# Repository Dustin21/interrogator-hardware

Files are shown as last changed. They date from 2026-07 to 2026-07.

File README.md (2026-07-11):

# interrogator-hardware

**Proprietary & Confidential — © 2026 Dustin. All Rights Reserved.**

Hardware design repo for the [Reality Interrogator](https://github.com/Dustin21/interrogator): the custom PCB(s), enclosure/chassis, footprint & 3D asset library, fabrication packages, and the contract-driven design pipeline that regenerates them when the sensor set changes.

> Status: **planning — v0.1 plan under owner review.** See [`PLAN.md`](PLAN.md) (the build plan) and [`docs/draft-review.md`](docs/draft-review.md) (audit of the original brief vs the interrogator repo + 2026 tooling research).

## Relationship to `interrogator` (the contract)

- The **Unified Sensor Registry** (`interrogator: shared/schemas/sensors/*.yaml`, ADR-0013) is the single source of truth for per-sensor identity/electrical/mechanical facts and versioned asset pins. This repo **consumes it at a pinned SHA — never forks or edits it**.
- This repo binds read-only to the `electrical` + `mechanical` facets and `assets` pins; per-instance placement binds to the device profile view.
- Findings that should change upstream facts are delivered as **resolution packets** (PR-ready proposals); the owner applies them upstream. Single-writer discipline is preserved.
- Heavy binaries (footprints, 3D models, gerbers, renders) live **locally in-tree for now, migrating to AWS S3** (versioned bucket, S3-generic access layer), referenced by `{asset_id, version, sha256}` in a checked-in manifest — the same AssetPin discipline as datasheets. No Git LFS.
- This repo's CI = ERC/DRC (`kicad-cli`), asset-checksum, and contract-pin drift checks. Upstream CI (pytest/contract) is untouched.

## Design stance

**Commercial hardware, clean sheet, chip-down** ([`PLAN.md`](PLAN.md) §0.1): raw sensor silicon on our own board — no breakouts, no dev modules; pre-certified modules only where commercially correct (radio, GNSS). The upstream *contract* binds (registry facets, wire/command semantics); the breadboard *prototype* does not — **interrogator adapts its firmware to this design** against the interface-requirements doc published at H1, and the backend stacks on top. Reference architecture: two-domain compute (NPU-class application MCU + always-on pre-certified BLE/sentinel module), PLAN §5.1.

## Definition of done for the v1 board

(a) The owner's spec scorecard (PLAN §1, R1–R12) against the built device; then (b) the joint integration milestone — the upstream **PCB Gate, [interrogator#7](https://github.com/Dustin21/interrogator/issues/7)**: e2e re-validated on PCB · binary IDL live with text debug mode · diagnostics no-regression vs the breadboard golden baseline · latency budget met.

## Layout (will grow per PLAN.md §7 phases)

| Path | Contents |
|---|---|
| `PLAN.md` | The hardware build plan (source of truth for this repo). |
| `docs/draft-review.md` | Audit: original brief vs interrogator repo + July-2026 EDA tooling research. |
| `docs/MISSING_VENDOR_ASSETS.md` | Proxy-blocked vendor files with exact URLs for manual retrieval. |
| `docs/decisions/` | Lightweight ADRs — the design rationale + invention-capture log. |
| `contract/upstream/` | Pinned, read-only USR snapshot (`PIN.json` records the interrogator commit). |
| `contract/scripts/` | Stage-1 pipeline: `ingest.py` (→ `io_map.{json,md}`), `gen_usr3_packets.py`. |
| `contract/usr3_packets/` | Per-sensor electrical resolution packet drafts (the ingest-package input). |
| `contract/tests/` | Pytest suite — the CI gate. |
| `assets/` | AssetPin manifest + tool (sha256 ledger; local/device now → AWS S3, D10). |
| `library/` | Verified symbols/footprints/3D with AssetPins. *(H2)* |
| `boards/v1/` | KiCad project, fab packages, bring-up docs. *(H2+; CI ERC/DRC auto-activates)* |
| `enclosure/` | FreeCAD/STEP chassis, aperture plate. *(H5)* |

## Toolchain (pinned at H0)

KiCad 10.0.x (`kicad-cli` for ERC/DRC/exports + jobsets) · easyeda2kicad / SnapMagic / Ultra Librarian for verified footprints · Freerouting 2.2.x (grunt nets only, `-inc`-protected) · kicad-jlcpcb-tools for fab packages · FreeCAD + StepUp for MCAD co-design. Trust boundaries in [`PLAN.md`](PLAN.md) §6.2.

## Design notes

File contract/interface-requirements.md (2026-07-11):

# Interface requirements -> interrogator firmware project (v1 hardware)

The board this repo is building; firmware adapts to this (owner-ratified flow).

1. **Compute**: STM32N657 (app, ESP-class port replaced by STM32 port; Neural-ART available) + nRF54L15 module (sentinel, Zephyr/nRF Connect). Inter-MCU: UART (CRC8 framing may carry over) + shared GPIO wake lines.
2. **Buses**: VL53L8CH + BNO086 on SPI+DMA w/ INT; I2C-A (MLX90642, MAX30102, AS7058, ADS131M04-SPI actually -> ADS on SPI2); I2C-B (BME688, SGP41, BMV080, TCS3448, AS7331, MMC5983MA, TMAG5273, IQS7222A); I3C capable pins reserved. GNSS on UART+PPS to input-capture. Wi-Fi via SDIO (ESP-Hosted-MCU).
3. **INT/data-ready wired for every sensor that has one**; FIFO watermark reads; GPS-PPS disciplined timestamps (utc = monotonic + gps_offset contract preserved).
4. **Power domains** (firmware-controlled load switches): OPTICAL, AIR(+fan), CONTACT, RF-WIFI, GNSS, RADAR. Ambient = sentinel + duty-cycled N657. Command surface should map SET_*_RATE + domain on/off.
5. **Wire contract**: binary IDL (ADR-0004) target; text debug mode; ~25-100 KB/s budget unchanged; BLE control plane + Wi-Fi bulk (WebRTC-class transport terminated app-side).
6. **Sensor set deltas** (ingest package to registry): MLX90642, VL53L8CH, TCS3448, BNO086, MMC5983MA, MIA_M10Q, IQS7222A, ADS131M04, AS7058 new records; AMG8833/AS7263/MPR121/NEO_M9N/ADS1115/VL53L8CX/AS7343/BNO085 deprecated-by-successor.
7. **OTA**: A/B slots, signed images, sentinel-rooted identity; feature-gate hooks.

## 8. Interference matrix handoff (owner Q 2026-07-11)
The interference matrix (docs/interference-matrix.yaml) is a physical property of THIS board —
authored here, ENFORCED in interrogator. Ships downstream via the ingest package, referenced by
the device profile (single-sourced; firmware/edge LOAD it, never hardcode) so it can't drift.

Two consumers, routed by each rule's enforcement_tier:
- **firmware_reflex** (sub-100ms, deterministic): tdm / mutex / stagger / gate — emitter↔receiver
  TDM, haptic↔precision mutex, MMC↔TMAG stagger, WiFi-gate during GNSS RAWX. Firmware must load
  these + emit state flags per record.
- **edge_policy** (active-sensing agent): scheduling that avoids masking interactions + confidence
  weighting from flags; may also deliberately exploit couplings (active illumination).
- **design_time** (not runtime): material_exclusion, light_tight_cavity, dedicated_aperture,
  spread_spectrum, shield, keepout, zoning, cal — owned by HW/materials/factory, listed for traceability.

### Record-schema delta interrogator must add (ADR-0001)
State flags ride every record for downstream confidence weighting. Existing prototype flags:
motors_active, wifi_active, leds_active, valve_active. **New for v1: `charging`, `docked`,
`haptic_active`, `uv_active`.** These are the ingest-package's schema asks; we specify, upstream lands.

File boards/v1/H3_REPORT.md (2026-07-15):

# H3 report — rail ECOs, floorplan repack, board rebuild, routing

**Date started:** 2026-07-12 · Grows stage by stage (H3.0 rail ECOs →
H3.1 repack → H3.2 board rebuild → H3.3 routing).

## H3.0 — rail ECOs (1.8V IO architecture + flagged ECO-H3 items)

### H3.0-1 · 1.8V IO architecture decision

**Question:** can the shared sensor SPI bus (SPI1: VL53L8CH, A121, BNO086,
ADS131M04) run entirely at 1.8V from a 1.8V N657 VDDIO domain, eliminating
SPI level shifters?

**Answer: no — and the minimum-shifter architecture needs exactly one 4-bit
shifter.** The device-side voltages would allow an all-1.8V bus (VL53L8CH
IOVDD 1.2/1.8V-only; A121 VIO 1.8-or-3.3V; BNO086 VDDIO 1.7-3.6V; ADS131M04
DVDD accepts 1.8V), but the host side does not: on the VFBGA142 the SPI1
balls (PA5/PB4/PB5) and all four CS GPIOs live in the **VDD general-GPIO
supply domain** (DS14791 Table 18 fn1 — one OPT124 bit 17 / VDDIOVRSEL
setting for the whole domain). VDD could legally run at 1.8V (DS: 1.71-3.6V),
but it also supplies the BL54L15 UART/wake pins (sentinel is hard-wired to
the 3.3V AON rail — nRF54 VIH 0.7·VDD = 2.31V), both I2C buses (BME688 etc.
VIH 0.7·3.3V), SWD, and the EN/interlock fabric. Dragging all of that to
1.8V costs far more translators than it saves. The VFBGA142 bonds only two
other IO domains: VDDIO3 (1.8V, the XSPI PN port — no SPI/I2C AFs) and
VDDIO4 (3.3V, the SDMMC group consumed by the ESP32-C6, whose module IO is
3.3V). There is no relocation target for SPI1.

**Chosen architecture** (fewest translators, gating story intact):

| Item | Decision |
|---|---|
| SPI1 bus | stays 3.3V (BNO086, ADS131M04, A121-VIO side unchanged) |
| VL53L8CH SPI branch | **1× TXU0304** fixed-direction shifter (SCLK/MOSI/NCS ↓, MISO ↑); VCCB = gated 1V8_OPTICAL → B-port Hi-Z when the domain is off (doubles as bus isolation) |
| VL53L8CH INT/LPn | **no shifter** — moved to the N657's two spare **VDDIO3 (1.8V) PN-port balls**: INT_VL53 → PN7 (F14, ex XSPIM_P2_NCLK, unused with a single-ended NOR), LPN_VL53 → PN12 (K14, ex XSPIM_P2_NCS2). PE8/PG10 returned to the spare pool. PN7 is boot-ROM-touched (Table 18 fn7) but only as an XSPI clock output against our open-drain INT + 47k pullup while OPTICAL is off at boot — benign. INT pullup → 1V8_OPTICAL; LPn gets a 100k pulldown (defined-low until PN12 is configured). |
| TCS3448 I2C (1.8V-only SCL/SDA) | **1× PCA9306** segment of I2C-A (see H3.0-3) |
| A121 | VIO stays 3.3V (3V3_RADAR) → SPI/INT/ENABLE stay direct; only VDIG/VRX/VTX move to 1V8_RADAR |
| N657 OPT124/VRSEL fw config | VDD=3.3V (bit 17), VDDIO3=1.8V (bit 15), VDDIO4=3.3V (bit 14) — recorded in lib_parts.py |

Total translator count: **2 small ICs** (TXU0304 TSSOP-14, PCA9306 VSSOP-8)
versus ≥4 for an all-1.8V SPI1 (UART + I2C-A + I2C-B + EN fabric shifting).

**Real bug found while executing:** the VL53L8CH model had **no CORE_1V8
pin** — DS14310 §3.3 p11 requires all THREE supplies (AVDD 3.3V, CORE_1V8
1.8V, IOVDD 1.2/1.8V) or the device stays in reset; and the old wiring fed
IOVDD from 3.3V, over its 1.2/1.8V-only rating. Fixed: CORE_1V8 pin added,
IOVDD+CORE_1V8 → 1V8_OPTICAL (DS explicitly allows sharing when IOVDD=1.8V;
supplies may come up in any order, so the 3.3/1.8 gated pair needs no
sequencer).

### H3.0-2 · Gated 1.8V sub-rails

Three TPS22916 load switches added off the 1V8 rail, driven by the SAME
EN_* nets as their 3.3V siblings (AI-decides-what-runs invariant holds at
both voltage levels):

| Rail | Loads | EN |
|---|---|---|
| 1V8_OPTICAL | VL53L8CH IOVDD+CORE_1V8, TCS3448 VDD+GPIO strap, PCA9306 VREF1, TXU0304 VCCB | EN_OPTICAL |
| 1V8_RADAR | A121 VDIG/VRX/VTX bundle | EN_RADAR |
| 1V8_AIR | ENS161 VDD (core) | EN_AIR |

Side benefit: ENS161 core+VDDIO now rise/fall together (closes the H2
power-sequencing note — its core used to sit on the raw EN_N6-gated 1V8
while VDDIO was AIR-gated). **MAX30102 exception (deliberate):** its VDD
stays on the raw 1V8 rail — with VLED_P hard-gated the part can neither
emit nor sense, shutdown draw is ~0.7 µA, and the DS tolerates any supply
order; a fourth switch buys nothing (documented in sensors_i2c.py).

Power budget: 3× TPS22916 ≈ 2 µA IQ each when on, ~10 nA off; PCA9306 ≈ 0,
TXU0304 static ≈ 1 µA — total adder <7 µA, below the 10 µA resolution of
the budget model (`misc/regs` line unchanged; noted in docs/power-budget.md
regen at H3.1).

### H3.0-3 · TCS3448 1.8V I2C segment

**Chosen: PCA9306 pass-FET translator on I2C-A** (not a 1.8V I2C controller
domain). Reasons: (a) the VFBGA142 bonds no I2C on any 1.8V-capable ball
group — I2C1 is absent, I2C2/I2C4 balls are in the 3.3V VDD domain, and the
only 1.8V domain (VDDIO3 = PN port) has no I2C AF; (b) the address table
forces I2C-A membership — TCS3448 is fixed 0x59, which collides with SGP41
(fixed 0x59) on I2C-B (the exact reason it moved to I2C-A at H2.5). Wiring:
VREF1 → 1V8_OPTICAL, segment pullups 2×2.2k → 1V8_OPTICAL (Fm+ capable),
EN+VREF2 node driven by **EN_OPTICAL** with 200k to 3V3_SYS (PCA9306
switched-EN application) — the dead 1.8V segment is isolated from the live
3.3V bus whenever the OPTICAL domain is gated off. TCS3448 INT stays on the
3.3V side unshifted (3.6V-tolerant per DS001121 p9; N657 PF7 needs 3.3V VIH).

### H3.0-4 · IQS7222A touch flex (ratified)

v1 flex = **9 self-cap electrodes** (QFN20 exposes only CRx0-7+CTx8):
dish ring 2, rim slider 3, side-squeeze 2 (one per wall — "squeeze both
walls" gesture unchanged), back ECG-return/grip 1, reserve 1; dropped = 2nd
reserve pair + per-wall squeeze redundancy (3 of 12 zones). Flex connector
keeps 13 positions, E9-E11 grounded as guards → a v1.1 **mutual-cap Rx/Tx
matrix flex** restores >12 zones on the same connector with artwork+firmware
only. Recorded in docs/user-experience.md + accessory.py.

### H3.0-5 · VD66GY camera module rails (ratified)

The camera **module carries local 2.8V (VANA) and 1.15V (VCORE) LDOs** on
its flex; J_CAM stays 3V3_OPTICAL + 1V8 + 2-lane CSI + CCI, and reserved
pins 19-24 stay reserved (not repurposed as rail feeds). DNP in v1.
Recorded in sensors_misc.py.

### H3.0-6 · Other ECO-H3 grep results

- gen_footprints.py BL54L15/A121 keep-out notes and the SGX-4CO gas_b
  envelope note → floorplan items, executed at **H3.1** below.
- Observed gap (flagged, NOT executed — not an ECO-H3 tag): the UX spec
  asks for BNO086 INT routed to BOTH N657 and sentinel (motion wake from
  ambient), but the BL54L15's 39 pads are fully allocated; the only
  candidates are the NFC pads (P1.02/P1.03, NC in v1). Owner call for
  H3.2 whether pad 15 (P1.02) becomes BNO_INT_IN — zero-cost on the flex
  side, costs the v1.1 NFC option.

**H3.0 gate:** ERC **0 errors / 0 warnings**, netlist regenerated
(387 parts, 229 nets), tests 19/19 (see commit).

New nets: 1V8_OPTICAL, 1V8_RADAR, 1V8_AIR, I2CA_SDA_1V8, I2CA_SCL_1V8,
VL53_{SCLK,MOSI,NCS,MISO}_1V8. New parts: U_SW1V8_{OPTICAL,RADAR,AIR}
(TPS22916), U_LS_VL53 (TXU0304, **pinout E0** — DS not staged, see
docs/MISSING_VENDOR_ASSETS.md), U_XLAT_TCS (PCA9306, **pinout E0** — DS not
staged), + pullups/pulldown/decoupling.

## H3.1 — floorplan repack with real E1 envelopes

Pack result: `python3 boards/v1/design_v1.py` → **OK, 41 parts, zero
collisions, full bean-polygon containment** (bean 67.9×39.9 bbox, 2065 mm²).
Regenerated: components.json, floorplan_top/bottom.svg, envelope.json,
docs/power-budget.md.

### Envelope updates applied (E0 guess → E1 datasheet)

| Part | was | now | consequence |
|---|---|---|---|
| SGX-4CO | 14×14, z 4.0 | **17×17** (13.5 PCD ring + Ø1.7 socket drills + courtyard), **z 18.0** (16.5 can + ~1.5 socket standoff) | gas_b zone grown to 18.5×17.2; the Ø20 can stays fully ON-board at this position (no edge overhang needed). **NEW MECHANICAL FLAG** below. |
| AS7421 | 3.5×3.5 | **6.6×6.0** (OLGA10, DS000667 p45) | optical2 row rebuilt (now 23.6 wide) |
| BL54L15 | 14×10 "antenna long-edge at rim" | **10×14, antenna END at rim** — EZ-DS v1.9 Fig 11: the 5.0×8.5 keep-out sits at the pin-1 END across the 10 mm width, so the module's long axis must be perpendicular to the board edge, antenna end outboard | radio_ble zone reshaped to 11.6×14.8 at the +y smooth rim (x 25.0-36.6, the bean's widest arc). Keep-out ≥15 mm extension = off-board air; on-board keep-out lies under the module's own antenna end — no other part in it (collision check) and **no copper pour there at H3.3** (rule recorded here + in the footprint). Module top edge packs 0.8 mm (GAP) inboard — H3.2 slides it flush onto the edge. |
| BQ25620 | 2.5×3.0 ✓ | (already WQFN-18 RYK since H2.5) | — |
| MLX90632 | 3×3 ✓ SFN5 | — | — |
| MLX90642 | 9.6×9.6 ✓ (TO-39 Ø5.84 pin circle E1 from H2.5) | — | — |
| MIA-M10Q | 4.5×4.5 ✓ | note updated: SR4G013 GNSS antenna keep-out at the fat-notch edge (IM UBX-21028173) — antenna is a supporting part placed at H3.2, corner reserved |

### New parts placed (H3.0 adds)

- **48 MHz HSE crystal** (3225) — compute zone, packed directly right of the
  N657 (0.8 mm gap; PH0/PH1 = balls A7/B7 — orient at H3.2).
- **3× TPS22916 1V8 sub-rail switches** — folded into the power-row strip:
  "Load switches x7" → **"Load switches x10"** (9.5 → 13.6 mm strip).
- **TXU0304** (TSSOP-14, 6.4×5.4 courtyard) — optical zone, row below the
  FIR/cam row, near the VL53L8CH branch it shifts.
- **PCA9306** (VSSOP-8, 3.1×2.4) — optical2 row, beside the TCS3448 segment.

components.json parts 38 → **41**; manifest 41/41 (23 harvested + 5 E0 +
13 E1 generated); contract test snapshot updated 38→41 and extended with the
H3.0 refdes (U_SW1V8_*, U_LS_VL53, U_XLAT_TCS, X_HSE) + 1V8 sub-rail nets.

### Zone deltas

gas_b 16×15.5 → 18.5×17.2 (+63 mm²); optical 28×10.6 → 28×16.2 (absorbs the
TXU row; overlaps rad_top zone RECT but not its parts); optical2 17×4.3 →
23.6×6.4 (AS7421 + PCA9306); radio_ble 15.5×10.5 → 11.6×14.8 rotated to the
rim; compute 20×9.3 → 22.5×8.8 (single row N657+crystal+NOR, dropped below
the BL54); power 20.5×10 → 22×8.2 two-row layout; io shifted to
(8.0,4.2,13.5,5.8). Top/bottom faces both still pack with 0.8 mm courtyard
gaps everywhere (collision check global, eps 0.02).

### Pack stats / power budget

- Part-envelope area: top 602 mm², bottom 921 mm² over 2×2065 mm² faces
  → **37 % gross envelope utilization** (was ~29 % pre-H3.1; the SGX ring
  +63 mm², AS7421 +27 mm² and the three new ICs drive the growth).
  Passives/TPs/routing absorb the rest — H2 stage-2 already measured the
  passive-placement debt.
- Power budget regenerated: ambient **21.6 mA → 56 h** (8 h target cleared
  ~7×), interrogation **457 mA → 2.6 h** — unchanged; the H3.0 adders
  (3× TPS22916 + PCA9306 + TXU0304, <7 µA) are below model resolution and
  noted in docs/power-budget.md.

### NEW MECHANICAL FLAG (owner + enclosure): SGX-4CO height

envelope.json stack is now honest and reads **26.1 mm** (1.6 board + 6.5
SCD41 top + **18.0 SGX bottom**) against the 19 mm interior target — the H2
value (12.1 mm) was carrying the stale 4.0 mm cell-height guess. DS-0138:
can Ø20 × **16.50** + 3.9 mm pins; with socket receptacles the body sits
~18 mm proud of the board. Even alone, 1.6 + 18.0 = 19.6 mm > 19 mm. The
cell CANNOT stand inside the pebble unless the enclosure gives it a local
pocket/dome in the bottom-fat-lobe gas cavity (the vent area already has no
top-face parts opposite: contact/optical zones sit off its x-span — local
opposing stack is board + cell only). Enclosure owner actions (pick one at
H3.2): (a) local interior pocket ≥18 mm at gas_b (bulge into the 1.6 mm
wall/1.9 mm clearance budget), (b) right-angle socket adapter laying the
can down (costs ~Ø20×17 of adjacent board area), or (c) low-profile CO cell
substitution (breaks the ratified SGX-4CO pick). Flagged, not resolved here.

## H3.2 — board rebuilt placement-true, all pads net-bound

**Gate results:** `build_board.py` → 400 footprints placed, **fixed-packed=66
(55 floorplan slots), anchor-spiral=334, overlap-fallback=0 (hard build
gate)**; pads **bound=1379 / declared-NC=192 / unnumbered mech-paste=34**,
netlist pins covered **1362/1362** (zero lost, zero undeclared-unbound —
both hard gates; ledger = `boards/v1/netlist/nc_pins.json`, generated by
`circuit/main.py`, every entry justified at the model). ERC 0/0; 19/19
tests; DRC baseline: **0 footprint errors, 0 courtyard overlaps, 0
clearance, 0 malformed pads; unconnected = 499 (honest pre-route
ratsnest)**; waived: 4× hole_clearance inside the official GCT USB4105
footprint (its own NPTH pegs vs our 0.25 rule); known-open: 47×
items_not_allowed from the Espressif C6 footprint's all-layer antenna
keep-out vs the ratified taper floorplan (ECO-H3.2-E, owner call); silk
noise 735 items counted, deferred to H4.

### What the zero-overlap gate surfaced (all fixed in design_v1.py)

1. **The mechanical set had NO floorplan slots at all** (H2 grid-placed
   them into overlaps). New MECH auto-slot stage packs 14 more parts:
   USB-C, GNSS antenna, pogo field, touch ZIF, U.FL, 3× ECG lands, piezo
   lands, battery conn, 2× SWD, LRA pads, fan conn — deterministic spiral
   placement with 0.4mm gaps (their envelopes are true courtyard extents)
   and per-through-feature other-face checks.
2. **Every H2 envelope was body-sized, not courtyard-sized** (audited via
   pcbnew): e.g. DRV2605L 3×3 body vs 6.4×3.6 courtyard-with-leads,
   IQS/ADS 3×3 vs 4.3×4.3, CYPD 4×4 vs 5.3×5.3, gauge 1.6² vs 3.7².
   All 41 envelopes replaced by audited extents; GAP 0.8 → 0.5 (now a true
   courtyard-to-courtyard margin). Zones reshaped: contact split
   (ppg/contact — the SGX through-pad annulus lands mid-lobe), air split
   (column + SCD island + BMV shelf — the USB through-features own the
   face behind the old air block), MLX90632 → own taper window (fir2),
   DRV2605L → top notch, MIA-M10Q → dedicated RF-corner zone, load
   switches → own strip, camera slot = the real 18.4mm FH12-24 connector
   (VL53 moved to the TXU row).
3. **Capacity ECOs (owner ratify, all electrically transparent):**
   ECO-H3.2-A: ECG electrodes → 4mm board LANDS + shell electrodes
   (elastomer/spring through the 3.5mm wall — direct skin contact was
   never physical); pogo → 2×3 landing field, ADR-0002 mag-ring geometry
   moves to the shell; ECO-H3.2-B: **USB-C sits mid-back** (35.9–46.6,
   25.1–34.1 bot) — the notch edge belongs to the power zone; enclosure
   needs a USB tunnel or H4 relocation; ECO-H3.2-C: J_RF SMA → U.FL +
   shell pigtail; J_TOUCH → 0.3mm Molex 503566 ZIF (same P/N as BMV080);
   ECO-H3.2-D: TC2030 ×2 → plain 1.27mm SWD pad rows (NPTH locating holes
   had no both-face-clear window); piezo disc mounts shell-side onto
   compact lands; testpoints 1.0 → 0.7mm.
4. **Cross-face honesty:** TH/NPTH pads now block BOTH occupancy grids;
   U_CO receptacle marks derive from the real (flipped) pad positions;
   footprints are placed by COURTYARD CENTER (connector origins are not
   their courtyard centers); fixed slots auto-rotate to match slot aspect
   (U_MAX OLGA-14 was 90° off in H2).
5. **Under-can/shield reclaims:** the SGX cell plugs onto ≥1.5mm PSB
   receptacles → the Ø20.9 under-can region accepts 0402/0603 dust
   (low-profile mask); the radiation shield interior accepts only
   radiation-front-end nets. NOTE: the N657's left ~1.2mm slips under the
   SGX can RIM (1.2mm part vs ≥1.5mm standoff) — flagged for the
   receptacle-height check at H4.

### Board setup

6-layer (JLCPCB 6L through-via + POFV), default netclass 0.1/0.1, edge
clearance 0.2, min track/clearance floor 0.09 (BGA fanout). Netclasses
seeded in the **committed** `interrogator_v1.kicad_pro` (checked: CI's eda
glob does not reach boards/v1/board/): PWR (0.25 track), USB_HS (90Ω diff
placeholder 0.13/0.15), CSI (100Ω placeholder 0.11/0.15), RF (50Ω
placeholder 0.3), BGA_FANOUT 0.09/0.09 + pattern assignments; the
VFBGA142 area rule lives in `interrogator_v1.kicad_dru`. Diff geometry is
a PLACEHOLDER until the H3.3 impedance calc against the ratified stack.

BL54L15 flush on the +y rim (design_v1 `flush_bl54`, containment exemption
on its rim edge; rotation auto-selected so the antenna keep-out points
off-board); MIA-M10Q at its RF corner with AE_GNSS on the top arc rim;
SGX fully on-board (H3.1 analysis stands — coordinator's "can overhang"
allowance not needed).

Renders: `board_top.svg` / `board_bottom.svg`. DRC: `drc_baseline.{json,rpt}`.

## H3.1R — board-first minimal floorplan (ADR-0004: bean containment removed)

**Pivot (2026-07-15, owner):** the Product-Stone bean is no longer a hard
board boundary. Every H2/H3 placement + routing crisis (courtyard overflow,
33-part spill, the USB-C enclosure tunnel, and the H3.3 routing stall at
XSPI 9/11 + partial diff pairs) traced to cramming the board into the
67.9x39.9 bean, whose curved edges have no straight routing channels. The
PCB outline is now an OUTPUT of minimum-area packing; chassis is derived
downstream. Recorded in **ADR-0004** (supersedes the board-containment
aspect of ADR-0003).

`design_v1.py` rewritten board-first:
- FFDH shelf-pack of the real footprint courtyards (41 majors + 14 mech)
  per face; interior width swept for the minimum shared board (aspect <=1.55).
  Per-face FFDH => **zero same-face courtyard overlap by construction**.
- Board interior = packed core + 2.6 mm passive/route ring; outline = a
  rounded rectangle (R=2, 68 pts) written to `outline.json` (DERIVED,
  replaces the bean).
- Edge-critical parts carry an `EDGE:{S,N,W,E}` tag (USB-C short edge,
  BL54/ESP32/MIA RF edges, SGX inlet, SMA/pogo/battery) flowed to
  build_board for flush-to-edge so RF keep-outs extend off-board.

**Derived board: 47.7 x 44.7 mm = 2129 mm2** (103% of the 2065 bean by
area, but fully rectangular). All 55 rectangles pack collision-free,
containment-clean, **zero spills**. Stack 26.1 mm (unchanged — SGX height
flag stands). Power budget unchanged (ambient 21.6 mA -> 56 h, interrogate
457 mA -> 2.6 h). The win is routability (straight channels every layer,
no enclosure tunnels), not raw area — the part set genuinely needs
~2000 mm2/face, which the bean also gave but un-routably.

Battery is a mating/stacked part (LP503450-class 50x34x5.2 mm via J_BATT) —
excluded from board area, noted in `envelope.json`.

## H3.2R — board rebuilt placement-true on the liberated floorplan

`build_board.py` generalized off the hardcoded 68x40 bean grid to the
derived outline bbox (occupancy grid + spiral offsets now sized from
`outline.length_mm x width_mm`), then run on the ADR-0004 rectangle.

**Placement:** 66 fixed-packed (41 majors + 14 mech + co-placed refs) at
their components.json slots; 334 anchor-driven spiral (weighted-neighbour
centroid, 0/90 rotation, dust-under-SGX + shield-interior masks honored);
**overlap-fallback = 0 (hard-gated — a spill EXITS 1)**. Faces: 191 top /
209 bot.

**Pad binding (hard gate):** bound **1362 / 1362** netlist pins (= the full
pin count); 192 declared-NC (nc_pins.json ledger, each justified at the
model); 34 unnumbered mech/paste pads (NPTH + EP apertures). Zero
undeclared unbound pads, zero netlist pins without a pad.

**Board setup:** 6-layer (JLCPCB 6L through-via + POFV), default 0.1/0.1,
edge clearance 0.2, min track/clearance floor 0.09; net classes (PWR / USB_HS
90R / CSI 100R / RF 50R / BGA_FANOUT 0.09) + patterns seeded in the committed
`.kicad_pro`; VFBGA142 area rule in `.kicad_dru` (carried from H3.3a).

**DRC baseline** (`drc_baseline.{json,rpt}`, pcbnew WriteDRCReport):

| category | count | note |
|---|---|---|
| **Footprint errors** | **0** | acceptance |
| courtyard overlaps | **0** | per-face FFDH + spiral hard-gate |
| malformed-pad errors | **0** | |
| unconnected pads (ratsnest) | **499** | honest pre-route baseline (record) |
| silk (overlap/over-copper/lib/text) | 697 | silk noise, OK to remain |
| clearance | 15 | pad-pad <0.1 in dense spiral corners (pre-route) |
| solder_mask_bridge | 10 | adjacent fine-pitch mask slivers |
| silk_edge_clearance | 22 | ref-des silk near the rim |
| hole_clearance | 6 | connector NPTH vs opposite-face dust |
| items_not_allowed | 17 | courtyard/pad near Edge.Cuts on the tight rim |

Renders: `board_top.svg` / `board_bottom.svg`.

**Follow-up before routing (H3.3R):** the 5 EDGE-tagged parts (USB-C→S,
BL54→N, ESP32→E, MIA→corner, AE_GNSS→N) are placed at their packed core
slots, not yet flushed to the rim — trivial to finalize on the rectangle
(vs the bean) so the RF keep-outs sit off-board. The ~38 non-silk geometry
violations are the dense-baseline residue the router pass will clear/relieve.
Gate: circuit ERC 0/0, contract tests 19/19 (unchanged).

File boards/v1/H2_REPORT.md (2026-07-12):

# H2 stage-1 report — complete electrical design as circuit-code

**Date:** 2026-07-12 · **Scope:** SKiDL circuit modules, KiCad netlist, ERC,
component-library manifest. Layout, real pin/ball maps, and footprint
generation are stage-2.

## What was built

`boards/v1/circuit/` — modular SKiDL (Python) circuit, v1.1 sensor set (38
components.json parts + support circuitry):

| Module | Contents |
|---|---|
| `lib_parts.py` | All custom part templates (our symbol source; pin maps tier **E0**) |
| `power.py` | USB-C + CYPD3177 PD sink → BQ25620 charger (SENTINEL_I2C 0x6B) → VSYS; BQ29700+dual-FET low-side 1S protection; BQ27427 gauge; TPS62840→3V3_AON; TPS62823→VDD_CORE_N6; **TPS62823 #2→3V3_SYS (stage-1 add)**; TLV62568→1V8; 6× TPS22916 domain switches + **7th for accessory port (stage-1 add)** |
| `compute.py` | STM32N657 (used-signals model), octal-NOR on XSPI (8d+clk+cs+dqs), BL54L15 sentinel (enables/wakes/glow/SENTINEL_I2C), ESP32-C6-MINI-1 on SDIO (real Espressif symbol) |
| `sensors_spi.py` | VL53L8CH (SPI-strapped), BNO086 (PS1 strap), ADS131M04 (piezo diff AIN0, PIN-rad AIN1, accessory AIN2, CO-AFE AIN3, CLKIN from N657 MCO) |
| `sensors_i2c.py` | Full I2C-A / I2C-B population w/ straps, INT pull-ups, per-domain power + decoupling; collision audit in module docstring |
| `sensors_misc.py` | BMV080, A121 (SPI-only), MIA-M10Q (+V_BCKP diode from AON, PPS→N657), PDM mic, J_CAM 24p FPC (DNP), **PIN radiation front-end** (BPW34S + OPA381-class charge amp + TLV3201 comparator → GEIGER_PULSE to sentinel + energy-proxy to ADS AIN1, SHIELD_RAD guard, powered from 3V3_AON for ambient counting), AD8317+SMA→ADC_IN0, UV LED **hardware-interlocked** (74LVC1G08: EN_UV_REQ ∧ INTERLOCK_OK, VLED on gated 3V3_OPTICAL = second interlock), white LED, AS7421-driven 970 nm NIR LED, 6× glow LEDs, fan FET+flyback from VSYS, SGX-4CO + LMP91000 potentiostat |
| `accessory.py` | 6-pogo magnetic port (VACC/GND/SENTINEL_I2C/AN1=ECG-ref/AN2=ADS), IQS7222A (12 electrodes→FPC), DRV2605L→LRA, 2× TC2030, testpoints |
| `main.py` | Builds all, runs ERC, writes netlist; exit 0 iff ERC-clean |

**Netlist:** `boards/v1/netlist/interrogator_v1.net` — KiCad format, **330 parts,
207 nets**, ~277 KB. Parses (balanced S-expr, verified by test).

## ERC result

**0 errors / 0 warnings** (SKiDL 2.2.3). Three findings closed by justified
`drive=POWER` annotations (RC-filtered protector VDD, cell-negative terminal,
diode-fed GNSS backup rail) — documented in `boards/v1/circuit/WAIVERS.md`.
No suppressed pin-conflict or unconnected-pin issues.

## Address map (bus / addr per device)

| Bus (master) | Addr | Device | Note |
|---|---|---|---|
| SENTINEL_I2C (BL54L15, 3V3_AON pull-ups 4.7k) | 0x44 | IQS7222A | **deliberate**: collides with SHT41 0x44 → moved off I2C-B; also the wake source |
| | 0x55 | BQ27427 | gauge |
| | 0x5A | DRV2605L | haptics |
| | 0x6B | BQ25620 | charger |
| | 0x50 | accessory ID EEPROM | reserved, via pogo |
| I2C-A (N657 I2C1, 1 MHz-capable, 2.2k→3V3_SYS) | 0x33 | MLX90642 | |
| | 0x3A | MLX90632 | |
| | 0x57 | MAX30102 | 1.8 V core; 3V3 bus tolerance **VERIFY** |
| | 0x30 | AS7058 | addr **VERIFY** |
| I2C-B (N657 I2C2, 400 kHz, 4.7k→3V3_SYS) | 0x77 | BME688 | SDO=1 strap |
| | 0x59 | SGP41 | fixed |
| | 0x53 | ENS161 | ADDR=1 strap; VDD on 1V8 |
| | 0x62 | SCD41 | fixed |
| | 0x44 | SHT41 | fixed (IQS collision resolved above) |
| | 0x39 | TCS3448 | **VERIFY** |
| | 0x74 | AS7331 | A1A0=00 |
| | 0x64 | AS7421 | **VERIFY** |
| | 0x30 | MMC5983MA | vs AS7058 0x30: different bus — OK |
| | 0x35 | TMAG5273 | A1 variant **VERIFY** |
| | 0x57 | BMV080 | vs MAX30102 0x57: different bus — OK; addr **VERIFY** |
| | 0x48 | LMP91000 | fixed (CO potentiostat) |

**No same-bus collisions.** SPI1: 4 CS (VL53, BNO, ADS, A121). SDIO: ESP32-C6.
UART1+PPS: MIA-M10Q. UART2: inter-MCU. All INT/DRDY lines wired (R7), incl.
INT_TCS/RDY_AS7331/INT_AS7421/INT_ENS/INT_BMV/INT_TMAG beyond the core set.

## Stage-1 engineering adds/deviations (need ratification + components.json update)

1. **U_SYS3V3 (2nd TPS62823) → 3V3_SYS**: the ratified regulator set had no main
   3.3 V rail; domain switches would have fed raw VSYS (3.0–4.35 V) to 3.3 V
   sensors. EN_N6-gated. Small (SOT-583+L+2C), fits power zone.
2. **U_SW_ACC (7th TPS22916)**: switched accessory-port power (VSYS→VACC, EN_ACC).
3. Radiation front-end on **3V3_AON** so the sentinel counts dose in ambient
   (OPA381-class ~0.8 mA when enabled — firmware duty-cycles; flag for W-PWR).
4. ENS161 core on 1V8 (EN_N6-gated) with VDDIO on 3V3_AIR — power-sequencing
   note for stage-2.
5. Domain rails hang off 3V3_SYS (EN_N6-gated): sentinel must assert EN_N6
   before any EN_domain. Matches duty-cycled-N657 architecture.

## Library coverage (`library/manifest.json`)

- components.json parts: **38** — manifest covers all (tested).
- Footprints harvested: **20/38** (18 kicad-official + espressif C6 + espressif symbol);
  34 `.kicad_mod` files copied under `library/footprints/` (incl. passives/connectors).
- **TO-GENERATE: 18/38** — expected and honest: MLX90632 SFN, VL53L8 module,
  TCS3448/AS7331/AS7421 OLGA, AS7058 WLCSP42, A121 fcCSP, BMV080, SGP41 DFN,
  ENS161 LGA9, STM32N657 VFBGA142, octal-NOR BGA24, BL54L15, MIA-M10Q,
  TPS22916 CSP-4, ADS131M04 WQFN-20, SGX-4CO cell, camera FPC + custom mech
  (pogo ring, electrodes, shield can, piezo, LRA pads).
- Provenance caveat: GitHub mirrors KiCad/kicad-footprints + kicad-symbols are
  **stale 2020 snapshots** (KiCad dev moved to GitLab — unreachable here);
  official files were taken from the Ubuntu-packaged KiCad **7.0.11** libraries
  instead (same official content, versioned). espressif/kicad-libraries cloned
  fine (ESP32-C6-MINI-1 symbol + footprint). SnapEDA/easyeda2kicad/vendor
  portals: blocked, as expected.
- All harvested *generic* footprints (LGA-16/28, QFN-20/24, WQFN-16, DSBGA-9,
  TO-39-4, SOT-583) carry `verify_notes` — pad-map confirmation vs DS is a
  stage-2 gate before layout.

## Toolchain

- **kicad-cli 7.0.11 — INSTALLED and working** (apt, with kicad-symbols +
  kicad-footprints 7.0.11 packages). Available for stage-2 (`kicad-cli` sch/pcb
  export, DRC).
- SKiDL 2.2.3 (pip; kinet2pcb/hierplace extras skipped — need pcbnew python
  bindings at layout stage, kicad package provides them).

## Tests

`contract/tests/test_h2.py`: (a) netlist exists/parses/contains 57 major refdes
+ 22 architecture nets, (b) manifest covers every components.json part with
honest provenance + harvested files exist, (c) `main.py` rebuild is ERC-clean.
**Full suite: 14/14 passed** (11 pre-existing ingest + 3 new).

## NEXT (stage-2)

1. **Pin-map hardening**: replace E0 logical pin numbers with real package
   pins/balls from datasheets (every `# pinout E0` in lib_parts.py); resolve
   all `# VERIFY` items (AS7058/AS7421/TCS3448/BMV080 addresses, TMAG variant,
   MAX30102 bus tolerance, A121 supply domains, C6 SDIO GPIO map, BQ27427
   sense topology, CYPD3177 strap values, charger/regulator dividers).
2. **Footprint generation** for the 18 TO-GENERATE parts (scripted
   `.kicad_mod` writers from DS drawings; MLX90642 TO-39+lens, A121 AiP
   keepout, BL54L15 antenna keepout are the tricky ones).
3. **Schematic/PCB path**: netlist → pcbnew import (kinet2pcb now that KiCad
   is installed) or `.kicad_sch` generation; seed placement from
   components.json x/y (design_v1.py zone-packer).
4. **iBOM / live-priced BOM** (R13): generate interactive BOM with LCSC/DK
   pricing columns.
5. **Ratify stage-1 adds** (3V3_SYS buck, 7th load switch) → update
   components.json + rerun zone-packer + power budget.
6. ERC re-run after pin-map hardening; add antenna/RF review (BL54 + C6 + GNSS
   corner) before layout.

---

# H2 stage-2 report — footprints 38/38, bean board, first .kicad_pcb

**Date:** 2026-07-12 · **Scope:** footprint generation, bean outline + repack,
board-file bring-up (pcbnew), datasheet VERIFY closures.

## 1. Footprint coverage: 38/38, zero TO-GENERATE left

`library/gen_footprints.py` — parametric `.kicad_mod` writers (ball-grid,
dual-row DFN/OLGA, quad QFN/SON, castellated module, TH radial, ring/pad
customs). 24 files generated into `library/footprints/generated/`; every file
header carries its dimension source + the rule *"E0 — overlay-verify against
the vendor land-pattern drawing before fab"*. All 24 load in pcbnew 7.0.11.

- **From staged datasheets** (best tier): A121 fcCSP50 with the **real named
  50-ball map** (DS p8-9), VL53L8 LGA16 with real pad names (DS14161 Table 3),
  SGP41 DFN-6 (2.44/0.8 + die pad, DS p18), BMV080 host side = **Molex
  503566-1302 ZIF 13ckt 0.3 mm** (DS p16), AS7331 OLGA16 body dims,
  TCS3448 = AS7343-family OLGA-8.
- **E0 placeholders (flagged in-file)**: STM32N657 VFBGA142 (numeric 12×12
  fill — must be replaced from DS14791 **before routing**), AS7058 WLCSP42,
  NOR BGA24, BL54L15 castellations, MIA-M10Q perimeter, TPS22916 CSP4,
  MLX90632 SFN, ENS161 LGA9, AS7421 OLGA10, AD8317 LFCSP8, SGX cell, customs.
- **Remapped to KiCad-official instead of generating** (per-part in
  manifest): ADS131M04 → generic QFN-20 3×3 P0.4; camera FPC + touch FPC →
  Hirose FH12-24/13; OPA381 → MSOP-8; LMP91000 → WSON-14 4×4 (exact class
  match); GNSS antenna → Antenova SR4G013.
- `library/manifest.json`: **22 harvested + 16 generated-E0 = 38/38**,
  `footprint_to_generate: 0` (tested).

## 2. Bean board — outline + repack

- `boards/v1/outline.py` → `outline.json`: Product Stone plan
  (enclosure/product_stone.py `w_smooth`/`w_notch`) inset **3.5 mm**
  (1.6 wall + 1.9 clearance) via shapely round-join buffer; resampled to a
  **96-point closed polygon**. Board bbox **67.9 × 39.9 mm**, area
  **2065 mm² = 75 % of the old 60×46 rectangle** (recorded in envelope.json).
- `design_v1.py`: zones re-mapped onto the bean — optical + contact on the
  fat-lobe face, air pocket mid with **SCD41 top-mid**, taper tip = A121
  radar + magnet edge sensors, **SGX-CO (14×14) bottom fat lobe**, compute +
  power bottom mid, C6 bottom taper (antenna toward tip), BL54L15 rotated 90°
  with its antenna edge on the smooth rim. The **PIN radiation block moved to
  the TOP face** (bottom fat lobe is consumed by the SGX cell; gamma doesn't
  care). Packer gained a **polygon-containment check** (every part rect +0.8
  margin fully inside the bean; violation raises). Pack passes; SVGs now draw
  the bean outline. Stack 12.1 mm (unchanged parts). Power budget untouched
  (same part set).
- Real finding for H3: at 2065 mm²/face the bean is tight — the 284
  passives/TPs/connectors do NOT all fit at conservative shelf spacing
  (see §3 overlap debt).

## 3. Board file — `boards/v1/board/interrogator_v1.kicad_pcb`

- **Path A (pcbnew scripting)**: `kinet2pcb` does not build here (Debian
  setuptools `install_layout` regression in its 2020-era setup.py), but the
  pcbnew 7.0.11 python bindings are present — `build_board.py` does the same
  netlist→board conversion directly: parses the netlist, loads every
  footprint (repo libs + generated + official fallback), places the 38
  majors at their bean-floorplan coordinates (refdes↔part table; bottom
  parts flipped), greedy-grid-places the remaining 284 parts inside the
  bean, binds **1019 pads to nets** by (ref, pin), and draws the 96-segment
  Edge.Cuts bean. 392 pads stay unbound where E0 logical pin numbers don't
  match real package pad names (A1-style balls) — H3 pin-map hardening.
- Placement debt: **77 parts** (TPs + decoupling caps + the 3 big mech items
  pogo-ring/ECG-ring/SMA) only fit via the containment-only fallback —
  inside the bean but courtyard-overlapping primaries. That is the DRC noise
  band below and the first H3 work item.
- **DRC baseline** (`run_drc.py` → `drc_baseline.json`): kicad-cli **7.0.11
  has no `pcb drc`** (KiCad 8 feature) — DRC runs through the same engine via
  `pcbnew.WriteDRCReport`; `kicad-cli pcb export svg` passes as load-proof.
  Counts: **unconnected pads 499** (the routing todo — expected, no tracks),
  **Footprint errors 0**, violations 1389 = courtyard/silk/clearance overlap
  noise from baseline placement (309 clearance, 154 courtyards_overlap,
  199 silk_overlap, …) + 45 items_not_allowed + 30 text_height.
- **No `.kicad_pro` created on purpose** — CI's eda job gates on `*.kicad_pro`
  and routing hasn't happened; arming it now would fail the pipeline
  honestly-but-uselessly.

## 4. VERIFY closures (see boards/v1/VERIFY_LOG.md)

**Closed from staged PDFs (11):** BMV080 addr 0x57 + PS/CSB/MISO straps
(**bug fixed** — old model's GND strap selected SPI); MAX30102 6 V-tolerant
pins → 3V3 bus OK; **A121 rails: VRX/VTX/VDIG 1.8 V-only → ECO-H3** (+ SPI
50 MHz mode 0); TMAG5273A1 = 0x35 (full variant table); BNO085 PS1/PS0
straps + 0x4A/0x4B; VL53L8CX SPI strap = C1 to IOVDD (no I2C_RST pin exists;
**IOVDD 1.2/1.8 V-only → ECO-H3**); AS7331 0x74 strap math; BME688 0x77;
SGP41 0x59; TCS3448 0x39 anchored to AS7343 DS (partial).

**Still open (16)** — each listed in VERIFY_LOG.md with the exact PDF to drop
into `registry_assets/<PART>/datasheet/`; the routing-blocking one is
**DS14791 (STM32N657 ball map)**.

## 5. Tests

`contract/tests/test_h2.py` extended: manifest 38/38 + no TO-GENERATE, every
manifest footprint file exists, generated files carry the E0 header, bean
outline valid closed polygon with 1500–2600 mm² sanity, board file loads with
Edge.Cuts + ≥30 footprints + DRC baseline captured. **Full suite: 19/19
passed** (11 ingest + 8 H2).

## H2.6 update (2026-07-12) — N657 ball map landed, board file now STALE

DS14791 Rev 9 arrived: the STM32N657 model was rebuilt on the **real 142-ball
VFBGA142 map** (Table 18) and `ST_VFBGA142_PLACEHOLDER` (numeric 12×12 grid —
wrong ball count layout AND wrong refs) was **deleted**, replaced by
`generated/ST_VFBGA142` (E1, 15×15 A-R×1-15 sparse grid). Consequence:
**`board/interrogator_v1.kicad_pcb` is stale** — it still embeds the
placeholder footprint and pre-H2.6 netlist. Do NOT trust it; rebuilding via
`build_board.py` is H3's first act (per plan). Netlist + ERC + tests are the
source of truth in the meantime. Also landed in H2.6: real VDDCORE plan
(0.81 V boot / 0.89 V VOS-high via `N6_VCORE_SEL`), `PWR_ON`-gated core buck,
VDD-first rail sequencing, HSE crystal add, three buck FB-divider value bugs
fixed (core would have received **1.145 V** — over the 0.921 V max),
VL53L8CH closed on its own DS (DS14310), VD66GY captured (DNP notes).
AN5967 (N6 hardware getting-started) and AN5897 (VL53L8 integration) are the
two remaining app notes worth staging before H3 fanout (cap counts,
via-in-pad, land fine print).

## NEXT (H3 routing)

1. ~~Drop in DS14791 → replace `ST_VFBGA142_PLACEHOLDER`~~ **DONE at H2.6**
   (real ball map, E1 footprint). First H3 act: re-run `build_board.py`
   against the new netlist/footprints (board file stale, see above).
2. Execute the two ECOs: A121 VDIG/VRX/VTX → 1V8; VL53L8CH IOVDD/CORE_1V8 →
   1V8 (level-shift or run SPI1 domain at 1.8 V).
3. Placement refinement: absorb the 77 overlap-fallback parts (decouplers to
   their owners' back side, TP field consolidation, pogo/ECG rings to their
   ADR positions), then route: 499 unconnected → 0.
4. Antenna/RF review at the bean edges (BL54 rim, C6 tip, GNSS notch corner).
5. Create the `.kicad_pro` only when routing starts (arms CI eda job).

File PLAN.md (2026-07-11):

# Interrogator Hardware — Build Plan

**Status: v0.2 DRAFT — incorporates owner review of 2026-07-11.**
Owner: Dustin21 · Repo: `interrogator-hardware` · Tracker: [Project 3](https://github.com/users/Dustin21/projects/3) (populated after ratification)

This plan merges the owner's brief ("Closed-Loop AI EDA Pipeline for Ultra-Dense Interrogator Device"), the owner's v0.1 review comments, a read-only review of the `interrogator` repo, and July-2026 AI-EDA tooling research. The v0.1 audit trail lives in [`docs/draft-review.md`](docs/draft-review.md).

---

## 0. Mission

Build the **iPhone of the sensor world**: a sleek, minimalist, handheld multi-modal sensing device — a *scientist in your pocket* — whose hardware works cohesively and reliably for years, competes with top technology companies, and is patentable. Not hobby tech.

The device is, conceptually, a **sensor MCP**: add a sensor and the system's raw streams and interrogation capabilities expand — the agent immediately knows more about reality. The hardware's job is to make that expansion cheap (fast respins, stable chassis) and the signal path pristine.

**Target markets (owner, 2026-07-11)** — near-term reachable, many out of the box: home & consumer · building & facilities · health & wellness · public safety · environmental · industrial & resources · agriculture & food · transportation · government & defense. One hardware platform, many intent catalogs: the H1 sensor market scan (§5.7) scores parts by *cross-vertical* information yield, and the SKU levers (DNP variants, feature gating §5.10) let one board family serve B2C and B2B without forking the design.

**P0 — Signal fidelity first.** Whatever we add, the signal of reality stays optimized and unencumbered. The device's success is measured by how accurately, sensitively, and at what range a handheld can extract information and fuse it into decisions. Every enclosure material, aperture, window, filter, gasket, keepout, and power rail is designed *from the sensing physics inward* — nothing may attenuate, distort, heat, or vibrate a signal path for the sake of convenience or cosmetics. When aesthetics and signal conflict, we engineer until they don't; signal wins any remaining tie.

### 0.1 Design stance — commercial hardware, clean sheet, silicon-on-merit

This is the **commercial device, designed from scratch to the spec (§1)**. Solder-down silicon on our own board — **no breakout boards, no dev modules, no muxes-as-crutches, no protoboard heritage**. "Chip-down" means *chosen on engineering merit per channel*, which includes **smart sensors with integrated, vendor-validated processing** where that wins:

- **BNO085 stays** — Bosch MEMS + CEVA SH-2 fusion on an embedded core. Years of vendor tuning and out-of-the-box validation (a regulatory asset, R10) for the everyday orientation utility. Configured to stream **raw accel/gyro/mag alongside the fused outputs** — the upstream **ADR-0014 "raw plus processed" posture**: raw substrate for discovery, fused outputs for utility, without us owning fusion.
- The same merit test applies everywhere: integrated front-end (PPG AFEs, gas sensors with on-chip DSP) vs bare transducer is decided per channel on signal quality, validation burden, power, and cost — not ideology.

Pre-certified modules are used only where that is the commercially correct choice (radio certification, GNSS antenna performance).

**The interrogator repo's role is narrow:** it supplies the sensor-truth contract (USR facets + AssetPins + device profile) and the data/command *semantics* — and **interrogator adapts to this design**. Firmware (new MCU port, binary IDL, INT-driven acquisition, OTA) is upstream work against the interface-requirements doc we publish. The prototype hardware is **not a design input** (§2.1); this design owns its own research (§2.4).

### 0.2 What "modular" means here (owner clarification)

Modularity is **the speed at which we can create and ship a new device revision** when the sensor set changes — not field-upgradability of already-shipped units. A gap-filling sensor is highlighted → we turn the board around and ship ASAP: same chassis interface where possible, regenerated board, downstream ingest (§3.3, §6.3). Shipped units evolve via firmware/OTA only.

## 1. Requirements (owner spec, v0.2-reconciled)

| # | Requirement | Engineering reconciliation |
|---|---|---|
| R1 | Many orthogonal solid-state sensors (15 now → 100+ future) | v1 from the candidate set (§2.2), **revised owner list incoming — the §6.3 change flow exists precisely so this lands cheaply**. Growth path: parallel buses + I3C dynamic addressing + reserved expansion segment. |
| R2 | **All parts** 3+ years without replacement — the concept fails if a fan or pump dies | Two-layer answer: (a) **part selection first** — long-life bearing-technology blowers/pumps (50k+ h class MTTF at our duty cycle ≫ 3 y), derated drive, filtered intake path, condensation control; solid-state everything else; (b) serviceable sub-assembly as *fallback*, not excuse. Reliability budget (MTBF rollup) is an H1 deliverable per part incl. actuators. |
| R3 | Battery: optimize toward **8 h ambient**; not set in stone — deep dives/multi-turn draw more; **must not explode size/feasibility; 5 h floor triggers owner review** | Two-mode budget: ambient (sentinel + duty-cycled acquisition) vs interrogation (deep-dive bursts). W-PWR delivers a measured table; cell sized to the smallest package meeting the ambient target; if physics forces <8 h at acceptable size, present the trade to owner at H1. |
| R4 | As small as feasible; **iPhone-grade industrial design**; chassis is constructed around the achieved envelope; **never compromise modularity for size** | Size = output of §5.8 boundary optimization. Chassis wraps the envelope **plus deliberate buffer (§5.8–5.9)** so respins don't churn it. Design language: minimalist shell, hidden apertures, subtle glow/haptics (§5.6). |
| R5 | Pocket-safe: heat, battery, emitters | Thermal zoning from sensing physics (§5.5); battery system to IEC 62133-class expectations; laser class 1; UV interlock (§5.10). |
| R6 | Modular per §0.2 — respin speed | Contract-driven regeneration (§6.3) + frozen-with-buffer chassis interface (§5.9). Target: **sensor-swap respin ≤2 human-days touch time by v2** (§6.6 drives it toward near-zero HITL). |
| R7 | Parallel raw streaming in ambient state; **AI layer controls prioritization/deep-dives**; no sweep bottleneck | **Hard requirement — the prototype's mux sweep is the anti-pattern.** True per-bus parallel acquisition, INT/DMA-driven, with the §5.2b concurrency & interference model: what runs together is governed by intent + a machine-readable compatibility matrix, not by wiring. |
| R8 | Exposure classes: contact / air-entry / liquid-entry / internal | §5.6. **Air path: yes in v1** (fan-driven). **Microfluidics: NOT populated in v1, but buffered** — reserved port, internal volume, connector allowance inside the frozen chassis interface, so adding it later is a respin, not a chassis redesign. |
| R9 | Right medium → right sensor; interaction effects minimized in hardware, then AI optimizes around the rest | Zoning + isolation (§5.5) + the interference matrix (§5.2b) exported as a contract artifact so the AI scheduler can avoid masking interactions. |
| R10 | Regulated posture: wellness-only claims until validated; prefer parts with regulatory-friendly validation | Vendor-validated smart sensors favored where claims matter (BNO085 pattern); W-CERT track (§5.10); upstream SEM-5 alignment. |
| R11 | MCU syncs+streams all comfortably; on-device AI very helpful | §5.1 reference architecture: NPU-class application MCU + always-on sentinel. |
| R12 | Sensor change → regenerate ship-ready state in few cycles | Ratified flow (§3.3/§6.3): **decided here → PCB+device approved → firmware+interrogator ingest and update.** In place before the revised sensor list lands. |
| R13 | **Unit economics (new):** shippable with reasonable margin, B2B + B2C | BOM cost is a first-class, tracked property of every revision: live-priced interactive BOM (LCSC/Octopart), cost column in the sensor matrix (§5.7), cost gates at H1 (architecture) and H2 (BOM freeze); DFM choices (§5.10) made with CM quoting in mind. |
| R14 | **Wireless-first + lifecycle (new):** syncs to a mobile device/app (WebRTC-class); fast charging; regular OTA updates, security fixes, feature gating | §5.1 connectivity (BLE control + Wi-Fi high-bandwidth), §5.4 USB-C PD fast charge, §5.10 secure boot + A/B OTA + hardware crypto identity enabling future feature gates/paywalls. |

## 2. Evidence base (context only — **not design inputs**)

### 2.1 Prototype
A three-board breadboard prototype exists upstream and closed its Phase 0 loop. **We do not consider what has been built** — this project has free rein to drive device hardware that competes with top technology companies and is patentable. The prototype's only exports to us are: the contract artifacts (§3), the sensing use-cases it validated, and the interrogation/alert flow it proved end-to-end (§3.5).

### 2.2 Sensor candidate set (baseline — owner's revised list incoming; every line re-sourced as solder-down silicon, §5.7)

| Capability | Baseline part | Class | Exposure |
|---|---|---|---|
| Gas/VOC/T/RH/P | BME688 | env | air |
| VOC/NOx | SGP41 | env | air |
| PM2.5 | BMV080 | env | air window |
| Thermal imaging 8×8 | AMG8833 | optical | IR window |
| PPG HR/SpO₂ | MAX30102EFD | bio | contact window |
| ToF depth 8×8 | VL53L8CX | optical | window (940 nm) |
| Visible spectral 14-ch | AS7343 | optical | window + LED |
| UV A/B/C | AS7331 | optical | direct/quartz aperture |
| NIR spectral | AS7263 | optical | window + NIR LED |
| IMU 9-DoF (fused+raw) | BNO085 | motion | internal |
| 3D magnetics | TMAG5273 | field | internal |
| Precision analog (RF power, piezo) | ADS1115 (re-eval) | field | internal + probes |
| 60 GHz radar | Acconeer A121 (raw AiP) | spatial | radome |
| GNSS | antenna-integrated module (MIA/NEO class) | location | sky window |
| Touch | MPR121 or MCU-native | contact | shell electrodes |
| Radiation β/γ | BG51-class solid-state | field | internal (thin window) |
| Camera (D7) | raw sensor + FPC | optical | aperture |

### 2.3 Integration checkpoint — interrogator #7 (joint milestone, later)
E2e re-validated on the new device · binary IDL live (+text debug) · diagnostics no-regression · latency budget. The firmware side is upstream's work against our interface doc.

### 2.4 Upstream's prior PCB research — historical input only
Interrogator's PLAN §7.5.3.18 (per-bus concurrency, SPI+DMA for high-rate parts, PPS-disciplined timestamping, I3C direction) is available evidence, **outdated by its own admission and superseded by our H1 research. We own the architecture; we are free to change all of it and likely will.**

### 2.5 Bench observations — physics checklist candidates only
The prototype bench logs contain *some* items that reflect physics/protocol reality rather than breadboard circumstance (I²C single-slave-wedges-bus failure mode; address-collision classes; pull-up/rise-time budgets; thermal cross-talk between hot parts and env sensors; EMI from actuators into counters/analog; sensor libraries that init but read garbage). These enter the H2/H3 review **checklists** as candidates — each is re-derived from datasheets and first principles for *our* topology, never applied as inherited rules.

## 3. Contract boundary & flows

1. **USR is the system's sensor-truth spine** (per-type records: identity/electrical/mechanical facets + AssetPins; per-instance device profile). This repo consumes it **pinned** (submodule/pinned SHA), never forked.
2. **We bind read-only** to `electrical`, `mechanical`, `assets`; the v1 device profile is instantiated from this design.
3. **Ratified change flow (2026-07-10): hardware originates, interrogator ingests.** Sensor change **decided here** → pipeline regenerates the board/device rev → **owner approves** → the approved delta ships downstream as an **ingest package** (USR record drafts, facets with datasheet citations, AssetPins, interface-requirements delta) → **firmware + interrogator repo ingest and update**, backend stacks on top. Single-writer preserved: we produce PR-ready packages; the owner lands them upstream.
4. **Asset storage (owner decision): no Git LFS.** Heavy artifacts (footprints, 3D, gerbers, renders) live **locally in the repo working tree for now**, referenced by `{asset_id, version, sha256}` in a checked-in manifest; **migration target: AWS S3** (assets addressed by `object_key` = S3 key + sha256 — exactly the USR `assets` schema, which was designed for an object store). Recommendation: agree with AWS; use standard S3 + versioned buckets, keep the access layer S3-API-generic (boto-compatible), which preserves the upstream no-lock-in posture at zero extra cost and makes any later move (or a Cloudflare R2 egress-cost hedge) a config change. CI verifies checksums either way.
5. **Cadence separation:** our CI = ERC/DRC/asset-checksum/fab-diff; upstream CI = pytest/contract.
6. **The interrogate-reality flow extends to this device — by construction.** What the prototype proved (ambient stream → detection/intent → active-sensing commands → deep-dive → alert to operator) binds at the *semantics* level (record schema, §3.5 command surface, intent catalog), which is exactly what we consume. The new hardware implements the physical layer of that loop better than the prototype could: per-domain power/clock gating = "AI decides what runs"; INT-driven parallel acquisition = real-time granularity; sentinel domain = always-on detection; glow zones + haptics = the alert surface; touch = the invocation surface. The interface-requirements doc (H1) maps each §3.5 command class onto this hardware so upstream's agent/alert stack ports without semantic change.

## 4. 2026 tooling verdict (unchanged from v0.1 — detail in [`docs/draft-review.md`](docs/draft-review.md))

6–8-layer through-via + POFV via-in-pad at JLCPCB-class fabs (no blind/buried vias there; Freerouting can't route them anyway and has zero SI awareness — grunt nets only, `-inc`-protected, benchmarked v2.2.4 vs v1.9). KiCad 10 + `kicad-cli` (ERC/DRC JSON + exit codes, jobsets) is the headless loop; the IPC API is GUI-bound until KiCad 11; KiCad MCP servers are demo-grade (rjwalters/kicad-tools the most serious). Verified footprint sources (easyeda2kicad/SnapMagic/UL) + human overlay check; LLMs as second readers, never footprint authors. Optional candidate generators: Quilter free program, DeepPCB trial. MCAD: kicad-cli STEP + FreeCAD/StepUp.

## 5. Target v1 architecture

### 5.1 Compute + connectivity — reference architecture (H1 validates on eval kits)

**Two-domain, one board** — burst compute vs always-on vigilance are opposite power regimes; two domains also *implement* R7's "AI decides what runs" as physical power domains.

- **Application domain — STM32N6-class** (Cortex-M55 ~800 MHz + Neural-ART NPU, MIPI-CSI ISP, USB-HS, I²C/I3C/SPI+DMA fabric, input-capture timers). On-device AI headroom (R11), native I3C growth path (R1), camera as stuff-option (D7). Fallbacks: i.MX RT1170 (widest bus fabric), ESP32-P4 (cost-down).
- **Sentinel domain — pre-certified BLE module, nRF54L15-class**, always-on at µA–mA: touch wake, radiation counting, fuel gauge, haptics/glow, RTC, power sequencing, secure-boot root + device identity (R14 feature gates), BLE control plane.
- **High-bandwidth radio — pre-certified Wi-Fi module (R14):** the device syncs wirelessly to a mobile app; deep-dive streams (multi-sensor raw + camera bursts, ~0.1–1 MB/s class) exceed sensible BLE throughput. Architecture: **BLE = control/ambient telemetry; Wi-Fi (station or P2P/direct) = interrogation streams**, carrying a WebRTC-class transport terminated by firmware/app (transport protocol is upstream's choice; we budget the bandwidth, power, and antenna keepouts). Wi-Fi module is power-gated by the sentinel — zero cost in ambient mode. H1 decides one-module (combo BLE+Wi-Fi) vs two; combo (e.g., current u-blox/Murata class) is preferred if its BLE low-power floor meets the sentinel budget, else nRF54 + gated Wi-Fi.

### 5.2 Buses
High-rate sensors on SPI+DMA with INT lines; remaining I²C/I3C split across ≥2 controllers; address collisions solved by bus assignment/straps (no monolithic mux); calculated pull-up budgets; **per-segment load switches** (fault isolation + power gating). Reserved expansion segment (bus + power + INT) for R1 growth.

### 5.2b Concurrency & interference model (R7/R9 — new, first-class)
The prototype's serial sweep degraded granularity and frequency; that bottleneck is designed out, but **"everything always parallel" is not the goal either** — it's *orchestrated* concurrency:

- **Hardware guarantee:** every sensor domain can stream simultaneously at its native rate (per-bus concurrency, DMA, FIFO watermarks, hardware-timestamped INTs). No sensor waits on another's transaction.
- **Interference matrix (contract artifact):** a machine-readable matrix of physical incompatibilities and couplings — optical emitters (UV/white/NIR LEDs, ToF 940 nm, PPG LEDs) vs spectral/optical receivers; actuators (fan/pump/haptic) vs IMU/piezo/radiation counting; Wi-Fi bursts vs RF-power measurement and GNSS; charger switching vs precision analog. Shipped in the ingest package so the **AI scheduler avoids masking interactions by construction** (and can deliberately exploit them, e.g., active illumination).
- **Activation classes:** always-ambient (env, IMU, sentinel) · triggered (touch-activated contact reads; presence-gated radar deep dives) · intent-driven (spectral scans w/ illumination, camera, max-rate multi-sensor fusion) · gated-off (mutually exclusive pairs per the matrix, arbitrated by firmware policy).
- Data-quality flags (emitters/actuators/radio active) ride every record so downstream fusion can weight confidence — semantics carried over from the upstream contract.

### 5.3 Timing
GNSS-PPS-disciplined input-capture timestamping; per-sensor INT latching in hardware; one canonical monotonic→UTC mapping per the wire contract. Cross-sensor skew budget defined at H1 and *measured* at H4.

### 5.4 Power (+ fast charging, R14)
Li-ion pouch (sized by W-PWR) → **USB-C PD fast-charge path**: PD sink controller + charger sized for ~1C+ charge with thermal supervision (charge thermals must not cook env sensors — zoning §5.5; fast charge only when sensing idle or thermally headroomed), fuel gauge, protection. High-efficiency bucks per domain (no heavy LDOs); per-segment load switches; battery lockout; per-domain current-shunt test points so the R3 budget is **measured**.

### 5.5 Floorplan zoning — from sensing physics inward (P0)
Quiet optical/analog nose (spectral, ToF, thermal IR, PPG AFE, camera) · compute midsection · "dirty" tail (actuator drivers, charger, Wi-Fi PA, battery). Gas cluster at intake with thermal moat; exhaust over compute; IR imager isolated from board heat; magnetics/radiation away from motors and switching; GNSS + Wi-Fi antennas with modeled keepouts; partitioned analog grounds; charger/PD switching isolated from precision channels. Every rule derives from a named signal path, not from prototype folklore.

### 5.6 Exposure classes → chassis features (the owner's sketches, engineered)
Contact field (PPG window + touch electrode zones: "touch it and it extracts") · air path (micro-fan channel: intake over gas/PM, exhaust over compute — the only visible holes) · liquid provision (buffered port + volume, v1 unpopulated, R8) · optical apertures (ToF, thermal, spectral trio, camera, emitters; UV-C-transparent window for AS7331) · radar radome (behind shell) · GNSS sky window · **feedback surface: per-zone light pipes ("twinkling stars" = sensors active/amplified) + haptics** · everything else invisible under the monolithic shell (R4 design language).

### 5.7 Sensor BOM — solder-down silicon on merit; alternatives scan mandated
Baseline = §2.2. **H1 runs a per-channel market scan** — the owner expects alternatives to be researched seriously, e.g. **ScioSense ENS161-class** parts vs BME688/SGP41 for the gas stack (noting channel shape differs: BME688 = gas+T/RH/P, ENS16x = TVOC/eCO₂ DSP outputs, SGP41 = raw VOC/NOx — the scan scores *information yield for the interrogation mission*, not spec-sheet vanity), higher-res thermal arrays vs AMG8833, current regulated-grade PPG AFEs vs MAX30102EFD, radiation detector alternatives vs BG51. Scan dimensions: **orthogonal information yield · sensitivity/range · raw-stream access (ADR-0014: raw + processed both available wherever the part allows) · vendor validation/regulatory posture · power · package · unit cost at 1k/10k (R13) · supply longevity**. Output: a scored matrix + recommended v1 BOM for owner sign-off; the owner's incoming revised list merges here via the §6.3 flow.

### 5.8 Dynamic boundary co-optimization → **chassis built with buffer**
Board floor = courtyards + tuned clearance multiplier; grow layers before XY (0.5 mm steps). The *chassis* is then constructed around the achieved envelope **plus explicit buffer** (owner-confirmed): reserved XY/Z margin, spare aperture blanks in the plate, the liquid port/volume (R8), and the expansion segment's reach — so future board revs land inside the same shell whenever physically possible. Envelope + buffer export as STEP and define the industrial design.

### 5.9 Modularity mechanism (R6/§0.2)
Frozen-with-buffer chassis interface (outline, bosses, connectors, aperture-plate geometry) + contract-driven regeneration. The aperture plate is the cheap, separately-versioned part that absorbs exposed-sensor changes. Respin speed is the KPI; §6.6 is the engine that drives HITL toward the minimum.

### 5.10 Commercial-grade (DFM/DFT · certification · lifecycle · IP)
- **Certification (W-CERT):** FCC 15B/CE-EMC/ISED plan from H1, pre-scan at H4; intentional radiators inside pre-certified modules; laser class 1; IEC 62471 UV interlock; battery IEC 62133-class; RoHS/REACH BOM.
- **DFM/DFT:** designed to the target fab/assembly class; test points on every rail/bus; per-domain current shunts; SWD/tag-connect; DNP options (camera, Wi-Fi variant) so one layout serves multiple SKUs; panelization + fiducials; **CM-quotable data from day one (R13)**.
- **Lifecycle (R14):** secure boot rooted in the sentinel's crypto/KeyStore; **A/B (dual-slot) OTA** for regular firmware/security updates; signed images; per-unit identity/serialization at production programming; hardware hooks for **feature gating** (entitlements enforced in firmware, future paywalls/security limits) — shipped units evolve by software (§0.2).
- **Reliability (R2):** MTBF rollup incl. actuators; long-life blower/pump selection + derating + intake filtration; connectors and flex rated for service life.
- **IP posture:** the design rationale log doubles as an **invention-capture log** — novel mechanisms (aperture-plate modularity, interference-matrix-driven orchestration, sentinel-gated sensing domains, contract-driven respin pipeline) get flagged as patent candidates at each phase gate.

## 6. The design pipeline (closed-loop, human-gated, learning)

### 6.1 Stages & artifacts
1. **Contract ingest** — pinned USR + device profile → IO map, bus/address plan, netlist skeleton.
2. **Library** — verified symbol/footprint/3D per part (easyeda2kicad → SnapMagic/UL → last-resort generation), AssetPin recorded (local now → S3), human overlay-check promotes E0→E1.
3. **Schematic** — KiCad 10 multi-sheet capture; LLM second-reader review (addresses, pull-ups, straps, INT completeness, decoupling) against `registry_assets` datasheets.
4. **ERC/DRC loop** — `kicad-cli` JSON + exit codes in CI; agent proposes diffs; human merges.
5. **Placement** — human-owned per §5.5 zoning encoded as keepouts; optional Quilter/DeepPCB candidates for comparison.
6. **Routing** — critical nets by hand (USB-HS, PD, crystals, SPI, PPS, PPG/analog, antenna feeds); Freerouting `-inc` for grunt nets; SI review.
7. **Outputs — yes to all four review artifacts (owner Q):** (a) **native KiCad project** (multi-sheet schematic + fully routed layout); (b) **interactive BOM cross-referenced to live inventory/pricing** (LCSC/Octopart — also feeds R13 cost gates); (c) **design rationale log** (ADRs: routing/layer/thermal choices + invention capture); (d) **the 3D structure for human review at every phase**: `kicad-cli` STEP + raytraced board renders (`pcb render`) at H2/H3, and at H3-freeze a **grounded prototype visual** — board envelope + chassis concept (FreeCAD/StepUp model, rendered) — for the owner and product teams to iterate the industrial design on facts, not sketches (owner-requested deliverable).
8. **MCAD co-design** — STEP ↔ FreeCAD enclosure, collision/aperture checks, 3D-printed shells at H5.

### 6.2 Trust boundaries
Automated & trusted: contract ingest, BOM/pricing, ERC/DRC loops, fab packaging, STEP/render export, checksums. AI-assisted + human gate: schematic review, placement candidates, fix diffs, datasheet cross-checks. Human-only: footprint E1 promotion, critical routing, fab release, safety (battery/laser/UV), phase gates.

### 6.3 Regeneration = the ratified change flow
Sensor change **decided here** → stages 1–2 regenerate the delta → 3–7 replay inside the frozen envelope → **owner approves board/device rev** → ingest package ships downstream → **firmware + interrogator update**, backend stacks on top.

### 6.4 CI
ERC/DRC · asset-checksum manifest (local now, S3 later — same manifest) · contract-pin drift tripwire · fab-output regeneration diff · release tags with full provenance (contract SHA + asset checksums + toolchain versions).

### 6.5 Learning loop — HIL data → less HITL each cycle (owner Q)
Answering "how do we capture HIL data to optimize the whole e2e over time": every human intervention and every physical measurement becomes **machine-readable pipeline input for the next cycle**:
- **Capture:** bring-up/diagnostics runs (conformance reports, skew/power/thermal measurements, EMC pre-scan results), every DRC/ERC violation + its fix diff, every hand-routing constraint, every footprint correction, every deviation — all logged as structured artifacts keyed to *(design SHA, AssetPins, part, rule)*.
- **Compound:** validated fixes graduate into **rules-as-code** — DRC rule files, keepout/zone templates, pull-up calculators, net-class definitions, placement affinity hints, the interference matrix — versioned in this repo. The pipeline's stage 1–4 automation consumes them; nothing is re-learned twice.
- **Converge:** v1 is human-heavy by design (first traversal writes the rulebook). By construction, a v2 sensor swap replays stages 1–7 against an accumulated rulebook where the only *novel* work is the delta sensor's physics — so HITL collapses toward: approve the BOM, eyeball the placement diff, sign the fab release. That is the near-automation the owner is targeting, and the golden-capture discipline upstream (diagnostics baselines) gives the objective no-regression check each time.

### 6.6 Manufacturing handoff (the ultimate goal: ship the design to a company that builds it)
The terminal artifact is a **CM-ready manufacturing data package**: gerbers + ODB++/IPC-2581, drill, stackup + impedance spec, BOM with AVL (approved vendor list + LCSC/DigiKey/Mouser alternates), CPL, assembly drawings, paneling, test specification (bed-of-nails/flying-probe points + functional bring-up script), programming/provisioning procedure, and the DFM report. Prototypes: JLCPCB-class. Production: package quoted to contract manufacturers (procurement optional per CM). H6 exits with this package released.

## 7. Phases

| Phase | Content | Exit |
|---|---|---|
| **H0 — Foundations** | Repo scaffold; toolchain pin (KiCad 10.0.x CI); contract pin mechanism; asset manifest (local, S3-ready); ingest script v0; USR-3 resolution packets drafted | CI green; ingest emits IO map |
| **H1 — Architecture validation** | Eval-kit spikes (§5.1 compute + radio); **per-channel sensor market scan (§5.7)** merged with owner's revised list; interference matrix v0; bus topology; power tree + **two-mode budget vs R3**; reliability (MTBF) rollup incl. actuators (R2); **BOM cost model v0 (R13)**; cert plan v0; layer stack + fab class; **interface-requirements doc → upstream** | Owner ratifies architecture + v1 BOM + budgets (power/cost) |
| **H2 — Schematic** | Verified library w/ AssetPins; multi-sheet schematic; ERC=0; LLM review packet; live-priced iBOM v0; board renders | Owner design review sign-off; BOM 100 % sourced + costed |
| **H3 — Layout** | Zoned floorplan; critical hand-routing; Freerouting grunt pass; DRC=0; SI/thermal review; **envelope freeze → STEP + grounded prototype visual (board + chassis concept) for product iteration** | Envelope + visual ratified; chassis interface frozen (with buffer) |
| **H4 — Fab + bring-up** | JLCPCB-class proto fab/assembly; structured bring-up (per-bus → per-sensor → all-parallel coherence → soak); **measured** power/skew/thermal; EMC pre-scan; HIL capture per §6.5 | Device streams all channels in parallel, conformant; measurements logged |
| **H5 — Chassis v0** | FreeCAD enclosure from frozen envelope+buffer; aperture plate; air path; contact/glow surfaces; 3D-printed shells; fit/thermal iteration with product teams (using the H3 visual) | Assembled device validated per exposure class |
| **H6 — Sign-off + handoff** | (a) R1–R14 scorecard vs built device; (b) joint #7 integration (upstream firmware); (c) **CM manufacturing package (§6.6) released** | v1 done; v2 loop opens (owner's new sensor list → §6.3 flow) |

Cross-cutting: **W-PWR** (power budget), **W-PIPE** (pipeline/CI/rules-as-code), **W-CERT** (compliance).

## 8. Risks
| Risk | Mitigation |
|---|---|
| Power: ambient target vs size (R3 explicitly flexible, floor 5 h) | Two-mode budget; sentinel-first architecture; owner trade review at H1 |
| Actuator longevity breaks R2 | Long-life part selection + derating + filtration; MTBF rollup; serviceable fallback path |
| Footprint/pinout error | Verified-library-first + AssetPins + human overlay + LLM second reader |
| Freerouting v2.x quality regression | Hand-route critical; `-inc`; benchmark vs v1.9; full hand-route fallback |
| New-silicon risk (N6-class, sensor successors) | H1 eval gate; named fallbacks; DNP-friendly layout |
| EMC failure (dense mixed-signal + 60 GHz + emitters + Wi-Fi) | Physics-first zoning; pre-certified radios; H4 pre-scan + respin allowance |
| Interference matrix incomplete → masked signals in field | Matrix seeded from datasheets at H1, *measured* at H4 (pairwise activation tests), shipped as versioned contract artifact |
| BOM cost misses margin (R13) | Live-priced iBOM + cost gates at H1/H2; alternates in AVL |
| Wi-Fi power breaks ambient budget | Wi-Fi hard-gated by sentinel; BLE-only ambient; measured duty costs |
| Upstream contract churn | Pinned SHA + drift tripwire; bumps at phase boundaries |

## 9. Open decisions (proposed defaults)
| # | Decision | Proposed |
|---|---|---|
| D1 | Application MCU | STM32N6-class; fallbacks RT1170 / ESP32-P4 (H1 gate) |
| D2 | Compute pattern | Two-domain: app MCU + pre-certified sentinel/BLE module |
| D3 | Fab class | JLCPCB 6-layer through-via + POFV; 8-layer before microvia; CM re-quote at production |
| D4 | Cell | Sized by H1 two-mode budget; fast-charge 1C+ capable (R14) |
| D5 | Schematic-as-code (atopile) | Spike only; KiCad capture baseline |
| D6 | Mezzanine/flex sensor modules | v2 study; v1 = §5.9 |
| D7 | Camera | Conditional on achieved envelope (phone-attachable → no camera); interface designed in, DNP decides |
| D8 | UV emitter | 365 nm + IEC 62471 interlock |
| D9 | Fluidics | Buffered provision only in v1 (R8) |
| D10 | Asset object store | **AWS S3** (versioned bucket, S3-generic access layer); local manifest until H1 |
| D11 | Radio topology | Combo BLE+Wi-Fi module if its LP floor meets sentinel budget, else nRF54-class + gated Wi-Fi module (H1) |
| D12 | Gas stack composition | BME688 vs ENS161-class vs SGP41 mix — settled by the H1 market-scan matrix on information yield + cost |

## 10. Project 3 structure (on owner go)
Epics H0–H6 + W-PWR/W-PIPE/W-CERT; issues per phase deliverable with Phase/Status/Blocked-by/Evidence fields; v2 backlog column fed by the gap register + owner's market feedback.

---
*v0.2 changelog (owner review 2026-07-11): silicon-on-merit incl. BNO085 raw+fused (ADR-0014); interrogate/alert flow continuity §3.6; concurrency & interference model §5.2b; R2 extended to actuators; R3 made flexible (5 h floor); chassis buffer confirmed §5.8; R13 unit economics; R14 wireless-first + fast charge + OTA/feature gates; Git LFS dropped → local + AWS S3 (D10); sensor market scan mandated §5.7 (ENS161 example, D12); §2.4/2.5 demoted to historical/checklist; sensor-MCP mission framing; learning loop §6.5; CM handoff §6.6; grounded prototype visual committed at H3.*

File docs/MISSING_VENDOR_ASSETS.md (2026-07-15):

# Missing vendor assets — exact URLs for manual download

The cloud sandbox egress proxy allows only GitHub, so these official vendor files could not be fetched. Each URL below was located and verified to exist; download and drop into `registry_assets/<PART>/{schematics,3d}/`.

## A121
- **schematic_vendor_evalkit**: https://developer.acconeer.com/
  - XE121/XM125 official eval schematic: developer.acconeer.com and acconeer.com host blocked by session egress proxy (CONNECT 403); per rules no mirrors/workarounds used
- **3d_step**: (no public URL — requires vendor login: SnapEDA/UltraLibrarian/vendor portal)
  - No A121/XM125 STEP via allowed hosts; acconeer.com blocked

## ADS1115
- **step**: https://www.ti.com/product/ADS1115
  - NOT OBTAINED. www.ti.com is blocked by the network proxy (CONNECT 403); TI CAD/3D models (X2QFN RUG / VSSOP-10 DGS packages) are otherwise delivered via UltraLibrarian, which requires login.

## AMG8833
- **3d_step**: https://industrial.panasonic.com/ww/products/pt/grid-eye/models/AMG8833/cad
  - Official Panasonic AMG88 series 3D CAD (STEP) NOT retrieved: industrial.panasonic.com (and na.industrial.panasonic.com) blocked by network egress proxy (CONNECT 403). Panasonic Grid-EYE evaluation-kit docs on the same domain also unreachable.

## AS7263
- **datasheet_app_circuit**: https://ams-osram.com/products/sensor-solutions/ambient-light-color-spectral-proximity-sensors/ams-as7263-nir-spectral-sensor
  - AS7263 datasheet: ams-osram.com host blocked by session egress proxy (CONNECT 403); per rules no mirrors/workarounds used; no copy present in SparkFun AS726X repo
- **3d_step**: (no public URL — requires vendor login: SnapEDA/UltraLibrarian/vendor portal)
  - No public AS7263 STEP via allowed hosts; vendor site blocked, SnapEDA requires login

## AS7331
- **3d_step**: (no public URL — requires vendor login: SnapEDA/UltraLibrarian/vendor portal)
  - No AS7331 STEP in any allowed public source; ams-osram.com host blocked by session egress proxy (CONNECT 403); per rules no mirrors/workarounds used; SnapEDA/UltraLibrarian require login

## AS7343
- **schematic_vendor_evalkit**: https://look.ams-osram.com/m/41cfc630bb4e80ba/original/AS7343_UG001009_2-00.pdf
  - AS7343 EVK user guide UG001009: look.ams-osram.com host blocked by session egress proxy (CONNECT 403); per rules no mirrors/workarounds used

## BG51
- **schematic**: https://www.teviso.com/en/publications (application notes); datasheet: https://www.teviso.com/documents/bg51-data-specification.pdf
  - Teviso BG51 application note / application circuit PDF NOT retrieved: www.teviso.com blocked by network egress proxy (CONNECT 403). No SparkFun/Adafruit open-hardware fallback exists for BG51 (MikroE 'Radiation Click' schematic is hosted on mikroe.com/teviso.com, both outside allowed egress, and MikroE is not an approved fallback source).
- **3d_step**: https://www.teviso.com/documents/bg51-data-specification.pdf (mechanical drawing section)
  - BG51 mechanical drawing / 3D file NOT retrieved: teviso.com blocked by egress proxy (CONNECT 403). Teviso publishes no STEP model publicly; mechanical outline is only inside the (unreachable) datasheet.

## BME688
- **schematic**: https://www.bosch-sensortec.com/media/boschsensortec/downloads/shuttle_board_flyer/application_board_3_1/bst-bme688-sf000.pdf
  - Vendor reference schematic (BME688 Shuttle Board 3.0 flyer) NOT retrieved: www.bosch-sensortec.com is blocked by the network egress proxy (CONNECT tunnel 403, policy denial). Per rules, no mirrors/workarounds used (Mouser/DigiKey mirrors also blocked and are mirrors anyway).
- **3d_step**: https://www.bosch-sensortec.com/en/products/downloads (CAD/3D section)
  - Official Bosch Sensortec BME688 3D STEP NOT retrieved: www.bosch-sensortec.com blocked by egress proxy (CONNECT 403). Third-party libraries (SnapEDA/SnapMagic, Ultra Librarian, DigiKey models) require login/registration and are not vendor sources, so skipped per rules.

## BMV080
- **schematic**: https://www.bosch-sensortec.com/media/boschsensortec/downloads/shuttle_board_flyer/shuttle_bard_fleyer_3_1/bst-bmv080-sf000.pdf
  - Vendor BMV080 Shuttle Board 3.1 flyer / design-integration guideline NOT retrieved: www.bosch-sensortec.com blocked by network egress proxy (CONNECT 403). Datasheet + STEP already on hand per task, so no 3d entry needed for BMV080.

## BNO085
- **3d_step**: (no public URL — requires vendor login: SnapEDA/UltraLibrarian/vendor portal)
  - CEVA publishes no STEP; SnapEDA links require login (skipped per rules)

## MAX30102
- **schematic_evalkit**: https://www.analog.com/media/en/technical-documentation/data-sheets/max30102accevkit.pdf
  - MAX30102ACCEVKIT EV kit data sheet with schematic: www.analog.com host blocked by session egress proxy (CONNECT 403); per rules no mirrors/workarounds used
- **datasheet**: https://www.analog.com/media/en/technical-documentation/data-sheets/max30102.pdf
  - MAX30102 datasheet: www.analog.com host blocked by session egress proxy (CONNECT 403); per rules no mirrors/workarounds used; no sanctioned open-hardware fallback repo exists for MAX30102 (SparkFun boards use MAX30101/MAX30105)
- **3d_step**: (no public URL — requires vendor login: SnapEDA/UltraLibrarian/vendor portal)
  - OLGA-14 STEP: analog.com blocked; SnapEDA login required

## MPR121
- **step**: https://www.nxp.com/products/no-longer-manufactured/nxp-sensor-toolbox-mpr121-evaluation-kit:KITMPR121EVM
  - NOT OBTAINED. www.nxp.com is blocked by the network proxy (CONNECT 403). MPR121 is an NXP legacy (formerly Freescale) part in QFN-20; no downloadable NXP STEP model could be retrieved.

## NEO-M9N
- **integration_manual**: https://content.u-blox.com/sites/default/files/NEO-M9N_Integrationmanual_UBX-19014286.pdf
  - KEY DOCUMENT NEO-M9N Integration manual UBX-19014286 (reference design): content.u-blox.com host blocked by session egress proxy (CONNECT 403); per rules no mirrors/workarounds used; SparkFun CDN copy also on blocked cdn.sparkfun.com
- **integration_manual_alt**: https://content.u-blox.com/sites/default/files/documents/MIA-M10Q_IntegrationManual_UBX-21028173.pdf
  - MIA-M10Q Integration manual: content.u-blox.com host blocked by session egress proxy (CONNECT 403); per rules no mirrors/workarounds used
- **3d_step**: (no public URL — requires vendor login: SnapEDA/UltraLibrarian/vendor portal)
  - u-blox NEO form-factor STEP hosted on u-blox.com/content.u-blox.com, host blocked by session egress proxy (CONNECT 403); per rules no mirrors/workarounds used

## SGP41
- **schematic**: https://sensirion.com/media/documents/FBD0A26B/61EA8BFA/Sensirion_Gas_Sensors_SEK-SVM4x_Technical_Description.pdf
  - Vendor eval-kit documentation (SEK-SVM4x technical description; also SGP41 datasheet with application circuit at https://sensirion.com/media/documents/5FE8673C/61E96F50/Sensirion_Gas_Sensors_Datasheet_SGP41.pdf) NOT retrieved: sensirion.com blocked by network egress proxy (CONNECT 403).
- **3d_step**: https://sensirion.com/products/downloads (SGP41 3D CAD STEP)
  - Official Sensirion SGP41 STEP NOT retrieved: sensirion.com (download center hosting the 3D CAD ZIP) blocked by egress proxy (CONNECT 403). SnapEDA/Ultra Librarian alternatives require login and are not vendor sources; skipped.

## TMAG5273
- **step**: https://www.ti.com/product/TMAG5273
  - NOT OBTAINED. www.ti.com/download.ti.com are blocked by the network proxy (CONNECT 403), so no TI-hosted STEP for the SOT-23-6 (DBV0006A) package could be downloaded. TI also routes CAD/3D model downloads through UltraLibrarian, which requires login.

## VL53L8CX
- **schematic**: https://www.st.com/resource/en/schematic_pack/satel-vl53l8-schematic.pdf
  - NOT OBTAINED. ST publishes the SATEL-VL53L8 breakout schematic PDF at this URL, but www.st.com is blocked by the network proxy (CONNECT 403 policy denial), so it could not be downloaded. No SparkFun/Adafruit VL53L8CX board exists as an allowed fallback (only Pololu #3419 carries VL53L8CX, which is outside the allowed fallback sources).
- **step**: https://www.st.com/en/imaging-and-photonics-solutions/vl53l8cx.html
  - NOT OBTAINED. st.com is blocked by the network proxy (CONNECT 403). Additionally, ST's product page delivers EDA symbols/footprints/3D models only via third parties (UltraLibrarian/SamacSys), which require registration/login.
## TXU0304 (added H3.0 — VL53L8CH SPI level shifter)
- **datasheet**: https://www.ti.com/lit/ds/symlink/txu0304.pdf
  - NOT OBTAINED (www.ti.com blocked by egress proxy, CONNECT 403). The circuit models the TSSOP-14 pin numbering as **pinout E0 (provisional)** — MUST be verified against the DS before H3.2 pad binding (lib_parts.py TXU0304).

## PCA9306 (added H3.0 — TCS3448 1.8V I2C segment)
- **datasheet**: https://www.ti.com/lit/ds/symlink/pca9306.pdf (or NXP https://www.nxp.com/docs/en/data-sheet/PCA9306.pdf)
  - NOT OBTAINED (ti.com/nxp.com blocked by egress proxy, CONNECT 403). DCU/VSSOP-8 pin map modeled from the standard 1 GND / 2 VREF1 / 3 SDA1 / 4 SCL1 / 5 SCL2 / 6 SDA2 / 7 VREF2 / 8 EN order — **pinout E0**, verify before H3.2 pad binding (lib_parts.py PCA9306).

## MMC5983MA (added at H3.2)
- **datasheet**: https://www.memsinc.com/mems/magnetic-sensors (MMC5983MA datasheet PDF)
  - NOT STAGED: memsinc.com not in registry_assets and blocked by the egress proxy. The LGA-16 pin map is
    unverified — circuit pins 1-6 are PROVISIONAL-E0 and footprint pads 7-16 are declared NC-pending
    (boards/v1/netlist/nc_pins.json). Do not route the MMC fanout until this lands.

## TXU0304 / PCA9306 / OPA381 / AD8317 / MX25UW6445G / dual protection FET (reminder)
- Symbols are PROVISIONAL-E0 (H3.0/H3.2); each part's unbound placeholder pads are declared in nc_pins.json.
  Stage TI SCDS41x (TXU0304), PCA9306 DS, OPA381 (SBOS338), AD8317 DS, Macronix MX25UW6445G DS, and the
  chosen CSD-class FET DS before H3.3 routes their fanout.

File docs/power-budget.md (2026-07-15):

# Two-mode power budget (v1.1 — model; measured at H4)

Cell: **LP503450-class 1200 mAh (50x34x5.2mm) 1S LiPo + protection**; USB-C PD ~1C fast charge (BQ25620).

## Ambient (R3: target 8h, floor 5h)

| load | mA |
|---|---|
| BL54L15 sentinel | 0.60 |
| STM32N657 avg (batch+stop) | 12.00 |
| BME688 ULP | 0.09 |
| SGP41 duty | 0.30 |
| ENS161 duty | 0.20 |
| BMV080 1-min duty | 2.60 |
| MLX90642 1fps | 1.50 |
| MLX90632 spot | 0.05 |
| SHT41 duty | 0.01 |
| BNO086 low-rate | 1.50 |
| MMC+TMAG | 0.30 |
| mic (VAD) | 0.30 |
| A121 hibernate | 0.01 |
| GNSS duty | 0.40 |
| PIN+ADC leak | 0.30 |
| SCD41 gated OFF | 0.00 |
| SGX-CO bias | 0.10 |
| misc/regs | 1.35 |
| **total** | **21.6** |

**Ambient runtime ≈ 56 h** — clears 8h target ~7×.

## Interrogation (deep dive)

| load | mA |
|---|---|
| STM32N657 full+NPU | 150.0 |
| WiFi C6 stream | 120.0 |
| VL53L8CH 15Hz | 45.0 |
| A121 duty | 20.0 |
| MLX90642 8fps | 25.0 |
| spectral+UV+NIR+PPGx2+LEDs | 34.0 |
| SCD41 active | 18.0 |
| GNSS cont | 9.0 |
| blower 50% | 19.0 |
| env sensors | 9.0 |
| sentinel+haptic+glow | 8.0 |
| **total** | **457** |

**Continuous interrogation ≈ 2.6 h** (bursty → mixed 8–20h).

Adds (MLX90632/AS7421/mic/ENS161/SCD41/SGX-CO/SHT41) are gated/duty-cycled; SCD41 + electrochem bias
hard-gated in ambient. PIN radiation replaces BG51 on the ADS131M04 analog domain.

H3.0 adders (3x TPS22916 1V8 sub-rail switches ~2 uA IQ each, PCA9306 ~0, TXU0304 ~1 uA):
<7 uA total — below the model's resolution, absorbed in `misc/regs` (no line-item change).

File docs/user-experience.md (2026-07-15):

# User experience spec — v1 (owner Q&A 2026-07-11)

Palm pebble 62x47x17mm. No buttons/screen; phone app = dialogue, device = instrument.
Orientation is tactile: thumb dish = anchor; dish-under-thumb => sensor strip points away.

## Modes
1. **Pocket ambient** (~61h): silent monitoring (air/pressure/radiation/motion/mag).
   Anomaly => one firm haptic + one color-coded ring segment + phone detail. Never nags.
2. **Point & interrogate**: aim strip at subject; intent from app or press-hold on dish.
   AI wakes relevant stack (thermal/ToF/spectral+illuminators/radar/camera); ring twinkles
   per active zone; double-tap haptic = done; findings on phone.
3. **Touch read**: thumb in dish 10s (breathing glow = progress): PPG HR/SpO2/HRV + ECG/BioZ.
   Optical emitters gated during contact (interference matrix).
4. **Air**: automatic; intake holes on face over gas/PM pocket, exhaust right wall;
   duty-cycled silent in ambient; continuous 10-60s in "sniff" deep-dive.
5. **Liquid (v2)**: left-wall capillary inlet (v1 ships blind port); droplet wicks to
   microfluidic module; respin + aperture-plate swap, no new product.
6. **Charge/lifecycle**: USB-C bottom, ~1C (~1h); signed A/B OTA overnight.

## Design deltas from this review (feed H2/H5)
- **ECG return electrode on back-shell grip zone** (thumb->fingers circuit) — single-point
  ECG impossible; add conductive grip zone wired to AS7058 + IQS7222A channel.
- **Hydrophobic mesh (IP52-class) behind air hole arrays** in the aperture plate (pocket lint).
- Explicit: contact mode and point mode share a face — arbitration is the interference
  matrix's job (touch trigger gates optical emitters).

## Motion + touch interaction language (owner Q&A, zero new BOM)
BNO086 on-chip classifiers (pickup/tap/shake/stability, uA-class, INT-driven) + IQS7222A 12ch:
- pick-up wake · double-tap shell = quick-scan (glove-proof) · hold-steady 500ms = auto-capture
- flick = dismiss · face-down = DND · rim swipe = cycle/dismiss · squeeze both walls = confirm/interrogate
- grip + pocket detection => glow suppression + UV/laser interlock input · hover proximity => ring fade-in
- dish contact-quality coaching (electrode coverage -> glow nudge -> clean PPG/ECG)
- **motion as sensing multiplier**: pose-stamped frames => ToF/thermal super-resolution stitching by
  hand sweep; radar micro-SAR; spectral surface painting; heading+GNSS point-to-tag (reality map).

### Hardware deltas (H2)
- Route BNO086 INT to BOTH N657 and sentinel (motion wake path from ambient).
- Electrode budget in shell/aperture plate: dish ring (2), rim slider (3), side-squeeze (2x2),
  back ECG-return/grip (1), reserve (2) = 12ch IQS7222A fully allocated.

### Touch electrode decision (H3.0, ratified)
The IQS7222A QFN20 exposes only **9 sensor pins** (CRx0-7 + CTx8, DS v1.7
p6) — 12 self-cap zones are not drivable pad-per-pin. **v1 ships 9 self-cap
electrodes**: dish ring (2), rim slider (3), side-squeeze (2 — one pad per
wall instead of 2x2; "squeeze both walls" gesture unchanged), back
ECG-return/grip (1), reserve (1). Dropped: the second reserve pair + the
per-wall squeeze redundancy pads (3 of 12 zones). The flex connector keeps
its 13 positions with E9-E11 grounded as guards, so a **v1.1 mutual-cap
Rx/Tx matrix flex** on the same IQS7222A/connector can restore >12 zones
with flex artwork + firmware only — no board respin. The gesture language
above survives; only per-wall squeeze position resolution is deferred.

## Mounting / placed-monitor mode (ADR-0001)
Ferrous steel target in device (passive, no field) + magnets in accessories (puck/vent-clip/
dock). Dock magnet detected by TMAG5273 => auto placed-monitor mode (continuous fan, free
airflow, magnetometer gated). Non-magnetic mounts (clip/lanyard/tripod) for precision-mag
work. Optional pogo dock charging => indefinite always-on room monitoring. Fixes weak
in-pocket air sensing: mount on vent/wall/hood/dash/strap for the device's best air posture.

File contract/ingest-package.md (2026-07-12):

# Ingest package spec — what a sensor change ships to interrogator (owner Q 2026-07-11)

The USR record is the SPINE; it POINTS to facet YAMLs (ADR-0013 references, never copies). A sensor
change therefore touches the whole semantic stack — otherwise the agent can stream a new sensor but
can't UNDERSTAND it. "Add a sensor → the agent knows more" is literally the sensor_semantics.yaml entry.

## Every downstream artifact a sensor change touches
| interrogator artifact | what it holds | AI role | drafter |
|---|---|---|---|
| `shared/schemas/sensors/<X>.yaml` (USR record) | identity, electrical, mechanical, asset pins, facet refs | the spine | **HW (E0)** |
| `shared/schemas/sensor_specs.yaml` | datasheet bounds (range/accuracy/rate) | valid-range / saturation awareness + conformance | **HW (E0)** — from H1 extraction |
| `shared/schemas/sensor_semantics.yaml` | per-channel quantity/unit/description, **bands**, claim_class, provenance | **core AI meaning** | **HW drafts channel structure/units (E0); SME authors meaning+bands (E1/E2)** |
| `shared/schemas/sensor_safety_limits.yaml` | exposure/safety limits | safety gating | SME+legal |
| `shared/schemas/sensor_calibration.yaml` | cal coeffs / raw↔cal | correct values | SME (factory) |
| `shared/schemas/sensor_baseline_seeds.yaml` | ambient baselines | anomaly/drift refs | SME |
| `shared/schemas/intent_catalog.yaml` + capability-coverage | intents a sensor unlocks | what the device can be ASKED | SME (HW notes new capability) |
| `shared/schemas/fusion_insights.yaml` + `derived_channels.yaml` | cross-sensor fusions | richer joint context | SME |
| `backend/commands/contract.py` | SET_*_RATE + domain on/off | command surface | HW specifies bounds, upstream lands |
| record schema (ADR-0001) | **state flags** (charging/docked/haptic_active/uv_active) | confidence weighting | HW specifies, upstream lands |
| device profile (#123) | per-instance bus/addr + **interference matrix ref** | reflex + active-sensing | HW authors, upstream loads |

**Rule: HW drafts the datasheet-derived / physical facets (E0); interrogator SME authors the MEANING
(bands, claim_class, fusion, intents) with KB provenance (E1/E2). Single-writer preserved — we deliver
PR-ready drafts, owner lands upstream.**

## v1 sensor deltas → semantic-stack work triggered
ADD (need full stack incl. new semantics/specs/intents): MLX90642, VL53L8CH, TCS3448, AS7058,
MMC5983MA, MIA_M10Q, IQS7222A, ADS131M04, BNO086.
DEPRECATE (mark successor, retire semantics/specs): AMG8833→MLX90642, AS7343→TCS3448, MPR121→IQS7222A,
NEO_M9N→MIA_M10Q, ADS1115→ADS131M04, VL53L8CX→VL53L8CH, BNO085→BNO086, drop AS7263.
NEW capability → new intents/fusions the SME should author:
- MMC5983MA nT: heading, ferrous-anomaly, current-loop mapping (navigation + "map reality" intents)
- AS7058 ECG/BioZ: cardiac observables beyond PPG (wellness intents)
- TCS3448 vs AS7343: richer 380–1000nm bands (material/food/health spectral intents)
- MLX90642 32×24 vs 8×8: higher-res thermal → thermal⊕ToF super-res fusion (derived_channels)
- MIA_M10Q RAWX: raw pseudorange/carrier-phase (precision-location intents)
- VL53L8CH histograms: raw per-zone bins → richer depth fusion

The HW ingest package for each of the 9 ADDs carries the E0 draft (USR + specs bounds + channel
structure/units from the H1 datasheet extraction); the SME authors the meaning. This is the
"sensor MCP" loop: HW defines the physical capability, the semantic layer turns raw → understanding.

## Flags & verbs → upstream placeholders (verified vs interrogator repo, 2026-07-11)
Placeholders CONFIRMED upstream: PLAN §5.3 "Cross-Signal Interference Matrix" (our matrix v1 is its
successor for the new board); record_schema.md field-8 `activeFlags` bitfield (0x01 motors · 0x02 wifi ·
0x04 LEDs · 0x08 valve — "Class A data-quality flags", fusion weights confidence);
sensor_semantics.yaml top-level `flags:` section + actuator-state channels (NIR-LED pattern:
"when on, reading is active-illumination, not environmental").

Routing corrections (supersedes the looser wording above):
1. **Bit assignments** extending the existing bitfield (no collisions; 0x08 valve stays reserved for
   v2 fluidics): `0x10 charging · 0x20 docked · 0x40 haptic_active · 0x80 uv_active`.
2. **Flags feed sensor_semantics.yaml too** — each new flag gets a semantics entry (what it MEANS,
   e.g. docked = mounted/placed-monitor/magnetometers gated), and each victim channel gets a confound
   description in the existing NIR-LED style (e.g. "AS7058 ECG during `charging`: switching-noise risk,
   weight down"). This is how the AI interprets flagged data, not just filters it.
3. **Verbs do NOT enter semantics** — tdm/mutex/stagger/gate are scheduler policy only (firmware
   reflex + edge policy via device-profile ref, §8 of interface-requirements.md).
4. **Upstream reconcile ask**: PLAN §7 lists `uncalibrated|error` flags that record_schema.md's 4-bit
   field doesn't define — upstream should reconcile schema↔PLAN before extending the bitfield.

## v1.1 sensor deltas (ADR-0002, 2026-07-11) — ingest-package additions
ADD USR records + specs + semantics (HW drafts E0 facts; SME authors meaning):
MLX90632, AS7421, MEMS_MIC, ENS161, SCD41, SGX_4CO, SHT41, PIN_RAD (radiation, replaces BG51).
DEPRECATE: BG51 → PIN_RAD. New intents unlocked for SME authoring: spot-temp/fever (MLX90632),
hydration/tissue-NIR (AS7421), phonocardiography/acoustic (MEMS_MIC), scent-granularity (ENS161),
true-CO2 occupancy/ventilation (SCD41), CO safety/breath (SGX_4CO). New accessory-port channel class:
attachments register via ID EEPROM (ECG/BioZ/probe/rad-wand) — device-profile addition.

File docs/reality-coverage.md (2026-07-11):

# Reality Coverage Map — full sensor rundown, FDA capacity, gaps (v1 + proposed)

**2026-07-11.** Maps the sensor set to the physical phenomena a user can interrogate, the diagnostic/regulatory ceiling of each, and what is missing or not yet possible. Aligns to the spec (solid-state, 3+ yr, raw-parallel-streaming, modular, ambient-first, exposure classes, regulated-where-possible).

**FDA/regulatory legend** — *no chip is ever "FDA-cleared"; clearance is a system property (hardware + algorithm + clinical study + labeling). This column = whether the part can SUPPORT a clearance path.*
- ✅ **Clearance-capable** — part can meet the relevant standard at system level; ship as wellness first, clear later.
- 〜 **Wellness / adjunctive** — supports wellness claims + adjunctive/"indication" clearances (not standalone diagnosis).
- 🌍 **Environmental/safety-regulated** — governed by EPA/OSHA/IEC, not FDA; accuracy-graded, not "diagnostic".
- 🔧 **Utility** — non-regulated sensing (navigation, distance, vision, fields).
- 🧩 **Extension/reserved** — capability reached via the accessory port or a reserved bay, not the core pebble.
- ❌ **Not possible now** — physics or regulation blocks it in a pocket device today.

## A. Core sensor set (solid-state, inside the pebble)

| # | Sensor | Physical domain | Captures (raw) | Exposure | Reality intents it serves | FDA/reg capacity |
|---|---|---|---|---|---|---|
| 1 | **VL53L8CH** | Optical / ToF | 8×8 depth + per-zone photon histograms | window | distance, presence, gesture, room mapping, material hints | 🔧 |
| 2 | **MLX90642** | Optical / LWIR | 32×24 thermal image | window | heat maps, hot-spots, insulation, fever *screening* | 〜 (adjunctive w/ ref) |
| 3 | **MLX90632** *(add)* | Optical / LWIR | single-point radiometric temp ±0.2–0.3 °C | window | accurate spot temperature, elevated-temp indication | 〜 |
| 4 | **TCS3448** | Optical / VIS spectral | 14-ch 380–1000 nm counts | window+LED | color, material ID, food, bilirubin/melanin index | 〜 (bilirubin/melanin precedent) |
| 5 | **AS7331** | Optical / UV | UVA/UVB/UVC irradiance (24-bit) | UV aperture | UV index, sterilization check, forensic, counterfeit | 🌍 |
| 6 | **AS7421** *(add)* | Optical / NIR spectral | 64-ch 750–1050 nm | window+LED | hydration (970 nm), tissue, moisture, material chemistry | 〜 |
| 7 | **MAX30102** | Optical / PPG | red+IR PPG (18-bit FIFO) | contact | HR, SpO2 (wellness turnkey) | 〜 → ✅ at system level |
| 8 | **AS7058** | Optical+electrical / vitals AFE | PPG + **ECG + BioZ + EDA** (20-bit) | contact + electrodes | HR/HRV, ECG rhythm, body-composition, hydration, stress | ✅ (ECG to IEC 60601-2-47; needs electrodes 🧩) |
| 9 | **VD66GY** *(DNP option)* | Optical / imaging | global-shutter raw Bayer | window | vision grounding, OCR, visual context | 🔧 |
| 10 | **BME688** | Chemical / MOX + env | gas resistance (heater-swept) + T/RH/P | air | air quality, VOC fingerprint, scent, environment | 🌍 |
| 11 | **SGP41** | Chemical / MOX | raw VOC + **NOx** ticks | air | air quality, NOx, complements BME688 | 🌍 |
| 12 | **ENS161** *(add)* | Chemical / MOX array | 4-element raw resistances | air | scent/breath granularity, perfume/material discrimination | 🌍 |
| 13 | **SCD41** *(add)* | Chemical / photoacoustic NDIR | true CO2 (abs.) | air | CO2 (occupancy, ventilation, agriculture, safety) | 🌍 (capnography ❌ — too slow) |
| 14 | **SGX-4CO** *(add)* | Chemical / electrochemical | raw CO current | air | CO safety, breath-CO (smoking/oxidative stress) | 〜 (breath-CO precedent) |
| 15 | **SHT41** *(add)* | Environmental | reference T/RH (unheated) | air | accurate humidity/temp; anchors all MOX comp | 🌍 |
| 16 | **BMV080** | Particle / laser scattering | PM2.5 mass | air window | particulates, air quality, smoke, dust | 🌍 |
| 17 | **BNO086** | Motion / inertial | 9-DoF raw + fused quaternion | internal | orientation, gesture, tremor, gait, activity | 〜 (tremor/gait precedent) |
| 18 | **TMAG5273** | Field / Hall | 3-axis B-field (mT) | internal | magnets, current, ferrous mass, dock detect | 🔧 |
| 19 | **MMC5983MA** *(add)* | Field / AMR | 3-axis B-field (nT) | internal | heading/compass, ferrous anomaly, EM mapping | 🔧 |
| 20 | **MEMS mic** *(add)* | Acoustic | audio + ultrasonic-adjacent PDM | port | heart/lung sounds, machine acoustics, leaks, environment | 〜 (phonocardiography precedent) |
| 21 | **A121** | EM / 60 GHz radar | complex Sparse-IQ | radome | micro-motion, respiration, presence, through-material, range | 〜 (contactless-resp precedent) |
| 22 | **ADS131M04 + AD8317** | EM / precision analog | 4×24-bit; RF power (dBm) | internal + probes | piezo/vibration/acoustic, RF-field strength, external analog | 🌍/🔧 |
| 23 | **BG51 → see §D** | Radiation | β/γ dose (TTL pulses) | thin window | radiation dose, safety screening | 🌍 (isotope ID 🧩) |
| 24 | **MIA-M10Q** | Location / GNSS | position + **raw pseudorange/carrier** | sky window | location, time, geo-tagging, precision positioning | 🔧 |
| 25 | **IQS7222A** | Interaction / cap-touch | 12-ch raw counts | shell electrodes | touch, swipe, squeeze, grip, hover, contact-quality | 🔧 |

## B. Reality-domain coverage — what a user can ask about

| Phenomenon | Covered? | By |
|---|---|---|
| Light / color / spectrum (VIS) | ✅ | TCS3448, camera |
| UV | ✅ | AS7331 |
| Near-IR / tissue / moisture | ✅ | AS7421 |
| Thermal / heat | ✅ | MLX90642 + MLX90632 |
| Distance / depth / 3D | ✅ | VL53L8CH, A121 radar, (camera) |
| Motion / orientation / vibration | ✅ | BNO086, ADS131M04(piezo) |
| Sound / acoustics / ultrasound-adjacent | ✅ | MEMS mic |
| Air gases / VOC / chemistry | ✅✅ | BME688, SGP41, ENS161, SCD41, SGX-CO |
| Particulates / PM | ✅ | BMV080 |
| Humidity / pressure / temp (env) | ✅ | BME688, SHT41 |
| Magnetic / EM fields | ✅ | TMAG5273 (mT), MMC5983MA (nT) |
| RF field strength | ✅ | AD8317 → ADS131M04 |
| Radar / micro-motion / through-wall | ✅ | A121 |
| Radiation (dose) | ✅ | BG51 / PIN |
| Radiation (isotope ID / energy) | 🧩 | SiPM+scintillator (Pro bay) |
| Location / time | ✅ | MIA-M10Q |
| Cardiac electrical (ECG) | ✅🧩 | AS7058 + electrodes |
| Blood oxygen / pulse | ✅ | MAX30102 / AS7058 |
| Body composition / hydration (BioZ) | ✅🧩 | AS7058 + electrodes |
| Breath biomarkers (CO) | ✅ | SGX-4CO |
| Breath biomarkers (NO/FeNO, acetone) | ❌ | needs purpose-built subsystem |
| AC E-field / mains EMF | ⚠ gap | (see §E — candidate add) |
| Sound-source direction / array | ⚠ partial | single mic (array = future) |
| True molecular speciation (GC/MS) | ❌ | benchtop only |
| Blood glucose (non-invasive) | ❌ | physics + regulation |
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

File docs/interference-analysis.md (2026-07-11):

# Sensor cross-contamination & interference analysis (v1 set, 2026-07-11)

18 modalities on one pebble: each is source AND victim. Nine channels, mitigations at three
layers — MECH (zoning/baffle/material/mesh), FW (scheduler: TDM/mutex/gate/flags), CAL.
Machine-readable pairs in interference-matrix.yaml (scheduler input, MEASURED at H4).
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

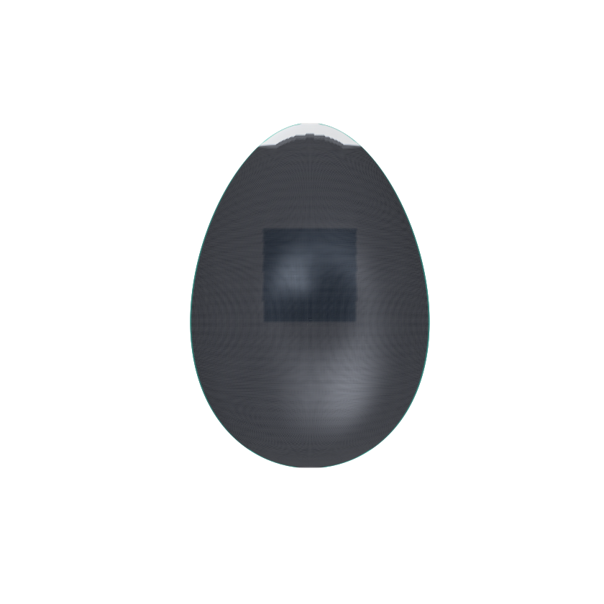
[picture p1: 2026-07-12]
enclosure/concept_pebble_top.png

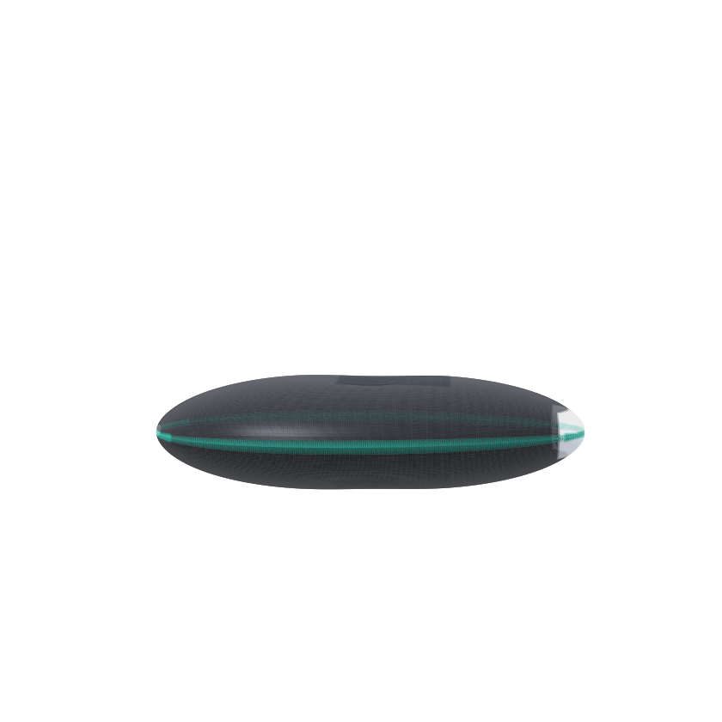
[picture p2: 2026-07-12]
enclosure/concept_pebble_side.png

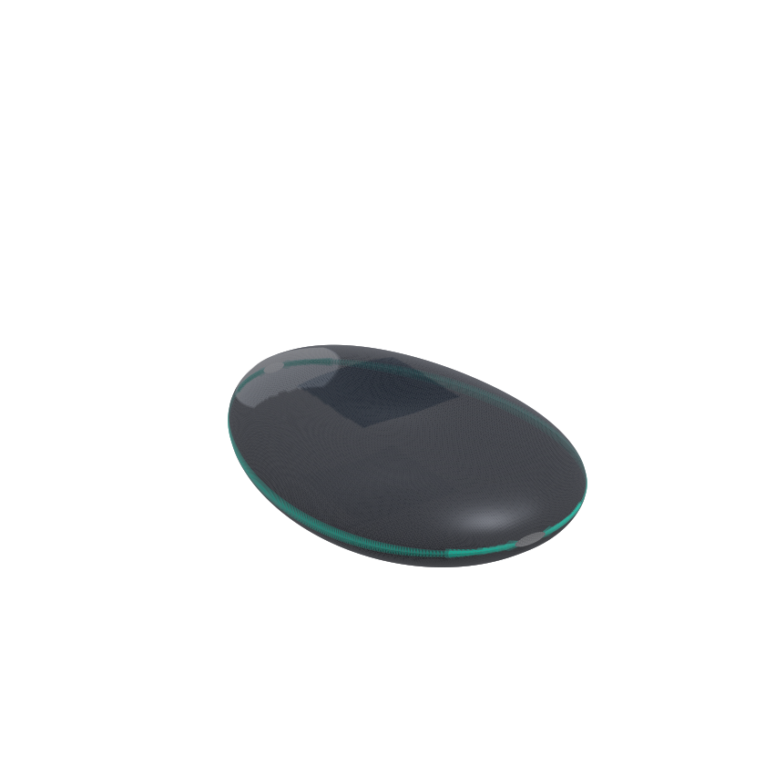
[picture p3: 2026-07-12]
enclosure/concept_pebble_iso.png

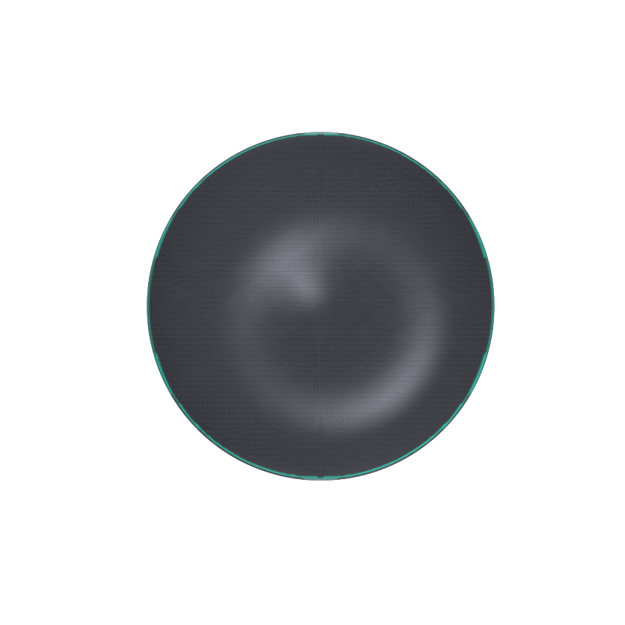
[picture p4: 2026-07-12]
enclosure/concept_puck_top.png

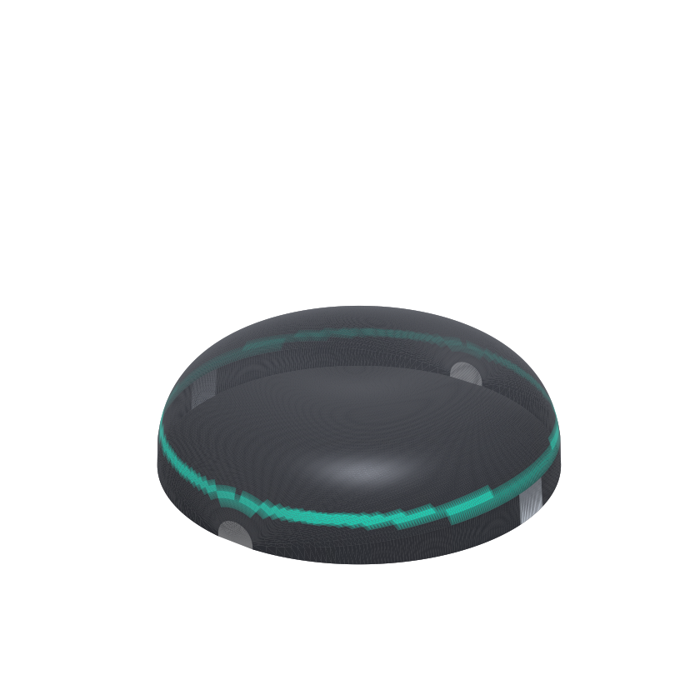
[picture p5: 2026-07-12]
enclosure/concept_puck_iso.png

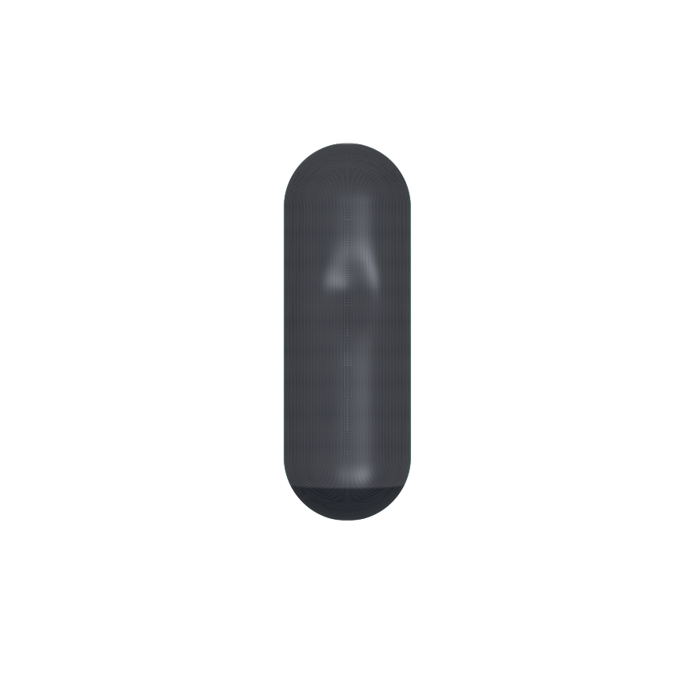
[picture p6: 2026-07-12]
enclosure/concept_wand_top.png

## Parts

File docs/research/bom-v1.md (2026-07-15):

# v1 BOM — market-scan verdicts (web-verified 2026-07-11)

Full agent research in session transcript; per-claim URLs verified at Digi-Key/Mouser/LCSC/vendor pages.

## Sensor deltas vs baseline (ratified for v1 unless owner objects)
| Ch | v1 part | Action | Why | $@1k |
|---|---|---|---|---|
| Gas | BME688 | keep | only raw programmable-heater MOX + T/RH/P | 7.50 |
| VOC/NOx | SGP41 | keep | only cheap raw NOx; no successor (SGP43 doesn't exist) | 5.70 |
| PM | BMV080 | keep | nothing smaller emerged; fanless mW-class | 31.00 |
| Thermal | **MLX90642** (was AMG8833) | replace | 32x24 raw px, 2uA sleep, ~$21 | 21.00 |
| PPG | MAX30102 + **AS7058** | add | AS7058: 20-bit PPG/ECG/BioZ, <20uA, $2.51 | 8.71 |
| ToF | **VL53L8CH** (was CX) | replace | +$0.18 buys raw CNH histograms | 5.58 |
| Spectral | **TCS3448** + AS7331, drop AS7263 | replace | ams-named AS7343 successor; AS7263 legacy | 10.09 |
| IMU | **BNO086** (was 085) | replace | drop-in, 3x stock, lower idle; raw+fused | 9.06 |
| Mag | TMAG5273 + **MMC5983MA** | add | nT regime (heading/ferrous) for $1.36 | 1.67 |
| Radar | A121 | keep | raw Sparse-IQ, deep stock | 7.62 |
| GNSS | **MIA-M10Q-01B** (was NEO-M9N) | replace | 4.5mm SiP, 1/4 power, only RAWX variant | 8.08 |
| Radiation | BG51 | keep | 25uA pulse-to-GPIO, no analog chain | ~50 est |
| Touch | **IQS7222A** (was MPR121, EOL) | replace | $0.42, raw counts, 6.7uA | 0.42 |
| ADC | **ADS131M04** (was ADS1115) | replace | 4ch simultaneous 24-bit 64kSPS; AD8317 absorbed into N6 ADC | 3.59 |
| Camera | VD66GY (DNP opt) | add-opt | global shutter, N6 first-party, longevity 2036 | ~18 |

**Sensor subtotal ~ $183 @1k** (+camera). Compute+radio+power: STM32N657 ($12.5-14.9) + XSPI NOR + BL54L15 ($3.99) + ESP32-C6-MINI-1 ($2.50, SDIO 53Mbps) + power tree ($7.80) ~ **$31**. Actuator: Sunon UB3F3-500 blower ~$13 (L10 report requested).

## Hard findings that changed the architecture
1. u-blox NORA-W36 EOL + UART-limited -> **Wi-Fi = ESP32-C6-MINI-1, ESP-Hosted over SDIO** (53 Mbps TCP verified).
2. nRF54L15 has **no cap-touch peripheral** -> IQS7222A handles touch (needed anyway, MPR121 EOL).
3. i.MX RT1170 NRND + zero franchise stock; ESP32-P4 mid-EOL rev transition -> **strengthens N657 choice**.
4. AS7343 EOL trajectory (TCS3448 successor; resolve 10k-MOQ flag with ams before H2 freeze).
5. MPR121 discontinued; AS7038RB discontinued (avoid).

## Open verifications (H2 gates)
STM32N6 DS14791 power tables · TCS3448 lifecycle/MOQ · MIA-M10Q-01B orderability · BG51 quote+dims · BNO08x current tables · Sunon L10 · C6 module cert grant list.

## Replacement trade-off ledger (owner review 2026-07-11)
| Swap | LOSE | GAIN |
|---|---|---|
| AMG8833→MLX90642 | 6x active draw (28 vs 4.5mA); tallest part on face (TO-39+lens 5.1mm); young silicon, no 1k break; AMG field history | 12x raw px; raw-or-cal selectable; 2uA sleep => lower AVERAGE power duty-cycled; FOV options; MLX90641 fallback |
| VL53L8CX→CH | +$0.18; heavier frames on bus (budgeted, SPI+DMA); less community mileage on CNH | raw per-zone photon histograms (material/translucency/multi-target; permanent substrate) |
| AS7343→TCS3448 | AS7343 lib ecosystem; 10k-MOQ/lifecycle ambiguity (OPEN); driver work | channel survives (AS7343 EOL); same 14ch/pkg/power; half price; raw FIFO |
| BNO085→BNO086 | ~nothing (+$0.25) | 3x stock; lower idle; 14-bit accel fusion; firmware carries over |
| NEO-M9N→MIA-M10Q-01B | nav rate ~25->~10Hz class; no SPI/USB; less forgiving RF layout; -01B orderability UNCONFIRMED (most likely swap to revert; MAX-M10S fallback) | only RAWX (raw pseudorange/carrier phase); 1/4 power; 4.5mm SiP; -$4; SAW+LNA integrated |
| MPR121→IQS7222A | prototype touch firmware + hobbyist lore; Azoteq GUI tooling | part is ALIVE (MPR121 EOL); 3.5x cheaper; 6.7uA ULP; raw counts; wake features enabling gesture language |
| ADS1115→ADS131M04 | I2C simplicity (SPI-only, DMA lane); 10x active power (duty-cycled); wide direct FSR (M04 +/-1.2V needs attenuators) | 4ch simultaneous 24-bit/64kSPS (~300x raw bits/$); true waveform capture; spare precision channels; AD8317 absorbed by N657 ADC |

Pattern: losses are OPERATIONAL (mA, drivers, supply risk — all fenced: sleep/duty architecture, H2
one-time driver work, named fallbacks + DNP pads). Gains are INFORMATIONAL (histograms, carrier phase,
resolution, simultaneity) — permanent, compounding through every future model. Forced swaps: MPR121,
AS7343. Watch-item: MIA-M10Q-01B orderability.

## Candidate ADDS from owner review (pending owner call)
- SHT41 (~$1.50, 1.5mm DFN): unheated reference-grade T/RH anchor away from self-heating; improves MOX
  humidity compensation. Recommend ADD.
- SCD41 (~$8-12, 10x10x6.5): TRUE CO2 (photoacoustic NDIR) — the one real hole in the air stack
  (BME688 eCO2 is a VOC proxy). Strong for buildings/facilities vertical. Recommend ADD if envelope allows.
- ENS161: REJECTED (black-box DSP outputs vs ADR-0014 raw-first; same MOX class = no orthogonal info;
  1.8V rail; patchy supply). SGP41 was never replaced — BME688+SGP41 are complements (different MOX
  platforms; SGP41 has the NOx pixel).

## RATIFIED 2026-07-11 (ADR-0002)
All 7 adds ACCEPTED (MLX90632, AS7421, MEMS mic, ENS161, SCD41, SGX-4CO, SHT41). BG51→bare-PIN ACCEPTED.
Magnetic pogo accessory port ACCEPTED. Board 60×46, chassis 66×50×18. See docs/decisions/0002.

## H2.5 datasheet note (2026-07-12) — SGX-4CO (DS-0138 Issue 3)
- MOUNTING: pins must NOT be glued or soldered (DS p3 note 1, warranty) — **BOM add: 3× PSB
  socket receptacles for Ø1.55 pins** (Mill-Max 0326/0305 class, drill Ø1.7); cell plugs in →
  field-replaceable, which is exactly the R2 serviceability flag ("~2-5yr life") answered.
- Pin circle: 3× Ø1.55 pins on 13.5 mm PCD, can Ø20 × 16.5 (+3.9 pins) — footprint E1;
  13.5 PCD pad ring slightly exceeds the ratified 14×14 envelope → ECO-H3 gas_b repack
  (EXECUTED at H3.1: envelope 17×17, gas_b zone grown; can Ø20 stays on-board).
- Electricals (p1): output 70±20 nA/ppm, recommended load 10 Ω, range 0-2000 ppm (overload
  5000), t90 <30 s, baseline ±2 ppm, filter capacity >20 000 ppm·h, life >24 months in air,
  −30..+50 °C, 15-90 %RH; intrinsic-safety max o/c 1.3 V / 0.3 mA @2000 ppm — comfortably
  inside LMP91000 potentiostat range (TIA gains cover 70 nA/ppm × 2000 ppm = 140 µA FS).

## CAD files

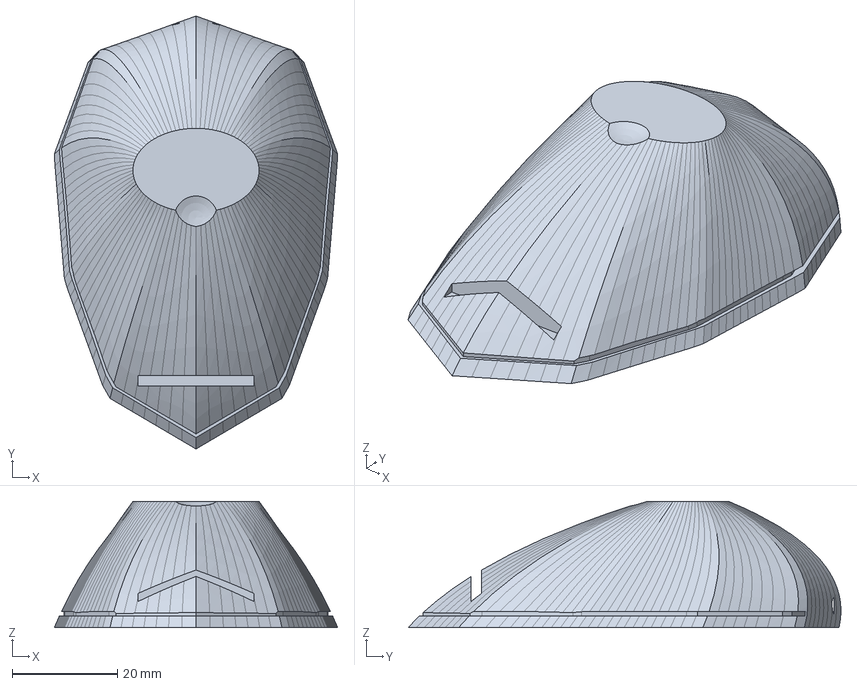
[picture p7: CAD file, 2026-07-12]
enclosure/chassis_scanner.step
53.9 x 82.4 x 24.0 mm

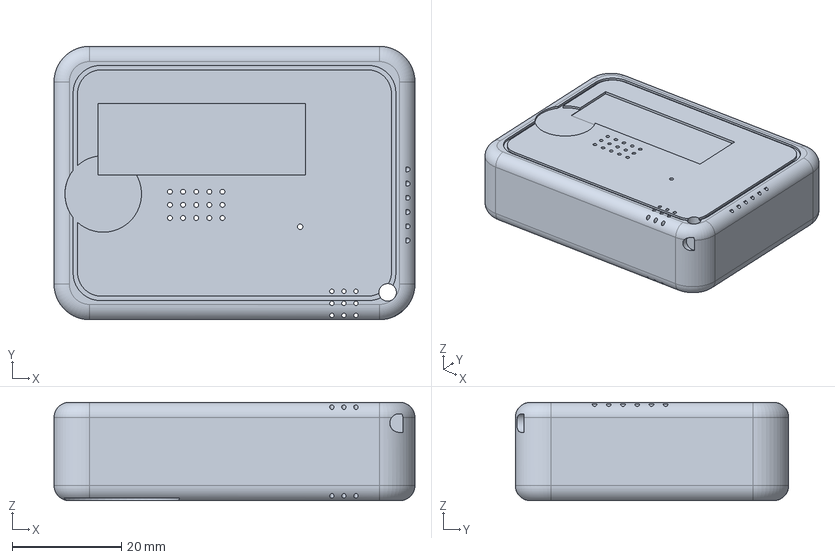
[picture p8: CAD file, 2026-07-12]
enclosure/chassis_v0.step
66.0 x 50.0 x 18.0 mm

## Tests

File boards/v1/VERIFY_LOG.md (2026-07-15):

# VERIFY closure log — H2 stage-2 (+ H2.5 rounds 2-3, H2.6 final wave)

**Date:** 2026-07-12 · Method: `pdftotext` (+ `pdftoppm` page renders for
drawing figures) over the STAGED datasheet PDFs in
`registry_assets/<PART>/datasheet/` (the only vendor documents reachable in
this environment). Every closure below is annotated in the circuit source as
`VERIFIED-DS <doc> p<page>`. Items that need a missing PDF are listed at the
bottom with the exact file the owner should drop in.

**H2.5 round 2 (items 12+):** the 2026-07-12 PDF drop closed 11 of the open
items and opportunistically re-verified 8 more parts. 9 footprints promoted
to `generated-E1` (real vendor land patterns); ERC still 0/0, 19/19 tests
green after all circuit fixes below.

**H2.5 round 3 (items 27+):** the same-day second drop (SGX-4CO DS-0138,
LMP91000 SNAS506I, BL54L15 EZ-DS v1.9) closed the last 3 closable items.
2 more footprints promoted to E1; LMP91000 and BL54L15 symbols renumbered
to real package pins (netlist regenerated). ERC 0/0, 19/19 green.

**H2.6 final wave (items 30+):** the three ST datasheets landed (DS14791 =
STM32N657, DS14310 = VL53L8CH, DS13838 = VD66GY). The N657 was rebuilt on the
real 142-ball VFBGA142 map — **the routing blocker is closed**; the supply
scheme audit it enabled found 3 real power bugs (core buck divider = 1.145 V,
3V3 divider = 2.59 V, missing HSE crystal) plus the PWR_ON/sequencing fixes.
VL53L8CH closed on its own DS; VD66GY captured (DNP). ERC 0/0, 19/19 green;
`interrogator_v1.kicad_pcb` declared stale pending the H3 rebuild.

## Closed (datasheet-verified)

| # | Item | Verdict | Evidence | Circuit action |
|---|---|---|---|---|
| 1 | BMV080 I2C address + interface straps | **0x57 confirmed**; protocol select is a dedicated **PS pin: to VDDIO = I2C, to GND = SPI**; in I2C mode CSB + MISO become address straps and must not float — CSB=1, MISO=1 → 0x57 | bst-bmv080-ds000.pdf p26 (Fig. 25 + pin table), p32 (Table 14) | **Bug fixed**: old model strapped `AB_SEL → GND`, which per DS selects SPI. Replaced with `PS/CSB/MISO_ADDR` pins all strapped to VDDIO (sensors_misc.py) |
| 2 | MAX30102 1.8 V core on 3.3 V-pulled I2C bus | **Safe** — abs-max "All Other Pins to GND −0.3 V to +6.0 V"; DS states tolerance of any supply order | MAX30102.pdf p2 (Abs Max), p28 | Comment closed (lib_parts.py, sensors_i2c.py) |
| 3 | A121 supply rails | **VRX/VTX/VDIG are 1.8 V-only** (abs-max 2.0 V; VRX/VTX must never exceed VDIG); **VIO may be 1.8 or 3.3 V** (abs-max 3.63 V) | A121-Datasheet.pdf (v1.8) p10 Table 2, p6 | **ECO-H3 flagged**: current wiring feeds the whole part from 3V3_RADAR — VDIG/VRX/VTX bundle must move to the 1V8 rail (comment in lib_parts.py + sensors_misc.py) |
| 4 | A121 SPI max clock | **50 MHz**, SPI mode 0 (CPOL=CPHA=0), SS released between transactions | A121-Datasheet.pdf p16-17 (Table 12) | Comment closed; shared SPI1 at N657 speeds is legal |
| 5 | TMAG5273 variant addresses | **A1 (and A2) default = 0x35**; B=0x22, C=0x78, D=0x44 (Table 6-2) → order **TMAG5273A1** | tmag5273.pdf p16 | Comment closed (lib_parts.py, sensors_i2c.py) |
| 6 | BNO085/BNO086 PS straps + addresses | **PS1=1, PS0=1 → SPI**; both must be high at reset, then PS0 repurposes as active-low WAKE; pins 5/6; I2C fallback addr 0x4A/0x4B via SA0 | BNO085 DS p9 (Fig 1-5), p10, p18, p19, p14 | Matches existing 10k-pullup + host-GPIO topology; comment closed |
| 7 | VL53L8CX comm-mode strap | **C1 = SPI_I2C_N: 47 k to IOVDD → SPI; 47 k to GND → I2C.** There is **no separate I2C_RST pin** (C1 doubles as I2C-reset by toggling). Full pad-name map extracted (A1..C7) | vl53l8cx.pdf (DS14161) p6-7 Table 3 | Comment closed; **second finding: IOVDD is 1.2/1.8 V only** — ECO-H3 to move IOVDD+CORE_1V8 off 3V3_OPTICAL |
| 8 | AS7331 address straps | **addr[6:0] = 1110_1,A1,A0** → A1A0=00 gives **0x74**; A1=pin 7, A0=pin 14 | AS7331-AQFT DS p43, p9 | Comment closed |
| 9 | BME688 address | **SDO=VDDIO → 0x77** (SDO=GND → 0x76; must not float); CSB high = I2C | bst-bme688-ds000.pdf p45 | Confirmed as wired |
| 10 | SGP41 address + package | **0x59 fixed**; DFN-6 2.44×2.44×0.85, pitch 0.8, GND die pad → footprint generated from these numbers | SGP41 DS p12, p1/p18 | Confirmed; footprint `generated/SGP41_DFN6_2.44x2.44` |
| 11 | TCS3448 address (partial) | TCS3448 DS unavailable; **family anchor: AS7343 ordering table lists 0x39** (TCS3448 is the ams-named AS7343 successor, same 3.1×2.0 OLGA) | AS7343-DLGM DS p5, p3 | Stays `# VERIFY` with the anchor noted |

Bonus extractions used for footprints: A121 full 50-ball named map (DS p8-9)
→ `generated/A121_fcCSP50`; VL53L8 pad-name grid → `generated/ST_VL53L8_LGA16`.

## Closed — H2.5 round 2 (2026-07-12 PDF drop)

| # | Item | Verdict | Evidence | Circuit action |
|---|---|---|---|---|
| 12 | TCS3448 addr + package | **0x39 anchor REFUTED — addr is 0x59** (fixed). Part is 1.8V-only: VDD abs-max 1.98V AND SCL/SDA abs-max 1.98V; INT/GPIO 3.6V-tol. Pin map: 1 VDD 2 SCL 3 GND 4 LDR 5 PGND 6 GPIO 7 INT 8 SDA; GPIO must not float (bus-voltage select at startup) | TCS3448_DS001121 v2-00 p19 (Table 8), p9 (Table 3), p8 (Table 2), p21 (§9.6), p51 (Fig 11 land) | **3 bugs fixed**: moved to I2C-A (0x59 collided with SGP41 on I2C-B), VDD rewired 3V3_OPTICAL→1V8, GPIO strap to 1V8 added (was absent = float). ECO-H3: 1.8V level-shift segment on I2C-A. Footprint → E1 (pads 0.488×0.575, pitch 0.8, row c-c 1.276) |
| 13 | AS7421 addr + OLGA10 land | **0x64 confirmed**. Package is **6.6×6.0×2.21** (not 3.5×3.5): 2×5 pads 0.6×0.5 @1.25, rows ±2.6, two large center pads (GND / LEDA). **The 4 NIR LEDs (760/830/950/1040nm) are INTEGRATED** — there is no external-LED sink pin; LEDA is their anode supply (abs-max 3.6V) | AS7421_DS000667 p23 (Fig 21), p6-7 (Fig 3/4), p8, p10, p20 (§7.6), p45-46 (Fig 60/61) | **Bug fixed**: deleted the phantom external 970nm LED + 22R chain driven from a nonexistent "LED0" pin; LEDA+EP→3V3_OPTICAL with 10µF pulse bulk; RST/GPIO strapped to GND. Footprint → E1 (real outline) |
| 14 | MLX90632 pinout + SFN land | Pin map 1 SDA 2 VDD 3 GND 4 SCL **5 ADDR (was missing — must be strapped: GND → 0x3A)**; land = 5 pads 0.30×0.25 @0.5 single column + 2.10×2.55 thermal w/ 8 PTH; order code -000 = 3.3V I2C level | MLX90632-Datasheet rev13 p8 (Table 5), p10 (Table 6), p28, p46-47 (Fig 25/26) | ADDR pin added + strapped to GND; EP→GND; footprint replaced `MLX90632_SFN8_3x3` (placeholder DFN-8) → `MLX90632_SFN5_3x3` E1 |
| 15 | MLX90642 package + pin circle | Package IS TO-39 ("SF") **but** pin circle is Ø5.84 with the 4 leads in two **45°-spaced pairs** — the generic KiCad TO-39-4 (90°, Ø5.08) does NOT fit. **Model had pins 2/3 SWAPPED** (2=VDD, 3=GND per DS). **Default addr is 0x66**, not 0x33 (0x33 only if EEPROM SA written to 0x00) | MLX90642-Datasheet rev003 p4 (Table 2 + Fig 1), p16 (Table 19), p6 (NOTE 2), p31 (Fig 34) | **2 bugs fixed**: VDD/GND swap corrected; bus table addr 0x33→0x66. Custom footprint `generated/MLX90642_TO39` E1 replaces TO-39-4 |
| 16 | ESP32-C6 SDIO GPIO map | **Confirmed exactly as wired**: pad 24 IO18=SDIO_CMD, 25 IO19=SDIO_CLK, 26-29 IO20-23=DATA0-3; TXD0=pad 31 (GPIO16), RXD0=pad 30 (GPIO17); GPIO9 boot strap ok | esp32-c6-mini-1 DS v1.5 p10-11 (Table 3-1) | Comment closed (compute.py); no wiring change |
| 17 | BQ27427 sense topology + ball map | Ball map A1 GPOUT A2 SDA A3 SCL B1 BIN B2 VSS B3 VDD C1 VSS C2 SRX C3 BAT (matches official DSBGA-9 footprint). Sense is **HIGH-side** (internal 7mΩ BAT→SRX, "between battery pack and system rail"); **VDD is the 1.8V LDO OUTPUT**; **BIN needs 10k to VSS** (never to a rail); VPU for SDA/SCL/GPOUT 1.62-3.6V; addr 0x55 | bq27427 SLUSEB5B p3 (Table 4-1, Fig 4-1), p4 (§5.3), p16 (§8.5.1.5) | **3 bugs fixed**: SRX was strapped to GND (would short the sense terminal) → now PACKP(BAT)→VBAT(SRX) split; VDD was fed 3V3_AON → now 2.2µF-only LDO out; BIN was tied to VBAT → now 10k to GND. Symbol remapped to real balls; waiver W4 added |
| 18 | CYPD3177 strap values | Straps are **resistor dividers from VDDD** (internal 3.3V LDO, pin 23), not single Rs to GND. 5V min = pin to GND; 9V max = 5.1k/1k; 3A coarse = 5.1k/5.1k; +0 fine = GND. VDDD needs 1µF+2×100nF, VCCD 1µF. FAULT is driven HIGH on fault (not OD-low). QFN-24 4×4 P0.5, EP 2.75 typ | CYPD3177_002-25383 p8 (Tables 2-4), p5-6 (Table 1), p20 (Fig 4) | **Bug fixed**: old 10k/24k/13k/16.9k single-R straps replaced with the DS divider network; VDDD/VCCD pins + caps added; FAULT_N→FAULT (pullup removed); symbol remapped to real QFN-24 pins |
| 19 | MIA-M10Q pad map + RF keepout | Package is **M-LGA53**: 53 pads Ø0.27 on a sparse 9×9 grid @0.5, body 4.5×4.5; land 1:1 copper, NSMD mask Ø0.37, paste=copper. **V_IO (J4) is a required supply that was missing**; VIO_SEL open → 3.3V; RTC_O to GND if unused; D2-E2 tie; F9/G7 0R-to-GND; RF_IN corner B9 | MIA-M10Q DS UBX-22015849 p9-11 (Fig 2/Table 10), p19 (Fig 4); IM UBX-21028173 p83 (§4.5.1) | **Bug fixed**: V_IO wired to 3V3_GNSS; VIO_SEL/RESET_N open; RTC_O/F9/G7 grounded; D2-E2 joined. Footprint: castellated 20-pad placeholder replaced by real 53-pad named map (E1) |
| 20 | ENS161 pinout/land + addr | LGA-9 is a **3×3 pad GRID** (pitch 1.05, leads 0.7 sq, +0.05 land), not a U-perimeter; pin map row-wise 1 8 7 / 2 9 6 / 3 4 5; addr 0x53 (ADDR high) confirmed; VDD 1.71-1.98V (1V8 rail correct); SDA/SCL 3.6V-tol | ENS161-Datasheet v1.1 p5 (Table 1/Fig 2), p7 (Table 2), p41-42 (Table 40/Fig 19) | Wiring confirmed; symbol remapped to real pins (GND=8+9); footprint → E1 3×3 grid |
| 21 | IQS7222A pad map + addr | **0x44 confirmed but only for order code ...001** (code 102 = 0x57) — order IQS7222Axxx001. QFN20 3×3 P0.4 matches official footprint; real pin map extracted; each VREG pin (VREGD 2, VREGA 4) needs its own 2.2µF; MCLR has internal 200k pullup; TAB→VSS. **QFN20 has only 9 sensor pins (CRx0-7+CTx8)** vs our 12-electrode flex | IQS7222A_Datasheet v1.7 p6-7 (Tables 2.2-2.4), p45 (§12.1.2), §9.2 (addr) | Symbol remapped to real pins; VREG caps 1µF×1 → 2.2µF×2; EP→GND. **Real finding**: E9-E11 grounded as guards + ECO-H3 to rework flex to mutual-cap matrix (or 9 electrodes) |
| 22 | TPS22916 WCSP ball order | A1 VOUT, A2 VIN, B1 GND, B2 ON; body 0.78×0.78, 0.4 pitch (numeric-placeholder order was wrong: it had pad1=VIN at the ON corner) | tps22916 SLVSDO5F p3 (Fig 5-1, Table 5-1) | Footprint pads renamed to real balls + symbol remapped (E1) |
| 23 | BQ25620 package + pinout (opportunistic) | **Package is WQFN-18 "RYK" 2.5×3.0 — the footprint in use (WQFN-16 RTE 3×3) was the wrong package.** Real pin map extracted; REGN cap is 4.7µF (had 1µF); CE must not float (ok, 10k down); QON has internal pullup; STAT/PG float ok; D+/D- float (PD contract sets current); addr 0x6B confirmed | bq25620 SLUSEG2D p5-6 (Table 6-1), p37/39 (0x6B), p85-86 (RYK0018A outline + land) | **Bug fixed**: footprint replaced with `generated/BQ25620_WQFN18_RYK` (E1, HR pads approximated — overlay-verify); symbol remapped; REGN 4.7µF; PGND phantom pin removed |
| 24 | TPS62840 pin map (opportunistic) | DLC SON-8: 1 GND 2 VIN 3 MODE 4 EN 5 VSET 6 STOP 7 SW 8 VOS. **VSET was missing from the model — output voltage was undefined**; 3.3V needs RSET=267k. MODE "must be terminated" (was ok, GND) | tps62840 SLVSEC6D p4-5 (Pin Functions), p22 (Table 1) | **Bug fixed**: VSET 267k→GND + STOP→GND added; symbol remapped to real pins |
| 25 | TPS62823 / TLV62568 / DRV2605L / BQ29700 pin maps (opportunistic) | TPS62823: **no MODE pin exists** (model had a phantom one, tied to GND); real map 1 EN 2 FB 3 AGND 4 NC 5 PGND 6 SW 7 VIN 8 PG. TLV62568 SOT-23-5: **3=SW 4=VIN 5=FB** (model had 3=VIN 4=FB 5=SW). DRV2605L VSSOP-10: **REG (pin 1) 1µF was missing**; pin 6 VDD/NC→VDD. BQ29700 DSE: 1 NC 2 COUT 3 DOUT 4 VSS 5 BAT 6 V-; 330R VDD RC confirmed | tps62823 SLVSDV6C p3; tlv62568 SLVSD89B p3; drv2605l SLOS854D p5; bq2970_family p3+p14 | **4 symbol pin-map bugs fixed**; DRV2605L REG cap added; TPS62823 MODE ties removed (PG/NC float per DS) |
| 26 | SHT41 / SCD41 / BNO086 addr re-check (opportunistic) | SHT41: 0x44 belongs to the **SHT41-AD1B** ordering code (0x45/0x46 exist) — BOM must call out AD1B. SCD41: 0x62 confirmed. BNO086: BNO08x DS is the same doc already used to close #6 (PS1/PS0 straps, SPI) — no change | SHT4x DS v7.1 p2/p7; SCD4x DS p9 (§3.4); BNO08x-Datasheet | Bus-table comments updated; ordering note in sensors_i2c.py docstring |

## Closed — H2.5 round 3 (2026-07-12, second same-day drop)

| # | Item | Verdict | Evidence | Circuit action |
|---|---|---|---|---|
| 27 | SGX-4CO cell drawing (pin circle) | Body **Ø20**, h 16.50 + 3.90 pins; **3 pins Ø1.55 on a 13.5 mm PCD** — the footprint's 9 mm PCD guess was WRONG. **Pins must NOT be glued/soldered — PSB socket receptacles only** (p3 note 1, warranty) → cell is field-replaceable (strengthens the R2 serviceability story). The pin-face drawing (Working top, Reference lower-left, Counter lower-right) shows the pin ends face-on = **BOTTOM view** → top-view footprint must mirror it: WE top, RE lower-RIGHT, CE lower-LEFT. Electricals: 70±20 nA/ppm, 10 Ω load, >20k ppm·h filter, >24 mo in air, −30..+50 °C, IS data 1.3 V o/c max | DS-0138 SGX-4CO Issue 3 p1 (outline + pin-face drawing), p3 (note 1), p1 tables | Footprint → E1: 13.5 PCD, drill 1.7 for Ø1.55-pin receptacles, pad 2.5, RE/CE mirrored for top view; BOM note = 3× PSB socket receptacles, do-not-solder. **ECO-H3**: pads at ±6.75 + annulus exceed the ratified 14×14 CO-cell envelope — gas_b zone repack absorbs it (board NOT rebuilt at H2.5) |
| 28 | LMP91000 pin map + addr | Real WSON-14 map: **1 DGND, 2 MENB (act-low), 3 SCL, 4 SDA, 5 NC, 6 VDD, 7 AGND, 8 VOUT, 9 C2, 10 C1, 11 VREF, 12 WE, 13 RE, 14 CE, DAP→AGND**. Old model was 11 sequentially-numbered pins with one GND and NO VREF/NC — netlist binds pads by number, so the WSON-14 would have been scrambled (SCL on VOUT etc.). Addr **0x48 confirmed** (fixed 1001000). MENB may tie to GND when sole LMP91000 on the bus. REFCN default 0x20 → REF_SOURCE = **internal (VDD) reference** | SNAS506I p3 (Pin Functions), p20 (§7.5.1 addr, §7.5.2 MENB), p22 (§7.6.4 REFCN) | **Bug fixed**: symbol renumbered to real pins; AGND/DGND split (both → GND); **VREF added** (0R to AIR rail — internal-ref register default, external-ref option preserved for H3); NC pin 5 + DAP-as-pin-15 EP added; MENB→GND retained (legal per §7.5.2). Manifest: WSON-14 entry → E1 notes |
| 29 | BL54L15 pad map + land pattern + antenna keepout | Full **39-pad map** extracted; GND = 1/16/27/39, VDD_nRF = 26 (1.7–3.5 V), SWDIO/SWDCLK/NRESET = 5/6/7, UARTE00 TXD/RXD = 3 (P2.08)/4 (P2.07), I2C = 10 (P2.01, dedicated CLK pin)/9 (P2.00, adjacent per Note 2), NFC = 15/14, XL1/XL2 = 25/24 (optional 32 kHz crystal — reserved NC), Geiger count in = 31 (P0.04, GRTC clock-capable); all EN/INT/GPIO assignments as wired (P0.x/P1.x/P2.x per lib_parts comments). Land pattern: pads **0.45×0.60 @ 0.75** in a U (bottom 1-16 span 11.25, pin 1 at antenna end; left 17-27 span 7.50; top 28-39 span 8.25); module 14×10. **Antenna keep-out: 5.00×8.50 no-copper-any-layer under the antenna end + ≥15 mm beyond BOTH board edges; module must sit on the host-PCB edge** (dev-board reference ~5×28.6) | EZ-DS-BL54L15 v1.9 Table 1 p10-13 (pin map + notes), Fig 11 p25 (land + keep-out), §7.3.1 p21, §7.3.2 p22 (metal ≥20-40 mm) | Symbol renumbered from sequential E0 to real pads; **3 missing GND pads + XL1/XL2 added** (crystal pads NC with reservation comment). Footprint: 32-pad numeric castellated placeholder replaced by real 39-pad E1 land with keep-out drawn on Dwgs.User. **ECO-H3**: keep-out + mandatory board-edge placement constrain the radio_ble floorplan corner — verify at zone repack |

## Closed — H2.6 final wave (2026-07-12, ST datasheet drop)

| # | Item | Verdict | Evidence | Circuit action |
|---|---|---|---|---|
| 30 | STM32N657 VFBGA142 ball map (**was the routing blocker**) | **Full 142-ball map extracted** (count = 142 exactly, no dupes; grid 15×15 rows A-R × cols 1-15, 0.5 pitch, body 8×8, D1/E1 7.00, ball Ø0.31 typ). Package constrains peripherals: **I2C1 not bonded** (bus A → I2C2 PB10/PB11, bus B → I2C4 PE13/PE14); **USART2_RX not bonded** (sentinel link → UART4 PA12/PA11); SDMMC1 CMD is on **PH2** (not PD2); XSPI boot flash = dedicated PN port (XSPIM_P2, DQS0/NCS1/IO0-7/CLK = PN0/PN1/PN2-5+PN8-11/PN6); **BOOT1 = PA6** (non-dedicated boot pin §3.6). IO domains (Table 18 fn 1/6/9): GPIO→VDD, SDMMC group→VDDIO4, PN port→VDDIO3. Supply audit (Table 24 p139, §3.4 p25-27): VDDCORE 0.782-0.842 V VOS-low / 0.858-0.921 V VOS-high (800 MHz); **PWR_ON handshake required with an external VCORE supply** (Fig 3 p27); SMPS bypass config = VDDSMPS/VDDA18PMU still fed 1.8 V, VLXSMPS/VFBSMPS floating (Fig 2 p26); "VDD must be present before any other supply" (Table 24 fn1); USB RTXRTUNE **200 Ω** (Table 123 p219), CSI REXT **200 Ω** (Table 122 p218); HSE 16-48 MHz (p13) | DS14791 Rev 9: Table 18 p88-112, Fig 7 p87, Table 24 p139-140, §3.4.4/3.4.7 p26-27, §3.6 p14, Tables 122/123 p218-219, Fig 67 + Table 128 p235-236 | Symbol rebuilt with all 142 real balls (24 NC modeled). **5 real bugs fixed:** (1) core buck FB 100k/110k = **1.145 V** on a 0.921 V-max rail → 34.8k/100k = 0.809 V + Q_VSEL/255k leg → 0.891 V under `N6_VCORE_SEL` (800 MHz overdrive); (2) 3V3_SYS FB 332k/100k = **2.59 V** → 449k/100k = 3.294 V; (3) 1V8 FB 187k/100k = 1.72 V → 200k/100k = 1.800 V (TPS62823/TLV62568 VFB=0.6 V re-verified in their DS); (4) **no HSE crystal existed** — USB-HS PHY PLL can't run from HSI RC → X_HSE 48 MHz 3225 added on PH0/PH1; (5) core buck EN moved EN_N6 → **PWR_ON** (D2) per Fig 3, 1V8 EN moved EN_N6 → 3V3_SYS rail (VDD-first sequencing). VBAT→3V3_AON (RTC alive in ambient), PDR_ON→1V8, V08CAP cap added, TXRTUNE/REXT 200 Ω fitted. Footprint: numeric placeholder **deleted** → `generated/ST_VFBGA142` E1. **Board file now stale — H3 rebuild** (noted in H2_REPORT) |
| 31 | VL53L8CH exact DS (was anchored on VL53L8CX) | **CH-specific DS confirms the CX anchor 1:1**: pin map identical (Table 3 p7 — A1 GPIO1/INT, A2 LPn, A3 IOVDD, A4 SDA/MOSI, A5 SCL/MCLK, A6/A7 RSVD→GND, B1 GPIO2, B4 thermal→GND, B7 CORE_1V8, C1 SPI_I2C_N, C2 NCS, C4 AVDD 3.3V, C5 MISO); **IOVDD 1.2/1.8 V only re-confirmed** (ECO-H3 stands); SPI strap = C1 **via 47 kΩ** to IOVDD (not a hard tie), NCS needs its own 47 k pullup. Fig 30 p33 gives the real substrate pad drawing: 14 pads 0.500×0.515 @ 0.750 non-cumulative, rows 2.115 c-c, B1/B7 0.535×0.500, B4 thermal 2.316×1.200, margins check vs the 0.100 pad-to-substrate callout | VL53L8CH DS14310 Rev 9 p1-2, Table 3 p7, Fig 30 p33, §10 notes p32 (thermal pad required, AN5897) | Straps corrected: SPI_I2C_N direct tie → 47 k pullup; 47 k pullup added on CS_VL53_N. Footprint `ST_VL53L8_LGA16` regenerated from the real drawing (pitch was E0-guessed 0.85/1.0 → real 0.75/2.115) → **E1** |
| 32 | VD66GY capture (DNP in v1) | Part is a **bare die** (115 bonding pads) — the FPC mates a module built on it. Supplies **2.8 V (VANA) / 1.8 V (VDDIO) / 1.15 V (VCORE)**; MIPI CSI-2 **1-2 lanes ≤1.5 Gbps/lane** (2-lane wiring OK, N657 PHY OK); **XSHUTDOWN active-low** (CAM_RSTN polarity ✓); **CLKIN external clock required** (CAM_XCLK ✓); I2C control (CCI on I2C-A ✓) | VD66GY DS13838 Rev 9 p2/p4 (Table 2), p12, Table 6 p15 | No rewire (DNP). **ECO-H3 note** on J_CAM: FPC carries only 3V3_OPTICAL + 1V8 — module must carry local 2.8 V + 1.15 V LDOs, or repurpose two reserved pins (19-24) as rail feeds |
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

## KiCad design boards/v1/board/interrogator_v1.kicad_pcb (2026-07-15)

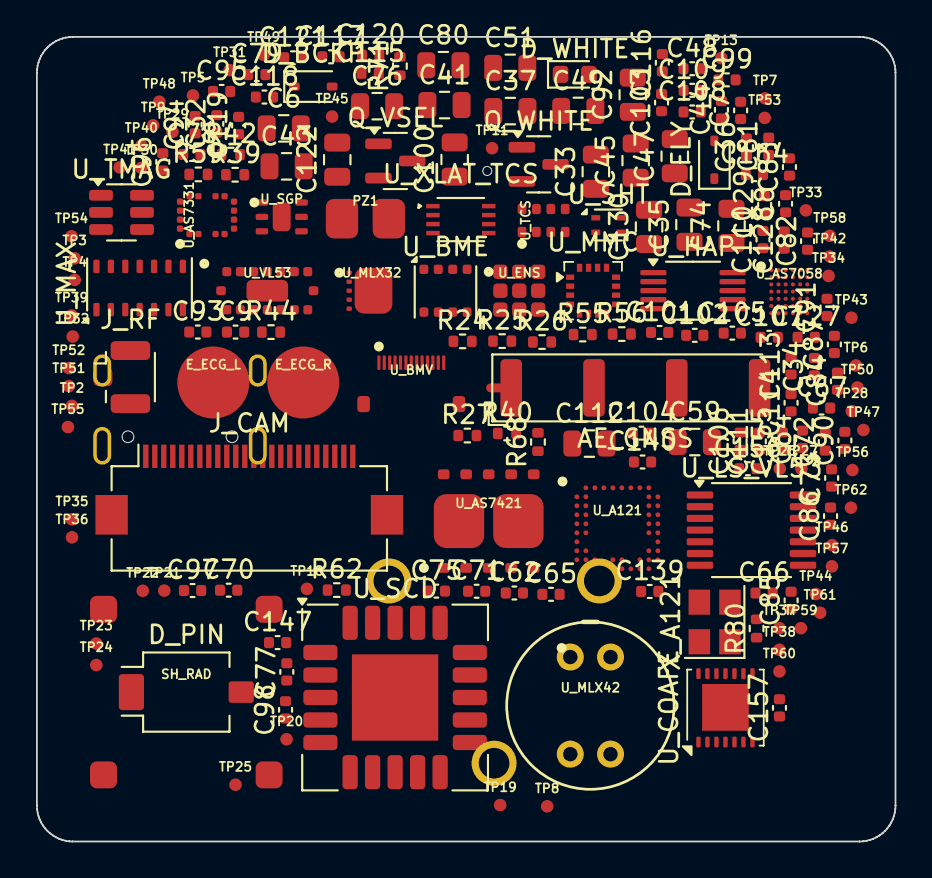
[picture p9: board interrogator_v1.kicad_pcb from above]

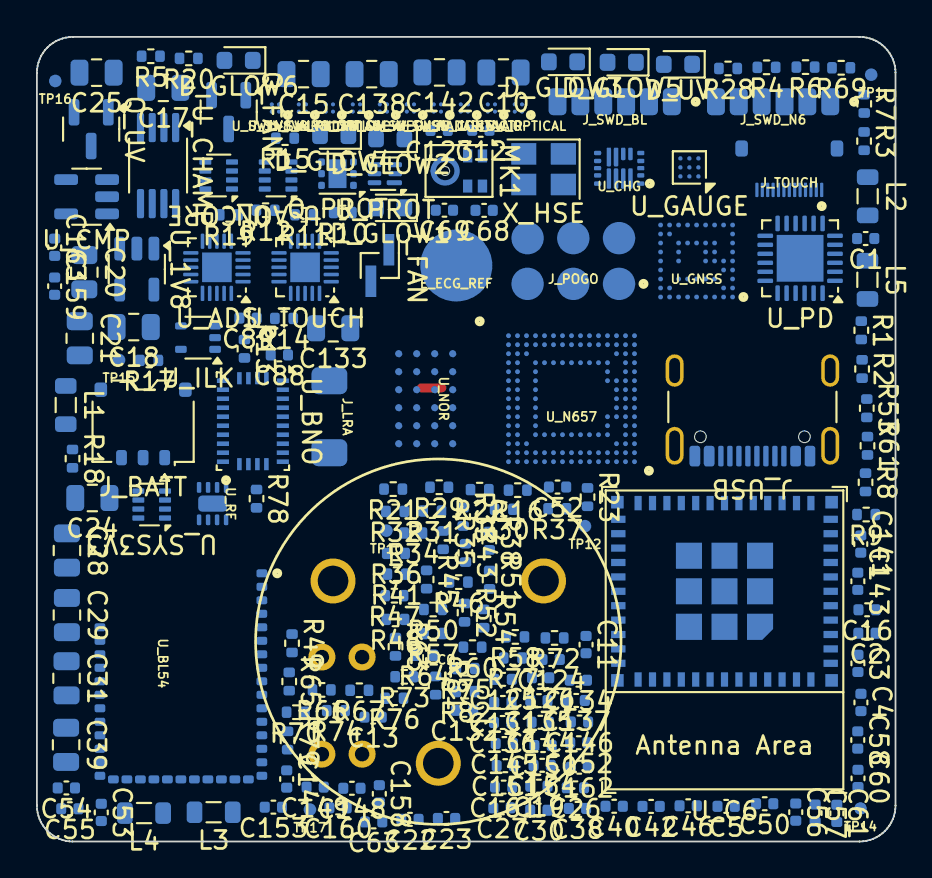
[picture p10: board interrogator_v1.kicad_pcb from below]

Board: 6 copper layers, 47.7 x 44.7 mm, 400 parts (209 on the bottom side), 237 nets, no tracks yet.

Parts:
AE_GNSS: Antenova_SR4G013_GPS
C1, C2, C3, C4, C5, C7, C8, C9, C11, C12, C13, C14, C16, C19, C22, C23, C26, C27, C30, C32, C34, C36, C38, C40, C42, C44, C46, C48, C50, C52, C53, C54, C55, C56, C57, C58, C60, C61, C62, C63, C64, C65, C66, C67, C68, C69, C70, C71, C72, C73, C75, C77, C78, C79, C81, C82, C83, C84, C85, C86, C87, C88, C89, C90, C91, C93, C94, C95, C96, C97, C98, C99, C101, C102, C103, C104, C105, C106, C107, C108, C109, C110, C111, C113, C114, C115, C116, C117, C118, C119, C120, C121, C123, C124, C125, C126, C127, C128, C129, C131, C132, C134, C135, C136, C137, C139, C140, C141, C143, C144, C145, C146, C147, C148, C149, C150, C151, C152, C153, C154, C155, C156, C157, C158, C159, C160, C161, C162, C163, C164: C_0402_1005Metric
C6, C10, C15, C17, C18, C20, C21, C24, C25, C28, C29, C31, C33, C35, C37, C39, C41, C43, C45, C47, C49, C51, C59, C74, C76, C80, C92, C100, C112, C122, C130, C133, C138, C142: C_0805_2012Metric
D_BCKP: D_SOD-323
D_FLY: D_SOD-323
D_GLOW1, D_GLOW2, D_GLOW3, D_GLOW4, D_GLOW5, D_GLOW6: LED_0603_1608Metric
D_PIN: Osram_BPW34S-SMD
D_UV: LED_0603_1608Metric
D_WHITE: LED_0603_1608Metric
E_ECG_L: ELECTRODE_LAND_4MM
E_ECG_R: ELECTRODE_LAND_4MM
E_ECG_REF: ELECTRODE_LAND_4MM
J_BATT: JST_ACH_BM03B-ACHSS-GAN-ETF_1x03-1MP_P1.20mm_Vert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; JST_ACH_BM03B-ACHSS-GAN-ETF_1x03-1MP_P1.20mm_Vertical
J_CAM: Hirose_FH12-24S-0.5SH_1x24-1MP_P0.50mm_Horizontal
J_FAN: PinHeader_1x02_P1.00mm_Vertical_SMD_Pin1Left
J_LRA: LRA_PADS
J_POGO: POGO6_COMPACT
J_RF: U.FL_Hirose_U.FL-R-SMT-1_Vertical
J_SWD_BL: SWD_PADROW_6
J_SWD_N6: SWD_PADROW_6
J_TOUCH: ZIF13_MOLEX_503566
J_USB: USB_C_Receptacle_GCT_USB4105-xx-A_16P_TopMnt_Hori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; USB_C_Receptacle_GCT_USB4105-xx-A_16P_TopMnt_Horizontal
L1, L2, L3, L4, L5: L_0805_2012Metric
MK1: Knowles_LGA-5_3.5x2.65mm
PZ1: PIEZO_DISC_PADS
Q_FAN: SOT-23
Q_PROT: WSON-6-1EP_2x2mm_P0.65mm_EP1x1.6mm
Q_UV: SOT-23
Q_VSEL: SOT-23
Q_WHITE: SOT-23
R1, R2, R3, R4, R5, R6, R7, R8, R9, R10, R11, R12, R13, R14, R15, R16, R17, R18, R19, R20, R21, R22, R23, R24, R25, R26, R27, R28, R29, R30, R31, R32, R33, R34, R35, R36, R37, R38, R39, R40, R41, R42, R43, R44, R45, R46, R47, R48, R49, R50, R51, R52, R53, R54, R55, R56, R57, R58, R59, R60, R61, R62, R63, R64, R65, R66, R67, R68, R69, R70, R71, R72, R73, R74, R75, R76, R77, R78, R79, R80, R81, R82: R_0402_1005Metric
SH_RAD: SHIELD_CAN_RAD_10x10
TP1, TP2, TP3, TP4, TP5, TP6, TP7, TP8, TP9, TP10, TP11, TP12, TP13, TP14, TP15, TP16, TP17, TP18, TP19, TP20, TP21, TP22, TP23, TP24, TP25, TP26, TP27, TP28, TP29, TP30, TP31, TP32, TP33, TP34, TP35, TP36, TP37, TP38, TP39, TP40, TP41, TP42, TP43, TP44, TP45, TP46, TP47, TP48, TP49, TP50, TP51, TP52, TP53, TP54, TP55, TP56, TP57, TP58, TP59, TP60, TP61, TP62: TESTPOINT_PAD_0.8MM
U_1V8: SOT-23-5
U_A121: A121_fcCSP50
U_ADS: QFN-20-1EP_3x3mm_P0.4mm_EP1.65x1.65mm
U_AON: SOT-583-8
U_AS7058: AS7058_WLCSP42
U_AS7331: AS7331_OLGA16
U_AS7421: AS7421_OLGA10
U_BL54: BL54L15_MODULE
U_BME: Bosch_LGA-8_3x3mm_P0.8mm_ClockwisePinNumbering
U_BMV: BMV080_Molex_503566-1302_ZIF13
U_BNO: LGA-28_5.2x3.8mm_P0.5mm
U_C6: ESP32-C6-MINI-1
U_CHAMP: MSOP-8_3x3mm_P0.65mm
U_CHG: BQ25620_WQFN18_RYK
U_CMP: SOT-23-5
U_CO: SGX_4CO_4SERIES_TH
U_COAFE: WSON-14-1EP_4.0x4.0mm_P0.5mm_EP2.6x2.6mm
U_CORE: SOT-583-8
U_ENS: ENS161_LGA9
U_GAUGE: Texas_DSBGA-9_1.62mmx1.58mm_Layout3x3_P0.5mm
U_GNSS: UBLOX_MIA_M10Q
U_HAP: VSSOP-10_3x3mm_P0.5mm
U_ILK: SOT-353_SC-70-5
U_LS_VL53: TSSOP-14_4.4x5mm_P0.65mm
U_MAX: Maxim_OLGA-14_3.3x5.6mm_P0.8mm
U_MLX32: MLX90632_SFN5_3x3
U_MLX42: MLX90642_TO39
U_MMC: LGA-16_3x3mm_P0.5mm
U_N657: ST_VFBGA142
U_NOR: NOR_BGA24_6x8
U_PD: HVQFN-24-1EP_4x4mm_P0.5mm_EP2.6x2.6mm
U_PROT: WSON6_1.5x1.5mm_P0.5mm; WSON-6_1.5x1.5mm_P0.5mm
U_RF: AD8317_LFCSP8_2x3
U_SCD: Sensirion_SCD4x-1EP_10.1x10.1mm_P1.25mm_EP4.8x4.8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; Sensirion_SCD4x-1EP_10.1x10.1mm_P1.25mm_EP4.8x4.8mm
U_SGP: SGP41_DFN6_2.44x2.44
U_SHT: Sensirion_DFN-4_1.5x1.5mm_P0.8mm_SHT4x_NoCentralP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; Sensirion_DFN-4_1.5x1.5mm_P0.8mm_SHT4x_NoCentralPad
U_SW1V8_AIR, U_SW1V8_OPTICAL, U_SW1V8_RADAR: TPS22916_CSP4
U_SW_ACC: TPS22916_CSP4
U_SW_AIR: TPS22916_CSP4
U_SW_CONTACT: TPS22916_CSP4
U_SW_GNSS: TPS22916_CSP4
U_SW_OPTICAL: TPS22916_CSP4
U_SW_RADAR: TPS22916_CSP4
U_SW_WIFI: TPS22916_CSP4
U_SYS3V3: SOT-583-8
U_TCS: TCS3448_OLGA8
U_TMAG: SOT-23-6
U_TOUCH: QFN-20-1EP_3x3mm_P0.4mm_EP1.65x1.65mm
U_VL53: ST_VL53L8_LGA16
U_XLAT_TCS: VSSOP-8_2.4x2.1mm_P0.5mm
X_A121: Crystal_SMD_3225-4Pin_3.2x2.5mm
X_HSE: Crystal_SMD_3225-4Pin_3.2x2.5mm

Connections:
1V8: C30.1, C31.1, C54.1, C60.1, C61.1, C62.1, C63.1, C70.1, C71.1, C97.1, C98.1, J_CAM.17, L5.2, R19.1, R31.2, TP20.1, U_MAX.11, U_N657.A1, U_N657.D4, U_N657.E4, U_N657.F1, U_N657.J1, U_N657.J2, U_N657.J3, U_N657.K4, U_N657.K12, U_N657.L12, U_N657.P2, U_N657.R3, U_N657.R7, U_NOR.1, U_SW1V8_AIR.A2, U_SW1V8_OPTICAL.A2, U_SW1V8_RADAR.A2
1V8_AIR: C48.1, C49.1, C108.1, C109.1, TP13.1, U_ENS.4, U_SW1V8_AIR.A1
1V8_OPTICAL: C44.1, C45.1, C81.1, C82.1, C83.1, C115.1, C116.1, R39.2, R40.2, R42.2, R44.2, R55.2, R56.2, TP11.1, U_LS_VL53.13, U_LS_VL53.14, U_SW1V8_OPTICAL.A1, U_TCS.1, U_TCS.6, U_VL53.A3, U_VL53.B7, U_XLAT_TCS.2
1V8_RADAR: C46.1, C47.1, C134.1, C135.1, C136.1, C137.1, C138.1, TP12.1, U_A121.C2, U_A121.C9, U_A121.D1, U_A121.D10, U_A121.J9, U_SW1V8_RADAR.A1
3V3_AIR: C34.1, C35.1, C104.1, C105.1, C106.1, C107.1, C110.1, C111.1, C112.1, C113.1, C114.1, C127.1, C128.1, C129.1, C130.1, C155.1, C156.1, R80.1, TP6.1, U_BME.2, U_BME.5, U_BME.6, U_BME.8, U_BMV.1, U_BMV.3, U_BMV.4, U_BMV.7, U_BMV.8, U_BMV.10, U_BMV.11, U_COAFE.6, U_ENS.3, U_ENS.5, U_ENS.7, U_SCD.7, U_SCD.19, U_SGP.1, U_SGP.5, U_SHT.3, U_SW_AIR.A1
3V3_AON: C19.1, C20.1, C53.1, C72.1, C73.1, C74.1, C145.1, C146.1, C158.1, C159.1, C162.1, C163.1, D_BCKP.2, J_SWD_BL.1, L2.2, R32.2, R33.2, R34.2, R35.2, R36.2, R62.1, R63.1, R66.1, R81.2, R82.2, TP17.1, U_AON.8, U_BL54.26, U_CHAMP.1, U_CMP.1, U_HAP.6, U_HAP.10, U_N657.D1, U_TOUCH.1
3V3_CONTACT: C36.1, C37.1, C99.1, C100.1, C101.1, C102.1, C103.1, TP7.1, U_AS7058.A1, U_AS7058.A2, U_MAX.9, U_MAX.10, U_SW_CONTACT.A1
3V3_GNSS: C40.1, C41.1, C141.1, C142.1, TP9.1, U_GNSS.B1, U_GNSS.J4, U_SW_GNSS.A1
3V3_OPTICAL: C32.1, C33.1, C78.1, C79.1, C80.1, C93.1, C94.1, C95.1, C96.1, C117.1, C118.1, C119.1, C120.1, C121.1, C122.1, J_CAM.16, R69.1, R71.1, TP5.1, U_AS7331.3, U_AS7331.10, U_AS7421.2, U_AS7421.6, U_AS7421.12, U_MLX32.2, U_MLX42.2, U_SW_OPTICAL.A1, U_VL53.C4
3V3_RADAR: C38.1, C39.1, C131.1, C132.1, C133.1, TP8.1, U_A121.F10, U_A121.J1, U_A121.K9, U_SW_RADAR.A1
3V3_SYS: C26.1, C27.1, C28.1, C64.1, C65.1, C66.1, C67.1, C84.1, C85.1, C86.1, C87.1, C90.1, C91.1, C92.1, C123.1, C124.1, C125.1, C126.1, C144.1, C150.1, C151.1, C154.1, J_SWD_N6.1, L4.2, MK1.1, R17.1, R24.2, R25.2, R26.2, R27.2, R28.2, R41.2, R45.2, R46.2, R47.2, R48.2, R49.2, R50.2, R53.2, R54.2, R57.2, R58.2, R60.2, R61.2, TP18.1, U_1V8.1, U_ADS.18, U_ADS.19, U_BNO.3, U_BNO.5, U_BNO.10, U_BNO.28, U_ILK.5, U_LS_VL53.1, U_MMC.1, U_MMC.2, U_N657.B6, U_N657.D8, U_N657.F12, U_N657.G12, U_N657.H12, U_RF.1, U_SW_AIR.A2, U_SW_CONTACT.A2, U_SW_GNSS.A2, U_SW_OPTICAL.A2, U_SW_RADAR.A2, U_SW_WIFI.A2, U_TMAG.5
3V3_WIFI: C42.1, C43.1, C75.1, C76.1, R37.1, R38.2, TP10.1, U_C6.3, U_SW_WIFI.A1
A121_XIN: C139.1, U_A121.J10, X_A121.1
A121_XOUT: C140.1, U_A121.H10, X_A121.3
ACC_AN1: E_ECG_REF.1, J_POGO.5, TP53.1, U_AS7058.B3
ACC_AN2: J_POGO.6, TP45.1, U_ADS.5
ADS_CAP: C89.1, U_ADS.16
AS7331_REXT: R59.1, U_AS7331.4
ATTN_N6: TP60.1, U_BL54.18, U_N657.N3
BATT_NTC: J_BATT.2, R10.2, R11.1, U_CHG.6
BL_RESET_N: J_SWD_BL.3, R36.1, U_BL54.7
BL_SWCLK: J_SWD_BL.4, TP43.1, U_BL54.6
BL_SWDIO: J_SWD_BL.2, TP42.1, U_BL54.5
BL_SWO: J_SWD_BL.6, TP49.1
BNO_CAP: C88.1, U_BNO.9
BNO_ENV_SCL: R48.1, U_BNO.15
BNO_ENV_SDA: R49.1, U_BNO.16
BNO_PS0_WAKE: R45.1, TP44.1, U_BNO.6
C6_BOOT: R38.1, TP25.1, U_C6.23
C6_EN: C77.1, R37.2, U_C6.8
C6_RXD0: TP24.1, U_C6.30
C6_TXD0: TP23.1, U_C6.31
CAM_RSTN: J_CAM.12, U_N657.C15
CAM_XCLK: J_CAM.11, U_N657.A13
CC1: J_USB.A5, U_PD.15
CC2: J_USB.B5, U_PD.14
CELL_N: C7.2, J_BATT.3, Q_PROT.1, U_PROT.4
CHG_INT_N: R35.1, U_BL54.13, U_CHG.11
CLK_ADS: TP58.1, U_ADS.15, U_N657.M11
CO_AFE_OUT: TP46.1, U_ADS.8, U_COAFE.8
CO_CE: U_CO.3, U_COAFE.14
CO_RE: U_CO.2, U_COAFE.13
CO_VREF: R80.2, U_COAFE.11
CO_WE: U_CO.1, U_COAFE.12
CSI_CKN: J_CAM.3, U_N657.P5
CSI_CKP: J_CAM.2, U_N657.R5
CSI_D0N: J_CAM.6, U_N657.P6
CSI_D0P: J_CAM.5, U_N657.R6
CSI_D1N: J_CAM.9, U_N657.P4
CSI_D1P: J_CAM.8, U_N657.R4
CS_A121_N: U_A121.J2, U_N657.B11
CS_ADS_N: U_ADS.10, U_N657.B13
CS_BNO_N: U_BNO.18, U_N657.N13
CS_VL53_N: R41.1, U_LS_VL53.4, U_N657.C13
DRDY_ADS: U_ADS.11, U_N657.B15
DRDY_MMC: U_MMC.6, U_N657.K1
ECG_INN: E_ECG_R.1, U_AS7058.B2
ECG_INP: E_ECG_L.1, U_AS7058.B1
EN_ACC: U_BL54.33, U_SW_ACC.B2
EN_AIR: U_BL54.21, U_SW1V8_AIR.B2, U_SW_AIR.B2
EN_CONTACT: U_BL54.22, U_SW_CONTACT.B2
EN_FAN: R79.1, U_BL54.32
EN_GNSS: U_BL54.28, U_SW_GNSS.B2
EN_HAPTIC: U_BL54.34, U_HAP.5
EN_N6: TP61.1, U_BL54.30, U_SYS3V3.1
EN_OPTICAL: R57.1, U_BL54.20, U_SW1V8_OPTICAL.B2, U_SW_OPTICAL.B2, U_XLAT_TCS.7, U_XLAT_TCS.8
EN_RADAR: U_BL54.23, U_SW1V8_RADAR.B2, U_SW_RADAR.B2
EN_UV_REQ: U_ILK.1, U_N657.L2
EN_WHITE: R72.1, U_N657.M1
EN_WIFI: U_BL54.29, U_SW_WIFI.B2
FAN_N: D_FLY.2, J_FAN.2, Q_FAN.3
GAUGE_INT_N: R34.1, U_BL54.36, U_GAUGE.A1
GAUGE_VDD: C9.1, U_GAUGE.B3
GEIGER_PULSE: TP47.1, U_BL54.31, U_CMP.5
GLOW1: R73.1, U_BL54.2
GLOW1_A: D_GLOW1.2, R73.2
GLOW2: R74.1, U_BL54.8
GLOW2_A: D_GLOW2.2, R74.2
GLOW3: R75.1, U_BL54.11
GLOW3_A: D_GLOW3.2, R75.2
GLOW4: R76.1, U_BL54.12
GLOW4_A: D_GLOW4.2, R76.2
GLOW5: R77.1, U_BL54.37
GLOW5_A: D_GLOW5.2, R77.2
GLOW6: R78.1, U_BL54.38
GLOW6_A: D_GLOW6.2, R78.2
GND: AE_GNSS.2, C1.2, C2.2, C3.2, C4.2, C5.2, C6.2, C8.2, C9.2, C10.2, C11.2, C13.2, C14.2, C15.2, C16.2, C17.2, C18.2, C19.2, C20.2, C21.2, C22.2, C23.2, C24.2, C25.2, C26.2, C27.2, C28.2, C29.2, C30.2, C31.2, C32.2, C33.2, C34.2, C35.2, C36.2, C37.2, C38.2, C39.2, C40.2, C41.2, C42.2, C43.2, C44.2, C45.2, C46.2, C47.2, C48.2, C49.2, C50.2, C51.2, C52.2, C53.2, C54.2, C55.2, C56.2, C57.2, C58.2, C59.2, C60.2, C61.2, C62.2, C63.2, C64.2, C65.2, C66.2, C67.2, C68.2, C69.2, C70.2, C71.2, C72.2, C73.2, C74.2, C75.2, C76.2, C77.2, C78.2, C79.2, C80.2, C81.2, C82.2, C83.2, C84.2, C85.2, C86.2, C87.2, C88.2, C89.2, C90.2, C91.2, C92.2, C93.2, C94.2, C95.2, C96.2, C97.2, C98.2, C99.2, C100.2, C101.2, C102.2, C103.2, C104.2, C105.2, C106.2, C107.2, C108.2, C109.2, C110.2, C111.2, C112.2, C113.2, C114.2, C115.2, C116.2, C117.2, C118.2, C119.2, C120.2, C121.2, C122.2, C123.2, C124.2, C125.2, C126.2, C127.2, C128.2, C129.2, C130.2, C131.2, C132.2, C133.2, C134.2, C135.2, C136.2, C137.2, C138.2, C139.2, C140.2, C141.2, C142.2, C143.2, C144.2, C145.2, C146.2, C147.2, C148.2, C150.2, C151.2, C153.2, C154.2, C155.2, C156.2, C158.2, C159.2, C160.2, C161.2, C162.2, C163.2, C164.2, D_GLOW1.1, D_GLOW2.1, D_GLOW3.1, D_GLOW4.1, D_GLOW5.1, D_GLOW6.1, J_BATT.MP, J_CAM.1, J_CAM.4, J_CAM.7, J_CAM.10, J_CAM.15, J_CAM.18, J_CAM.MP, J_POGO.2, J_RF.2, J_SWD_BL.5, J_SWD_N6.5, J_TOUCH.10, J_TOUCH.11, J_TOUCH.12, J_TOUCH.13, J_TOUCH.MP1, J_TOUCH.MP2, J_USB.A1, J_USB.A12, J_USB.B1, J_USB.B12, J_USB.S1, MK1.2, MK1.5, Q_FAN.2, Q_PROT.6, Q_UV.2, Q_VSEL.2, Q_WHITE.2, R2.2, R4.2, R6.2, R7.2, R8.2, R11.2, R12.2, R14.2, R16.2, R18.2, R20.2, R21.2, R22.2, R23.2, R29.2, R30.2, R43.2, R51.2, R52.2, R59.2, R64.2, R67.2, R68.2, TP50.1, U_1V8.2, U_A121.A2, U_A121.A3, U_A121.A4, U_A121.A5, U_A121.A6, U_A121.A7, U_A121.A8, U_A121.A9, U_A121.B1, U_A121.B2, U_A121.B9, U_A121.B10, U_A121.C1, U_A121.C10, U_A121.D2, U_A121.D9, U_A121.E1, U_A121.E2, U_A121.E9, U_A121.E10, U_A121.F1, U_A121.F2, U_A121.F9, U_A121.G1, U_A121.G10, U_A121.H1, U_A121.H2, U_A121.H9, U_A121.J3, U_A121.J5, U_A121.J6, U_A121.J8, U_A121.K4, U_A121.K5, U_A121.K7, U_ADS.3, U_ADS.6, U_ADS.7, U_ADS.17, U_ADS.20, U_ADS.21, U_AON.1, U_AON.3, U_AON.6, U_AS7058.A3, U_AS7331.1, U_AS7331.2, U_AS7331.5, U_AS7331.6, U_AS7331.7, U_AS7331.8, U_AS7331.11, U_AS7331.14, U_AS7331.15, U_AS7331.16, U_AS7421.3, U_AS7421.4, U_AS7421.5, U_AS7421.7, U_AS7421.8, U_AS7421.11, U_BL54.1, U_BL54.16, U_BL54.27, U_BL54.39, U_BME.1, U_BME.7, U_BMV.2, U_BMV.9, U_BMV.MP1, U_BMV.MP2, U_BNO.2, U_BNO.25, U_C6.1, U_C6.2, U_C6.11, U_C6.14, U_C6.36, U_C6.37, U_C6.38, U_C6.39, U_C6.40, U_C6.41, U_C6.42, U_C6.43, U_C6.44, U_C6.45, U_C6.46, U_C6.47, U_C6.48, U_C6.49, U_C6.50, U_C6.51, U_C6.52, U_C6.53, U_CHAMP.2, U_CHG.15, U_CMP.2, U_COAFE.1, U_COAFE.2, U_COAFE.7, U_COAFE.15, U_CORE.3, U_CORE.5, U_ENS.8, U_ENS.9, U_GAUGE.B2, U_GAUGE.C1, U_GNSS.A1, U_GNSS.A2, U_GNSS.A3, U_GNSS.A5, U_GNSS.A8, U_GNSS.A9, U_GNSS.B2, U_GNSS.B8, U_GNSS.C3, U_GNSS.C9, U_GNSS.E3, U_GNSS.E4, U_GNSS.E9, U_GNSS.F1, U_GNSS.F3, U_GNSS.F4, U_GNSS.F9, U_GNSS.G3, U_GNSS.G4, U_GNSS.G5, U_GNSS.G6, U_GNSS.G7, U_GNSS.H8, U_GNSS.J8, U_GNSS.J9, U_HAP.4, U_HAP.8, U_ILK.3, U_LS_VL53.7, U_MAX.4, U_MAX.12, U_MLX32.3, U_MLX32.5, U_MLX32.6, U_MLX42.3, U_MMC.3, U_N657.A15, U_N657.D9, U_N657.F2, U_N657.F4, U_N657.G1, U_N657.G2, U_N657.G3, U_N657.J12, U_N657.M4, U_N657.M10, U_N657.M12, U_N657.P3, U_N657.R1, U_N657.R2, U_N657.R15, U_NOR.2, U_PD.1, U_PD.6, U_PD.19, U_PD.22, U_PD.25, U_RF.2, U_RF.6, U_SCD.6, U_SCD.20, U_SCD.21, U_SGP.2, U_SGP.4, U_SGP.7, U_SHT.4, U_SW1V8_AIR.B1, U_SW1V8_OPTICAL.B1, U_SW1V8_RADAR.B1, U_SW_ACC.B1, U_SW_AIR.B1, U_SW_CONTACT.B1, U_SW_GNSS.B1, U_SW_OPTICAL.B1, U_SW_RADAR.B1, U_SW_WIFI.B1, U_SYS3V3.3, U_SYS3V3.5, U_TCS.3, U_TCS.5, U_TMAG.2, U_TOUCH.3, U_TOUCH.21, U_VL53.A6, U_VL53.A7, U_VL53.B4, U_VL53.C3, U_VL53.C6, U_VL53.C7, U_XLAT_TCS.1, X_A121.2, X_A121.4, X_HSE.2, X_HSE.4
GNSS_PPS: TP39.1, U_GNSS.A7, U_N657.P14
GNSS_RF: AE_GNSS.1, U_GNSS.B9
GNSS_RSVD_D2E2: U_GNSS.D2, U_GNSS.E2
GNSS_RX: TP55.1, U_GNSS.H1, U_N657.P11
GNSS_TX: TP54.1, U_GNSS.G1, U_N657.R11
GNSS_VBCKP: C143.1, D_BCKP.1, U_GNSS.J5
I2CA_SCL: J_CAM.14, R25.1, TP30.1, U_AS7058.A4, U_MAX.2, U_MLX32.4, U_MLX42.4, U_N657.N15, U_XLAT_TCS.5
I2CA_SCL_1V8: R56.1, U_TCS.2, U_XLAT_TCS.4
I2CA_SDA: J_CAM.13, R24.1, TP29.1, U_AS7058.A5, U_MAX.3, U_MLX32.1, U_MLX42.1, U_N657.N14, U_XLAT_TCS.6
I2CA_SDA_1V8: R55.1, U_TCS.8, U_XLAT_TCS.3
I2CB_SCL: R27.1, TP32.1, U_AS7331.13, U_AS7421.10, U_BME.4, U_BMV.6, U_COAFE.3, U_ENS.2, U_MMC.5, U_N657.A11, U_SCD.9, U_SGP.6, U_SHT.2, U_TMAG.1
I2CB_SDA: R26.1, TP31.1, U_AS7331.12, U_AS7421.9, U_BME.3, U_BMV.5, U_COAFE.4, U_ENS.1, U_MMC.4, U_N657.D10, U_SCD.10, U_SGP.3, U_SHT.1, U_TMAG.3
IMCU_N6_RX: TP38.1, U_BL54.3, U_N657.R10
IMCU_N6_TX: TP37.1, U_BL54.4, U_N657.P10
INTERLOCK_OK: TP62.1, U_BL54.35, U_ILK.2
INT_AS7058: U_AS7058.A6, U_N657.D11
INT_AS7421: R60.1, U_AS7421.1, U_N657.K2
INT_BMV: U_BMV.12, U_N657.N2
INT_BNO: R46.1, U_BNO.14, U_N657.B14
INT_ENS: R54.1, U_ENS.6, U_N657.P1
INT_MAX: R53.1, U_MAX.13, U_N657.A14
INT_TCS: R58.1, U_N657.M2, U_TCS.7
INT_TMAG: R61.1, U_N657.K3, U_TMAG.4
INT_VL53: R44.1, U_N657.F14, U_VL53.A1
IRQ_A121: U_A121.K8, U_N657.L1
LPN_VL53: R43.1, U_N657.K14, U_VL53.A2
LRA_N: J_LRA.2, U_HAP.9
LRA_P: J_LRA.1, U_HAP.7
N6_BOOT0: R29.1, TP21.1, U_N657.B2
N6_BOOT1: R30.1, TP22.1, U_N657.P13
N6_NRST: J_SWD_N6.3, R28.1, U_N657.C2
N6_OSC_IN: C68.1, U_N657.A7, X_HSE.1
N6_OSC_OUT: C69.1, U_N657.B7, X_HSE.3
N6_PWR_ON: R21.1, U_CORE.1, U_N657.D2
N6_SWCLK: J_SWD_N6.4, TP41.1, U_N657.R8
N6_SWDIO: J_SWD_N6.2, TP40.1, U_N657.R9
N6_SWO: J_SWD_N6.6, TP48.1
N6_V08CAP: C52.1, U_N657.E1
N6_VCORE_SEL: Q_VSEL.1, R16.1, U_N657.R13
unnamed: C4.1, U_PD.24
unnamed: R1.2, R2.1, U_PD.2
unnamed: R3.2, R4.1, U_PD.5
unnamed: Q_PROT.2, U_PROT.3
unnamed: Q_PROT.5, U_PROT.2
unnamed: R6.1, U_PROT.6
unnamed: R7.1, U_GAUGE.B1
unnamed: C10.1, U_CHG.17
unnamed: C11.1, R10.1, U_CHG.2
unnamed: C12.2, L1.1, U_CHG.16
unnamed: C12.1, U_CHG.1
unnamed: R8.1, U_CHG.14
unnamed: R9.1, U_CHG.7
unnamed: R12.1, U_AON.5
unnamed: L2.1, U_AON.7
unnamed: L3.1, U_CORE.6
unnamed: R13.2, R14.1, R15.1, U_CORE.2
unnamed: L4.1, U_SYS3V3.6
unnamed: R17.2, R18.1, U_SYS3V3.2
unnamed: L5.1, U_1V8.3
unnamed: R19.2, R20.1, U_1V8.5
unnamed: R22.1, U_N657.A6
unnamed: R23.1, U_N657.P7
unnamed: R47.1, U_BNO.4
unnamed: R50.1, U_ADS.9
unnamed: C152.2, U_RF.3
unnamed: C153.1, U_RF.4
unnamed: Q_UV.1, R70.2
unnamed: Q_WHITE.1, R72.2
unnamed: Q_FAN.1, R79.2
unnamed: C157.1, U_COAFE.10
unnamed: C157.2, U_COAFE.9
unnamed: C160.1, U_TOUCH.2
unnamed: C161.1, U_TOUCH.4
unnamed: C164.1, U_HAP.1
NOR_RST_N: R31.1, U_NOR.6
PACKP: C8.1, J_BATT.1, R5.1, U_GAUGE.C3
PDM_CLK: MK1.3, U_N657.D15
PDM_DATA: MK1.4, U_N657.E12
PD_FAULT: TP3.1, U_PD.9
PD_FLIP: TP4.1, U_PD.10
PD_VDDD: C1.1, C2.1, C3.1, R1.1, R3.1, U_PD.23
PIEZO_N: PZ1.2, R52.1, U_ADS.2
PIEZO_P: PZ1.1, R51.1, U_ADS.1
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

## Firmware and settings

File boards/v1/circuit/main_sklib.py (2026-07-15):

from collections import defaultdict
from skidl import Pin, Part, Alias, SchLib, SKIDL, TEMPLATE

from skidl.pin import pin_types

SKIDL_lib_version = '0.0.1'

main = SchLib(tool=SKIDL).add_parts(*[
        Part(**{ 'name':'USB_C_16P', 'dest':TEMPLATE, 'tool':SKIDL, 'aliases':Alias({'USB_C_16P'}), 'ref_prefix':'J', 'fplist':None, 'footprint':'Connector_USB:USB_C_Receptacle_GCT_USB4105-xx-A_16P_TopMnt_Horizontal', 'keywords':None, 'description':'USB-C 16P receptacle, GCT USB4105 class', 'datasheet':None, 'pins':[
            Pin(num='A1',name='GND_A1',func=pin_types.PWRIN),
            Pin(num='A4',name='VBUS_A4',func=pin_types.PWRIN),
            Pin(num='A5',name='CC1',func=pin_types.BIDIR),
            Pin(num='A6',name='DP1',func=pin_types.BIDIR),
            Pin(num='A7',name='DN1',func=pin_types.BIDIR),
            Pin(num='A8',name='SBU1',func=pin_types.PASSIVE),
            Pin(num='A9',name='VBUS_A9',func=pin_types.PWRIN),
            Pin(num='A12',name='GND_A12',func=pin_types.PWRIN),
            Pin(num='B1',name='GND_B1',func=pin_types.PWRIN),
            Pin(num='B4',name='VBUS_B4',func=pin_types.PWRIN),
            Pin(num='B5',name='CC2',func=pin_types.BIDIR),
            Pin(num='B6',name='DP2',func=pin_types.BIDIR),
            Pin(num='B7',name='DN2',func=pin_types.BIDIR),
            Pin(num='B8',name='SBU2',func=pin_types.PASSIVE),
            Pin(num='B9',name='VBUS_B9',func=pin_types.PWRIN),
            Pin(num='B12',name='GND_B12',func=pin_types.PWRIN),
            Pin(num='S1',name='SHIELD',func=pin_types.PASSIVE)] }),
        Part(**{ 'name':'TESTPOINT', 'dest':TEMPLATE, 'tool':SKIDL, 'aliases':Alias({'TESTPOINT'}), 'ref_prefix':'TP', 'fplist':None, 'footprint':'generated:TESTPOINT_PAD_0.8MM', 'keywords':None, 'description':'Test pad', 'datasheet':None, 'pins':[
            Pin(num='1',name='TP',func=pin_types.PASSIVE)] }),
        Part(**{ 'name':'CYPD3177', 'dest':TEMPLATE, 'tool':SKIDL, 'aliases':Alias({'CYPD3177'}), 'ref_prefix':'U', 'fplist':None, 'footprint':'Package_DFN_QFN:HVQFN-24-1EP_4x4mm_P0.5mm_EP2.6x2.6mm', 'keywords':None, 'description':'CYPD3177 autonomous USB-C PD sink; VDDD dividers request 5-9V/3A; full QFN-24 map (VERIFIED-DS Table 1 p5-6)', 'datasheet':None, 'pins':[
            Pin(num='18',name='VBUS',func=pin_types.PWRIN),
            Pin(num='19',name='GND',func=pin_types.PWRIN),
            Pin(num='22',name='VSS',func=pin_types.PWRIN),
            Pin(num='25',name='EP',func=pin_types.PWRIN),
            Pin(num='15',name='CC1',func=pin_types.BIDIR),
            Pin(num='14',name='CC2',func=pin_types.BIDIR),
            Pin(num='23',name='VDDD',func=pin_types.PWROUT),
            Pin(num='24',name='VCCD',func=pin_types.PWROUT),
            Pin(num='1',name='VBUS_MIN',func=pin_types.INPUT),
            Pin(num='2',name='VBUS_MAX',func=pin_types.INPUT),
            Pin(num='5',name='ISNK_COARSE',func=pin_types.INPUT),
            Pin(num='6',name='ISNK_FINE',func=pin_types.INPUT),
            Pin(num='9',name='FAULT',func=pin_types.OUTPUT),
            Pin(num='10',name='FLIP',func=pin_types.OUTPUT),
            Pin(num='11',name='VDC_OUT',func=pin_types.INPUT),
            Pin(num='3',name='VBUS_FET_EN',func=pin_types.NOCONNECT),
            Pin(num='4',name='SAFE_PWR_EN',func=pin_types.NOCONNECT),
            Pin(num='7',name='HPI_INT',func=pin_types.NOCONNECT),
            Pin(num='8',name='GPIO_1',func=pin_types.NOCONNECT),
            Pin(num='12',name='HPI_SDA',func=pin_types.NOCONNECT),
            Pin(num='13',name='HPI_SCL',func=pin_types.NOCONNECT),
            Pin(num='16',name='DM',func=pin_types.NOCONNECT),
            Pin(num='17',name='DP',func=pin_types.NOCONNECT),
            Pin(num='20',name='DNU1',func=pin_types.NOCONNECT),
            Pin(num='21',name='DNU2',func=pin_types.NOCONNECT)] }),
        Part(**{ 'name':'C', 'dest':TEMPLATE, 'tool':SKIDL, 'aliases':Alias({'C'}), 'ref_prefix':'C', 'fplist':[''], 'footprint':'Capacitor_SMD:C_0402_1005Metric', 'keywords':'cap capacitor', 'description':'', 'datasheet':'~', 'pins':[
            Pin(num='1',name='~',func=pin_types.PASSIVE,unit=1),
            Pin(num='2',name='~',func=pin_types.PASSIVE,unit=1)], 'unit_defs':[] }),
        Part(**{ 'name':'R', 'dest':TEMPLATE, 'tool':SKIDL, 'aliases':Alias({'R'}), 'ref_prefix':'R', 'fplist':[''], 'footprint':'Resistor_SMD:R_0402_1005Metric', 'keywords':'R res resistor', 'description':'', 'datasheet':'~', 'pins':[
            Pin(num='1',name='~',func=pin_types.PASSIVE,unit=1),
            Pin(num='2',name='~',func=pin_types.PASSIVE,unit=1)], 'unit_defs':[] }),
        Part(**{ 'name':'CONN_BATT_3P', 'dest':TEMPLATE, 'tool':SKIDL, 'aliases':Alias({'CONN_BATT_3P'}), 'ref_prefix':'J', 'fplist':None, 'footprint':'Connector_JST:JST_ACH_BM03B-ACHSS-GAN-ETF_1x03-1MP_P1.20mm_Vertical', 'keywords':None, 'description':'1S LiPo battery connector (JST-ACH class) + pack NTC', 'datasheet':None, 'pins':[
            Pin(num='1',name='BATT+',func=pin_types.PASSIVE),
            Pin(num='2',name='NTC',func=pin_types.PASSIVE),
            Pin(num='3',name='BATT-',func=pin_types.PASSIVE),
            Pin(num='MP',name='MP',func=pin_types.PASSIVE)] }),
        Part(**{ 'name':'BQ29700', 'dest':TEMPLATE, 'tool':SKIDL, 'aliases':Alias({'BQ29700'}), 'ref_prefix':'U', 'fplist':None, 'footprint':'Package_SON:WSON-6_1.5x1.5mm_P0.5mm', 'keywords':None, 'description':'TI BQ29700 1S Li+ protector (with dual NMOS) (VERIFIED-DS p3)', 'datasheet':None, 'pins':[
            Pin(num='5',name='VDD',func=pin_types.PWRIN),
            Pin(num='4',name='VSS',func=pin_types.PWRIN),
            Pin(num='6',name='VM',func=pin_types.INPUT),
            Pin(num='2',name='COUT',func=pin_types.OUTPUT),
            Pin(num='3',name='DOUT',func=pin_types.OUTPUT),
            Pin(num='1',name='NC',func=pin_types.NOCONNECT)] }),
        Part(**{ 'name':'DUAL_NFET_PROT', 'dest':TEMPLATE, 'tool':SKIDL, 'aliases':Alias({'DUAL_NFET_PROT'}), 'ref_prefix':'Q', 'fplist':None, 'footprint':'Package_SON:WSON-6-1EP_2x2mm_P0.65mm_EP1x1.6mm', 'keywords':None, 'description':'Dual NMOS, battery protection series pair (low-side) (pins PROVISIONAL-E0)', 'datasheet':None, 'pins':[
            Pin(num='1',name='S1',func=pin_types.PASSIVE),
            Pin(num='2',name='G1',func=pin_types.INPUT),
            Pin(num='3',name='D1',func=pin_types.PASSIVE),
            Pin(num='4',name='D2',func=pin_types.PASSIVE),
            Pin(num='5',name='G2',func=pin_types.INPUT),
            Pin(num='6',name='S2',func=pin_types.PASSIVE),
            Pin(num='7',name='PEND_EP',func=pin_types.NOCONNECT)] }),
        Part(**{ 'name':'BQ27427', 'dest':TEMPLATE, 'tool':SKIDL, 'aliases':Alias({'BQ27427'}), 'ref_prefix':'U', 'fplist':None, 'footprint':'Package_BGA:Texas_DSBGA-9_1.62mmx1.58mm_Layout3x3_P0.5mm', 'keywords':None, 'description':'TI BQ27427 gauge, SENTINEL_I2C 0x55; HIGH-side 7mΩ sense (VERIFIED-DS p3)', 'datasheet':None, 'pins':[
            Pin(num='B3',name='VDD',func=pin_types.PWROUT),
            Pin(num='B1',name='BIN',func=pin_types.INPUT),
            Pin(num='C3',name='BAT',func=pin_types.PWRIN),
            Pin(num='C2',name='SRX',func=pin_types.PASSIVE),
            Pin(num='A2',name='SDA',func=pin_types.BIDIR),
            Pin(num='A3',name='SCL',func=pin_types.BIDIR),
            Pin(num='A1',name='GPOUT',func=pin_types.OPENCOLL),
            Pin(num='B2',name='VSS',func=pin_types.PWRIN),
            Pin(num='C1',name='VSS2',func=pin_types.PWRIN)] }),
        Part(**{ 'name':'BQ25620', 'dest':TEMPLATE, 'tool':SKIDL, 'aliases':Alias({'BQ25620'}), 'ref_prefix':'U', 'fplist':None, 'footprint':'generated:BQ25620_WQFN18_RYK', 'keywords':None, 'description':'TI BQ25620 3.5A charger, ~1C fast charge, SENTINEL_I2C 0x6B (VERIFIED-DS)', 'datasheet':None, 'pins':[
            Pin(num='18',name='VBUS',func=pin_types.PWRIN),
            Pin(num='17',name='PMID',func=pin_types.PASSIVE),
            Pin(num='2',name='REGN',func=pin_types.PWROUT),
            Pin(num='16',name='SW',func=pin_types.OUTPUT),
            Pin(num='1',name='BTST',func=pin_types.PASSIVE),
            Pin(num='9',name='SYS',func=pin_types.PWROUT),
            Pin(num='8',name='BAT',func=pin_types.PWRIN),
            Pin(num='12',name='SDA',func=pin_types.BIDIR),
            Pin(num='13',name='SCL',func=pin_types.BIDIR),
            Pin(num='11',name='INT_N',func=pin_types.OPENCOLL),
            Pin(num='14',name='CE_N',func=pin_types.INPUT),
            Pin(num='6',name='TS',func=pin_types.INPUT),
            Pin(num='7',name='QON_N',func=pin_types.INPUT),
            Pin(num='15',name='GND',func=pin_types.PWRIN),
            Pin(num='3',name='PG_N',func=pin_types.OPENCOLL),
            Pin(num='4',name='DM',func=pin_types.BIDIR),
            Pin(num='5',name='DP',func=pin_types.BIDIR),
            Pin(num='10',name='STAT',func=pin_types.OPENCOLL)] }),
        Part(**{ 'name':'L', 'dest':TEMPLATE, 'tool':SKIDL, 'aliases':Alias({'L'}), 'ref_prefix':'L', 'fplist':[''], 'footprint':'Inductor_SMD:L_0805_2012Metric', 'keywords':'inductor choke coil reactor magnetic', 'description':'', 'datasheet':'~', 'pins':[
            Pin(num='1',name='1',func=pin_types.PASSIVE,unit=1),
            Pin(num='2',name='2',func=pin_types.PASSIVE,unit=1)], 'unit_defs':[] }),
        Part(**{ 'name':'TPS62840', 'dest':TEMPLATE, 'tool':SKIDL, 'aliases':Alias({'TPS62840'}), 'ref_prefix':'U', 'fplist':None, 'footprint':'Package_TO_SOT_SMD:SOT-583-8', 'keywords':None, 'description':'TI TPS62840DLC, 60nA IQ, 3V3_AON (VSET=267k, VERIFIED-DS p22)', 'datasheet':None, 'pins':[
            Pin(num='2',name='VIN',func=pin_types.PWRIN),
            Pin(num='1',name='GND',func=pin_types.PWRIN),
            Pin(num='4',name='EN',func=pin_types.INPUT),
            Pin(num='7',name='SW',func=pin_types.OUTPUT),
            Pin(num='8',name='VOS',func=pin_types.INPUT),
            Pin(num='3',name='MODE',func=pin_types.INPUT),
            Pin(num='5',name='VSET',func=pin_types.INPUT),
            Pin(num='6',name='STOP',func=pin_types.INPUT)] }),
        Part(**{ 'name':'TPS62823', 'dest':TEMPLATE, 'tool':SKIDL, 'aliases':Alias({'TPS62823'}), 'ref_prefix':'U', 'fplist':None, 'footprint':'Package_TO_SOT_SMD:SOT-583-8', 'keywords':None, 'description':'TI TPS62823 3A buck (VERIFIED-DS p3)', 'datasheet':None, 'pins':[
            Pin(num='7',name='VIN',func=pin_types.PWRIN),
            Pin(num='3',name='AGND',func=pin_types.PWRIN),
            Pin(num='5',name='PGND',func=pin_types.PWRIN),
            Pin(num='1',name='EN',func=pin_types.INPUT),
            Pin(num='6',name='SW',func=pin_types.OUTPUT),
            Pin(num='2',name='FB',func=pin_types.INPUT),
            Pin(num='8',name='PG',func=pin_types.OPENCOLL),
            Pin(num='4',name='NC',func=pin_types.NOCONNECT)] }),
        Part(**{ 'name':'NFET_SOT23', 'dest':TEMPLATE, 'tool':SKIDL, 'aliases':Alias({'NFET_SOT23'}), 'ref_prefix':'Q', 'fplist':None, 'footprint':'Package_TO_SOT_SMD:SOT-23', 'keywords':None, 'description':'N-ch FET, SOT-23 (LED / fan low-side drive)', 'datasheet':None, 'pins':[
            Pin(num='1',name='G',func=pin_types.INPUT),
            Pin(num='2',name='S',func=pin_types.PASSIVE),
            Pin(num='3',name='D',func=pin_types.PASSIVE)] }),
        Part(**{ 'name':'TLV62568', 'dest':TEMPLATE, 'tool':SKIDL, 'aliases':Alias({'TLV62568'}), 'ref_prefix':'U', 'fplist':None, 'footprint':'Package_TO_SOT_SMD:SOT-23-5', 'keywords':None, 'description':'TI TLV62568 1A buck -> 1V8 (VERIFIED-DS p3)', 'datasheet':None, 'pins':[
            Pin(num='1',name='EN',func=pin_types.INPUT),
            Pin(num='2',name='GND',func=pin_types.PWRIN),
            Pin(num='3',name='SW',func=pin_types.OUTPUT),
            Pin(num='4',name='VIN',func=pin_types.PWRIN),
            Pin(num='5',name='FB',func=pin_types.INPUT)] }),
        Part(**{ 'name':'TPS22916', 'dest':TEMPLATE, 'tool':SKIDL, 'aliases':Alias({'TPS22916'}), 'ref_prefix':'U', 'fplist':None, 'footprint':'generated:TPS22916_CSP4', 'keywords':None, 'description':'TI TPS22916 load switch (per-domain power gating) (VERIFIED-DS p3)', 'datasheet':None, 'pins':[
            Pin(num='A2',name='VIN',func=pin_types.PWRIN),
            Pin(num='B1',name='GND',func=pin_types.PWRIN),
            Pin(num='B2',name='ON',func=pin_types.INPUT),
            Pin(num='A1',name='VOUT',func=pin_types.PWROUT)] }),
        Part(**{ 'name':'STM32N657', 'dest':TEMPLATE, 'tool':SKIDL, 'aliases':Alias({'STM32N657'}), 'ref_prefix':'U', 'fplist':None, 'footprint':'generated:ST_VFBGA142', 'keywords':None, 'description':'STM32N657X0 app MCU + NPU, VFBGA142 — real ball map (VERIFIED-DS DS14791 Rev 9 Table 18)', 'datasheet':None, 'pins':[
            Pin(num='M5',name='VDDCORE1',func=pin_types.PWRIN),
            Pin(num='M6',name='VDDCORE2',func=pin_types.PWRIN),
            Pin(num='M7',name='VDDCORE3',func=pin_types.PWRIN),
            Pin(num='M8',name='VDDCORE4',func=pin_types.PWRIN),
            Pin(num='M9',name='VDDCORE5',func=pin_types.PWRIN),
            Pin(num='F12',name='VDD1',func=pin_types.PWRIN),
            Pin(num='G12',name='VDD2',func=pin_types.PWRIN),
            Pin(num='H12',name='VDD3',func=pin_types.PWRIN),
            Pin(num='K12',name='VDDIO3_1',func=pin_types.PWRIN),
            Pin(num='L12',name='VDDIO3_2',func=pin_types.PWRIN),
            Pin(num='D8',name='VDDIO4',func=pin_types.PWRIN),
            Pin(num='P8',name='VDDCSI',func=pin_types.PWRIN),
            Pin(num='R7',name='VDDA18CSI',func=pin_types.PWRIN),
            Pin(num='K4',name='VDDA18PLL',func=pin_types.PWRIN),
            Pin(num='D4',name='VDDA18USB',func=pin_types.PWRIN),
            Pin(num='B6',name='VDD33USB',func=pin_types.PWRIN),
            Pin(num='R3',name='VDDA18ADC',func=pin_types.PWRIN),
            Pin(num='E4',name='VDDA18AON',func=pin_types.PWRIN),
            Pin(num='F1',name='VDDA18PMU',func=pin_types.PWRIN),
            Pin(num='P2',name='VREF_P',func=pin_types.PWRIN),
            Pin(num='R2',name='VREF_N',func=pin_types.PWRIN),
            Pin(num='D1',name='VBAT',func=pin_types.PWRIN),
            Pin(num='J1',name='VDDSMPS1',func=pin_types.PWRIN),
            Pin(num='J2',name='VDDSMPS2',func=pin_types.PWRIN),
            Pin(num='J3',name='VDDSMPS3',func=pin_types.PWRIN),
            Pin(num='G1',name='VSSSMPS1',func=pin_types.PWRIN),
            Pin(num='G2',name='VSSSMPS2',func=pin_types.PWRIN),
            Pin(num='G3',name='VSSSMPS3',func=pin_types.PWRIN),
            Pin(num='H1',name='VLXSMPS1',func=pin_types.NOCONNECT),
            Pin(num='H2',name='VLXSMPS2',func=pin_types.NOCONNECT),
            Pin(num='H3',name='VLXSMPS3',func=pin_types.NOCONNECT),
            Pin(num='F3',name='VFBSMPS',func=pin_types.NOCONNECT),
            Pin(num='E1',name='V08CAP',func=pin_types.PWROUT),
            Pin(num='A15',name='VSS1',func=pin_types.PWRIN),
            Pin(num='D9',name='VSS2',func=pin_types.PWRIN),
            Pin(num='J12',name='VSS3',func=pin_types.PWRIN),
            Pin(num='M4',name='VSS4',func=pin_types.PWRIN),
            Pin(num='M10',name='VSS5',func=pin_types.PWRIN),
            Pin(num='M12',name='VSS6',func=pin_types.PWRIN),
            Pin(num='R1',name='VSS7',func=pin_types.PWRIN),
            Pin(num='R15',name='VSS8',func=pin_types.PWRIN),
            Pin(num='P3',name='VSSA',func=pin_types.PWRIN),
            Pin(num='F4',name='VSSAON',func=pin_types.PWRIN),
            Pin(num='F2',name='VSSAPMU',func=pin_types.PWRIN),
            Pin(num='A1',name='PDR_ON',func=pin_types.INPUT),
            Pin(num='D2',name='PWR_ON',func=pin_types.OUTPUT),
            Pin(num='C2',name='NRST',func=pin_types.INPUT),
            Pin(num='B2',name='BOOT0',func=pin_types.INPUT),
            Pin(num='P13',name='BOOT1',func=pin_types.INPUT),
            Pin(num='R12',name='SPI1_SCK',func=pin_types.OUTPUT),
            Pin(num='L14',name='SPI1_MISO',func=pin_types.INPUT),
            Pin(num='M15',name='SPI1_MOSI',func=pin_types.OUTPUT),
            Pin(num='C13',name='CS_VL53_N',func=pin_types.OUTPUT),
            Pin(num='N13',name='CS_BNO_N',func=pin_types.OUTPUT),
            Pin(num='B13',name='CS_ADS_N',func=pin_types.OUTPUT),
            Pin(num='B11',name='CS_A121_N',func=pin_types.OUTPUT),
            Pin(num='N15',name='I2CA_SCL',func=pin_types.BIDIR),
            Pin(num='N14',name='I2CA_SDA',func=pin_types.BIDIR),
            Pin(num='A11',name='I2CB_SCL',func=pin_types.BIDIR),
            Pin(num='D10',name='I2CB_SDA',func=pin_types.BIDIR),
            Pin(num='A10',name='SDIO_CLK',func=pin_types.OUTPUT),
            Pin(num='B10',name='SDIO_CMD',func=pin_types.BIDIR),
            Pin(num='A8',name='SDIO_D0',func=pin_types.BIDIR),
            Pin(num='B8',name='SDIO_D1',func=pin_types.BIDIR),
            Pin(num='A9',name='SDIO_D2',func=pin_types.BIDIR),
            Pin(num='B9',name='SDIO_D3',func=pin_types.BIDIR),
            Pin(num='P11',name='UART1_TX',func=pin_types.OUTPUT),
            Pin(num='R11',name='UART1_RX',func=pin_types.INPUT),
            Pin(num='P14',name='PPS_IN',func=pin_types.INPUT),
            Pin(num='P10',name='UART2_TX',func=pin_types.OUTPUT),
            Pin(num='R10',name='UART2_RX',func=pin_types.INPUT),
            Pin(num='B5',name='USB_DP',func=pin_types.BIDIR),
            Pin(num='A5',name='USB_DM',func=pin_types.BIDIR),
            Pin(num='A6',name='OTG1_TXRTUNE',func=pin_types.PASSIVE),
            Pin(num='B4',name='OTG1_ID',func=pin_types.NOCONNECT),
            Pin(num='D6',name='UCPD1_CC1',func=pin_types.NOCONNECT),
            Pin(num='D7',name='UCPD1_CC2',func=pin_types.NOCONNECT),
            Pin(num='A3',name='OTG2_HSDM',func=pin_types.NOCONNECT),
            Pin(num='B3',name='OTG2_HSDP',func=pin_types.NOCONNECT),
            Pin(num='A2',name='OTG2_ID',func=pin_types.NOCONNECT),
            Pin(num='D5',name='OTG2_TXRTUNE',func=pin_types.NOCONNECT),
            Pin(num='C3',name='RSVD_C3',func=pin_types.NOCONNECT),
            Pin(num='A4',name='RSVD_A4',func=pin_types.NOCONNECT),
            Pin(num='R5',name='CSI_CKP',func=pin_types.BIDIR),
            Pin(num='P5',name='CSI_CKN',func=pin_types.BIDIR),
            Pin(num='R6',name='CSI_D0P',func=pin_types.BIDIR),
            Pin(num='P6',name='CSI_D0N',func=pin_types.BIDIR),
            Pin(num='R4',name='CSI_D1P',func=pin_types.BIDIR),
            Pin(num='P4',name='CSI_D1N',func=pin_types.BIDIR),
            Pin(num='P7',name='CSI_REXT',func=pin_types.PASSIVE),
            Pin(num='A13',name='CAM_XCLK',func=pin_types.OUTPUT),
            Pin(num='C15',name='CAM_RSTN',func=pin_types.OUTPUT),
            Pin(num='D15',name='PDM_CLK',func=pin_types.OUTPUT),
            Pin(num='E12',name='PDM_DATA',func=pin_types.INPUT),
            Pin(num='L4',name='ADC_IN0',func=pin_types.INPUT),
            Pin(num='M11',name='MCO_OUT',func=pin_types.OUTPUT),
            Pin(num='A7',name='OSC_IN',func=pin_types.INPUT),
            Pin(num='B7',name='OSC_OUT',func=pin_types.OUTPUT),
            Pin(num='C1',name='PC14_OSC32_IN',func=pin_types.NOCONNECT),
            Pin(num='B1',name='PC15_OSC32_OUT',func=pin_types.NOCONNECT),
            Pin(num='R9',name='SWDIO',func=pin_types.BIDIR),
            Pin(num='R8',name='SWCLK',func=pin_types.INPUT),
            Pin(num='H15',name='XSPI_D0',func=pin_types.BIDIR),
            Pin(num='K15',name='XSPI_D1',func=pin_types.BIDIR),
            Pin(num='E14',name='XSPI_D2',func=pin_types.BIDIR),
            Pin(num='F15',name='XSPI_D3',func=pin_types.BIDIR),
            Pin(num='E15',name='XSPI_D4',func=pin_types.BIDIR),
            Pin(num='G14',name='XSPI_D5',func=pin_types.BIDIR),
            Pin(num='H14',name='XSPI_D6',func=pin_types.BIDIR),
            Pin(num='J14',name='XSPI_D7',func=pin_types.BIDIR),
            Pin(num='G15',name='XSPI_CLK',func=pin_types.OUTPUT),
            Pin(num='D14',name='XSPI_CS_N',func=pin_types.OUTPUT),
            Pin(num='J15',name='XSPI_DQS',func=pin_types.BIDIR),
            Pin(num='F14',name='INT_VL53',func=pin_types.INPUT),
            Pin(num='B14',name='INT_BNO',func=pin_types.INPUT),
            Pin(num='B15',name='DRDY_ADS',func=pin_types.INPUT),
            Pin(num='A14',name='INT_MAX',func=pin_types.INPUT),
            Pin(num='D11',name='INT_AS7058',func=pin_types.INPUT),
            Pin(num='L1',name='IRQ_A121',func=pin_types.INPUT),
            Pin(num='K1',name='DRDY_MMC',func=pin_types.INPUT),
            Pin(num='K3',name='INT_TMAG',func=pin_types.INPUT),
            Pin(num='M2',name='INT_TCS',func=pin_types.INPUT),
            Pin(num='N1',name='RDY_AS7331',func=pin_types.INPUT),
            Pin(num='K2',name='INT_AS7421',func=pin_types.INPUT),
            Pin(num='N2',name='INT_BMV',func=pin_types.INPUT),
            Pin(num='P1',name='INT_ENS',func=pin_types.INPUT),
            Pin(num='E2',name='WAKE_IN',func=pin_types.INPUT),
            Pin(num='N3',name='WAKE_OUT',func=pin_types.OUTPUT),
            Pin(num='L2',name='EN_UV_REQ',func=pin_types.OUTPUT),
            Pin(num='M1',name='EN_WHITE',func=pin_types.OUTPUT),
            Pin(num='M14',name='RSTN_BNO',func=pin_types.OUTPUT),
            Pin(num='K14',name='LPN_VL53',func=pin_types.OUTPUT),
            Pin(num='R13',name='VCORE_SEL',func=pin_types.OUTPUT),
            Pin(num='R14',name='PA0_NC',func=pin_types.NOCONNECT),
            Pin(num='P12',name='PA2_NC',func=pin_types.NOCONNECT),
            Pin(num='L15',name='PA15_NC',func=pin_types.NOCONNECT),
            Pin(num='C14',name='PB0_NC',func=pin_types.NOCONNECT),
            Pin(num='B12',name='PD1_NC',func=pin_types.NOCONNECT),
            Pin(num='A12',name='PE7_NC',func=pin_types.NOCONNECT),
            Pin(num='P9',name='PG14_NC',func=pin_types.NOCONNECT),
            Pin(num='D12',name='PE8_NC',func=pin_types.NOCONNECT),
            Pin(num='P15',name='PG10_NC',func=pin_types.NOCONNECT)] }),
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

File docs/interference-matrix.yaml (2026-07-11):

# Interference matrix v1 (seeded from physics/datasheets; MEASURED pairwise at H4).
# Consumed by the AI scheduler: avoid masking interactions; state flags ride every record.
# rule verbs: mutex | tdm | stagger | gate(<state>) | flag(<name>) | zoning | cal | material_exclusion | light_tight_cavity | dedicated_aperture | spread_spectrum | shield | keepout
# enforcement_tier per rule: 'firmware' (reflex, sub-100ms) | 'edge' (active-sensing policy) | 'factory'/'mech'/'material' (design-time)
# Ships downstream via the ingest package, referenced by the device profile (single-sourced; firmware/edge LOAD it, never hardcode).
pairs:
  # 1 optical crosstalk
  - {src: UV_LED_365,      victims: [TCS3448, AS7331, MAX30102, AS7058, camera], effect: optical_saturation, rule: tdm}
  - {src: WHITE_NIR_LED,   victims: [TCS3448, AS7331, VL53L8CH, camera],         effect: optical_bias,       rule: tdm}
  - {src: VL53L8CH_940nm,  victims: [MAX30102, AS7058, TCS3448, camera],         effect: ir_crosstalk,       rule: tdm}
  - {src: PPG_LEDS,        victims: [TCS3448, VL53L8CH, camera],                 effect: optical_crosstalk,  rule: tdm}
  # 2 thermal
  - {src: BMV080_selfheat, victims: [BME688, SGP41, MLX90642],                   effect: thermal_drift,      rule: [zoning, flag(motors_active)]}
  - {src: N657_WIFI_CHG_heat, victims: [BME688, SGP41, MLX90642],               effect: thermal_drift,      rule: [zoning, cal]}
  # 3 chemical
  - {src: SILICONE_OUTGAS, victims: [BME688, SGP41], effect: siloxane_poisoning, rule: material_exclusion, note: no silicone/siloxane near air path; bake-out}
  # 4 magnetic
  - {src: CURRENT_LOOPS_LED_CHG_FAN, victims: [MMC5983MA, TMAG5273], effect: dc_field, rule: [zoning, cal]}
  - {src: MMC_SETRESET,    victims: [TMAG5273], effect: pulse_field, rule: stagger}
  - {src: FERROUS_TARGET,  victims: [MMC5983MA, TMAG5273], effect: soft_iron, rule: cal}
  - {src: DOCK_MAGNET,     victims: [MMC5983MA, TMAG5273], effect: dc_field, rule: gate(docked)}
  - {src: HAPTIC_LRA_MAGNET, victims: [MMC5983MA], effect: dc_field, rule: [zoning, mutex]}
  # 5 RF desense
  - {src: WIFI_TX,         victims: [MIA_M10Q, ADS131M04, A121], effect: rf_desense, rule: [gate(gnss_rawx), flag(wifi_active)]}
  - {src: BUCK_USB_MIPI_CLOCKS, victims: [MIA_M10Q], effect: rf_desense, rule: [spread_spectrum, shield, keepout]}
  # 6 vibration
  - {src: FAN_BLOWER,      victims: [BNO086, ADS131M04_piezo, BG51], effect: vibration, rule: flag(motors_active)}
  - {src: HAPTIC_LRA,      victims: [BNO086, ADS131M04_piezo],       effect: vibration, rule: mutex}
  # 7 switching noise
  - {src: BQ25620_CHARGING, victims: [AS7058_ECG, ADS131M04, MMC5983MA, IQS7222A], effect: switching_noise, rule: [gate(charging), flag(charging)]}
  # 8 light into radiation
  - {src: AMBIENT_EMITTER_LIGHT, victims: [BG51], effect: photocurrent, rule: light_tight_cavity}
  # 9 PM vs mesh
  - {src: LINT_MESH,       victims: [BMV080], effect: pm_attenuation, rule: [dedicated_aperture, cal], note: pore passes PM2.5 blocks lint}
activation_classes:
  always_ambient: [BME688, SGP41, BNO086, MMC5983MA, TMAG5273, BG51, sentinel_touch]
  triggered:      [MAX30102, AS7058, IQS7222A_read, A121_presence, BMV080_duty]
  intent_driven:  [MLX90642_highfps, VL53L8CH, TCS3448, AS7331, camera, GNSS_cont, WIFI_bulk]
  gated_off_default: [UV_LED_365, WHITE_NIR_LED, FAN_BLOWER, HAPTIC_LRA]
state_flags: [motors_active, haptic_active, wifi_active, charging, docked, leds_active, uv_active]

# --- downstream routing (interrogator consumes; hardware is the single source) ---
enforcement_routing:
  firmware_reflex:   # real-time, deterministic — MUST be firmware
    verbs: [tdm, mutex, stagger, gate]
    examples: [UV_LED_365->TCS3448 tdm, HAPTIC_LRA->BNO086 mutex, MMC_SETRESET->TMAG5273 stagger, WIFI_TX->MIA_M10Q gate(gnss_rawx)]
  edge_policy:       # active-sensing agent — scheduling + confidence weighting
    verbs: [flag, zoning-aware scheduling, cal-aware weighting]
  design_time:       # not runtime — HW/materials/factory own these
    verbs: [material_exclusion, light_tight_cavity, dedicated_aperture, spread_spectrum, shield, keepout, zoning, cal]
consumers:
  - {who: interrogator_firmware, loads: [firmware_reflex rules, state_flags emit], via: device_profile_ref}
  - {who: interrogator_edge_policy, loads: [edge_policy rules, matrix for active-sensing], via: device_profile_ref}
# state-flag SCHEMA DELTA owned by interrogator (ADR-0001 record contract):
#   existing (prototype): motors_active, wifi_active, leds_active, valve_active
#   NEW for v1 (we specify, they add): charging, docked, haptic_active, uv_active

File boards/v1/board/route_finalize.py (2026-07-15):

#!/usr/bin/env python3
"""H3.3d — final DRC + audits + artifacts.

* refills zones, runs the DRC engine -> drc_final.{rpt,json}
* honest unconnected census (geometric connectivity, no report cap),
  split into: do-not-route (AS7058/MMC5983MA), testpoint-only edges,
  signal edges, power edges
* CO_AFE_OUT guard audit (foreign copper within 0.30mm on its layers)
* radiation-confinement audit (RAD_* copper outside the shield-can bbox)
* XSPI / diff-pair length tables
* copper utilization per layer, track/via counts
* per-layer SVG exports via kicad-cli

Run: python3 boards/v1/board/route_finalize.py
"""
import json
import subprocess
import time

import pcbnew
from shapely.geometry import LineString, Point

import route_lib as RL
from route_router import Router

HERE = RL.HERE


def track_len(board, netcode):
    tot, nvia = 0.0, 0
    for t in board.GetTracks():
        if t.GetNetCode() != netcode:
            continue
        if t.GetClass() == "PCB_VIA":
            nvia += 1
        else:
            tot += RL.tomm(int(t.GetLength()))
    return round(tot, 2), nvia


def main():
    t0 = time.time()
    board = RL.load()
    r = Router(board)
    r.exclude_refs = ()
    out = {}

    # ---- unconnected census -------------------------------------------------
    dnr_refs = ("U_AS7058", "U_MMC")
    census = {"do_not_route": 0, "testpoint": 0, "signal": 0, "power": 0}
    per_net = {}
    iref = getattr(r, "item_ref", {})
    for net in r.items:
        cls = r.clusters(net)
        if len(cls) <= 1:
            continue
        name = r.netname.get(net, "?")
        edges = len(cls) - 1
        # classify each surplus cluster
        for c in cls[1:]:
            refs = {iref.get(iid, "") for iid, _g, _l in c}
            refs.discard("")
            if refs and refs <= set(dnr_refs):
                census["do_not_route"] += 1
            elif refs and all(x.startswith("TP") for x in refs):
                census["testpoint"] += 1
            elif name == "GND" or name.startswith(("3V3", "1V8", "V")):
                census["power"] += 1
            else:
                census["signal"] += 1
        per_net[name] = edges
    out["unconnected_census"] = census
    out["unconnected_total"] = sum(census.values())
    out["unconnected_by_net"] = dict(sorted(per_net.items(),
                                            key=lambda kv: -kv[1]))

    # ---- length tables --------------------------------------------------------
    xspi = ["XSPI_CS_N", "XSPI_DQS", "XSPI_CLK"] + [f"XSPI_D{i}" for i in range(8)]
    out["xspi_mm"] = {}
    for name in xspi:
        n = board.FindNet(name)
        if n:
            out["xspi_mm"][name] = track_len(board, n.GetNetCode())
    pairs = {}
    for p, q in (("USB_DP", "USB_DM"), ("CSI_CKP", "CSI_CKN"),
                 ("CSI_D0P", "CSI_D0N"), ("CSI_D1P", "CSI_D1N")):
        lp = track_len(board, board.FindNet(p).GetNetCode())
        lq = track_len(board, board.FindNet(q).GetNetCode())
        pairs[f"{p}/{q}"] = {"p": lp, "n": lq,
                             "delta_mm": round(lp[0] - lq[0], 3)}
    out["pairs"] = pairs

    # ---- CO_AFE_OUT guard audit ----------------------------------------------
    co = board.FindNet("CO_AFE_OUT").GetNetCode()
    viol = []
    for t in board.GetTracks():
        if t.GetNetCode() != co or t.GetClass() == "PCB_VIA":
            continue
        seg = LineString([(RL.tomm(t.GetStart().x), RL.tomm(t.GetStart().y)),
                          (RL.tomm(t.GetEnd().x), RL.tomm(t.GetEnd().y))])
        probe = seg.buffer(0.30 + RL.tomm(int(t.GetWidth())) / 2)
        hits = r.g and None
        near = set()
        for t2 in board.GetTracks():
            if t2.GetNetCode() in (co, 0) or t2.GetClass() == "PCB_VIA":
                continue
            if t2.GetLayer() != t.GetLayer():
                continue
            seg2 = LineString([(RL.tomm(t2.GetStart().x), RL.tomm(t2.GetStart().y)),
                               (RL.tomm(t2.GetEnd().x), RL.tomm(t2.GetEnd().y))])
            if probe.intersects(seg2):
                near.add(t2.GetNetname())
        viol.extend(sorted(near))
    out["co_afe_guard_intrusions"] = sorted(set(viol))

    # ---- radiation confinement audit -------------------------------------------
    sh = next(fp for fp in board.GetFootprints() if fp.GetReference() == "SH_RAD")
    c = sh.GetPosition()
    cx, cy = RL.tomm(c.x), RL.tomm(c.y)
    outside = []
    for name in ("RAD_IN", "RAD_VREF", "RAD_VTH", "PIN_BIAS"):
        n = board.FindNet(name).GetNetCode()
        for t in board.GetTracks():
            if t.GetNetCode() != n:
                continue
            for px, py in ((RL.tomm(t.GetStart().x), RL.tomm(t.GetStart().y)),
                           (RL.tomm(t.GetEnd().x), RL.tomm(t.GetEnd().y))):
                if abs(px - cx) > 5.3 or abs(py - cy) > 5.3:
                    outside.append(name)
                    break
    out["rad_nets_outside_can"] = sorted(set(outside))
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

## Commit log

2026-07-10 Seed hardware repo: v0.1 build plan + draft-review audit + README
    - PLAN.md: v1 PCB build plan reconciled with the interrogator repo
    (USR contract binding, PCB gate #7 KPIs, PLAN §7.5.3.18 architecture,
    bench lessons as design rules) and July-2026 EDA tooling research.
    - docs/draft-review.md: audit of the original brief — what the repo adds,
    what 2026 research corrects (no blind/buried vias at JLCPCB -> 6-8L
    through-via + POFV; Freerouting/MCP trust boundaries; verified-library
    footprint path).
    - README.md: contract boundary + repo layout.
    Draft for owner review; Project 3 population deferred until ratified.
    Claude-Session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
2026-07-10 Reframe plan requirements-first: prototype is evidence, contract binds
    Owner direction: don't overfit to the breadboard prototype. Adds §0.1
    design stance; compute + sensor set become open H1 trade studies; size
    becomes an output of dynamic boundary co-optimization (§5.8) that defines
    the chassis; camera conditional on phone-attachability (D7); hardware DoD
    = spec scorecard, #7 becomes the joint integration checkpoint; firmware
    accommodations explicitly owned by the upstream project.
    Claude-Session: https://claude.ai/code/session_011EPEdgKHkVBaaR2g5HQUK8
2026-07-10 Full commercial redesign stance: chip-down BOM + reference architecture
    Owner direction: commercial hardware from scratch; interrogator adapts.
    - §0.1: chip-down, no breakouts/dev modules; positions taken, H1 validates
    - §5.1: recommended two-domain reference architecture (STM32N6-class app
    MCU w/ NPU+I3C+CSI; pre-certified nRF54L15-class BLE/sentinel module;
    i.MX RT1170 fallback, ESP32-P4 cost-down)
    - §5.7: raw-silicon sensor BOM (A121 chip not XM125, MAX30102EFD, BG51
    raw, GNSS module class as deliberate exception; ADS1115/MPR121 absorb
    candidates)
    - §5.10 new: DFM/DFT, certification path (W-CERT), battery safety,
    production programming, serviceability
    - D1/D2/H1/risks/Projec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
2026-07-10 Codify ratified change flow: sensor decided here -> device approved -> interrogator ingests
    Owner ratification 2026-07-10. Hardware originates sensor changes; the
    approved delta ships downstream as an ingest package (USR drafts, facets,
    AssetPins, interface delta) for firmware + interrogator to update against.
    Updates contract boundary (S3.3), sensor BOM (S5.7), regeneration (S6.3).
    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
2026-07-11 v0.2: incorporate owner review of 2026-07-11
    Silicon-on-merit (BNO085 stays, raw+fused per ADR-0014); interrogate/alert
    flow continuity (S3.6); concurrency & interference model (S5.2b); R2 covers
    actuators; R3 flexible w/ 5h floor; R13 unit economics; R14 wireless-first
    (BLE control + gated Wi-Fi/WebRTC-class) + USB-C PD fast charge + A/B OTA +
    feature gating; LFS dropped -> local + AWS S3 (D10); sensor market scan
    mandated (ENS161 example, D12); chassis buffer confirmed; sensor-MCP mission
    framing + P0 signal-fidelity principle; HIL learning loop (S6.5); CM
    manufacturing handoff package (S6.6); grounded prototype visual at H3.
    Claude-S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
2026-07-11 H0 foundations: pinned contract snapshot, ingest, asset manifest, CI, tests
    - contract/upstream: vendored USR snapshot (16 records) pinned to
    interrogator@881fbc1 (PIN.json; read-only, refresh = explicit pin bump)
    - contract/scripts/ingest.py: stage-1 ingest -> io_map.{json,md}; fails
    fast on schema/duplicate errors; flags all 16 pending electrical
    facets (USR-3) instead of masking them
    - assets/manifest_tool.py + manifest.json: AssetPin ledger (sha256,
    local/device now, S3-ready object_key per D10) seeded with the 24
    retrieved vendor files; verify subcommand
    - docs/MISSING_VENDOR_ASSETS.md: 26 proxy-blocked vendor files with
    exact URLs for manual retrieval
    - .github/workflows/ci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
2026-07-11 H1/H3-prelim: v1 board definition — grounded floorplan, envelope, power model
    54x40x1.6mm 6-layer, two-sided: sensing face (optical/air/contact/radar
    zones) + compute face (N657+NOR, BLE sentinel, WiFi, GNSS, power tree,
    per-segment load switches). Collision-checked placement from datasheet
    dims (DS) + verified research (RS); EST items flagged. Ambient 19.8mA ->
    ~61h on 1200mAh; interrogation 434mA -> ~2.8h. microSD dropped (NOR+
    phone sync). Outputs: components.json, floorplan SVGs, envelope.json,
    docs/power-budget.md.
    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
2026-07-11 H5-prelim: chassis v0 concept CAD (CadQuery) — STEP + 4 views
    62x47x17mm monolithic rounded shell around the computed envelope+buffer:
    optical window strip, contact/PPG dish, air inlet/outlet micro-hole
    arrays, USB-C slot, glow-ring light-pipe groove, buffered liquid-port
    blank. AirPods-case design language; signal apertures per exposure class.
    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
    [chassis_v0.step]
2026-07-11 H1 docs: BOM v1 verdicts, interface requirements, interference matrix v0
    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
    [interference-matrix.yaml]
2026-07-11 Prototype visual v1: self-contained HTML (board faces + chassis views + specs)
    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
2026-07-11 UX spec: modes, touch/air/liquid placement, 2 design deltas (ECG return electrode, mesh membrane)
    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
2026-07-11 Mounting decision (ADR-0001): ferrous target + external magnets, placed-monitor mode
    Solves weak in-pocket air sensing without an onboard magnet (which would blind
    MMC5983MA/TMAG5273). Steel target + accessory magnets; Hall-based dock detect;
    non-magnetic mounts for precision mag; optional dock charging. Chassis gains
    back-face target recess + lanyard hole.
    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
    [chassis_v0.step]
2026-07-11 Cross-contamination analysis: 9 channels, 3-layer mitigations; interference-matrix v1
    Full sweep of the v1 sensor set (optical crosstalk, thermal drift, siloxane
    poisoning, magnetic, GNSS RF desense, vibration, switching noise, light-into-
    radiation-detector, PM-vs-mesh). Adds channels v0 missed (GNSS desense, BG51
    light-tightness, chemical poisoning, PM/mesh conflict). Matrix v1 machine-
    readable for the scheduler with rule verbs + state flags.
    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
    [interference-matrix.yaml]
2026-07-11 Interference matrix downstream handoff: enforcement tiers + record-flag schema delta
    Tag every rule firmware_reflex/edge_policy/design_time so it self-routes to the
    right interrogator consumer; matrix ships via device-profile ref (single-sourced,
    not hardcoded). Specify the 4 new state flags (charging/docked/haptic_active/
    uv_active) as the ADR-0001 record-schema delta interrogator ingests.
    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
    [interference-matrix.yaml]
2026-07-11 Ingest-package spec: sensor change feeds semantics+specs+intents+fusion (AI context)
    Answers whether interrogator's spec/semantics YAMLs need feeding on sensor
    change: yes — USR record only POINTS to facets; semantics.yaml IS the AI
    meaning, specs.yaml the valid-range awareness, plus intents/fusion/flags.
    Draft-here / author-upstream split (HW=E0 datasheet facts, SME=E1/E2 meaning).
    Instantiates the v1 deltas + new intents each new sensor unlocks.
    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
2026-07-11 Flags/verbs routing verified vs upstream placeholders; bit assignments + semantics feed
    Confirmed upstream anchors (PLAN 5.3 matrix, record_schema activeFlags bitfield,
    sensor_semantics flags: section + NIR-LED confound pattern). Corrections: explicit
    bit positions 0x10-0x80 extending their bitfield; flags + victim-channel confound
    descriptions DO feed sensor_semantics.yaml (AI meaning); verbs stay scheduler-only;
    flag upstream schema/PLAN flag-list inconsistency for reconciliation.
    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
2026-07-11 BOM review: replacement trade-off ledger + candidate adds (SHT41, SCD41), ENS161 rationale
    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
2026-07-11 Reality coverage map: full sensor rundown, FDA capacity, gaps, vertical mapping, extension port
    25-sensor set (v1 core + medical/coverage adds) mapped to physical domains,
    diagnostic/regulatory ceiling (clearance-capable vs wellness vs env vs utility
    vs not-possible), 10 vertical markets, and the missing/impossible list. BG51 ->
    bare-PIN-on-precision-ADC recommendation (procurement) + SiPM Pro path for
    isotope ID. One magnetic pogo accessory interface for attachments (ECG/probes/
    wand) preserving sleekness. Spec-compliance check included. Doc + HTML artifact.
    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
2026-07-12 Design evolution: v1.1 board (ADR-0002) + form exploration + Product Stone (ADR-0003 rev C)
    - v1.1: 7 medical/coverage sensor adds, BG51->bare-PIN, pogo accessory port,
    zone-packer floorplan (60x46), updated power budget + chassis
    - Form exploration: Scanner (rejected), Puck/Pebble/Wand concepts, Pebble-Bean
    - Product Stone: owner design image canonical — 75x47x18mm engraved stone,
    parametric model + renders + STL (enclosure/product_stone.*)
    [chassis_scanner.step, chassis_v0.step]
2026-07-12 H2 stage-1: SKiDL circuit ERC-clean, netlist 330 parts/207 nets, library manifest, kicad-cli CI
    Full electrical design as circuit-code: 7 gated power domains, dual compute +
    NOR + C6/SDIO, SPI cluster w/ straps, collision-free dual-I2C address map,
    PIN-radiation chain, hardware UV interlock, pogo accessory port, ~50 testpoints.
    ERC 0/0 (waivers documented), tests 14/14, library 20/38 harvested + honest
    TO-GENERATE manifest. Adds .gitignore.
    [accessory.py, compute.py, lib_parts.py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]
2026-07-12 H2 stage-1 + ratifications: SKiDL circuit ERC-clean, netlist, library manifest, 3V3_SYS buck + 7th load switch
    Circuit-as-code: 7 gated power domains + accessory power, dual compute + NOR +
    C6/SDIO, SPI cluster w/ straps, collision-free dual-I2C map, PIN-radiation
    chain, hardware UV interlock, pogo port, ~50 testpoints. ERC 0/0, tests 14/14,
    kicad-cli 7.0.11 in CI, library 20/38 harvested + honest manifest. .gitignore.
2026-07-12 H2 stage-2: 38/38 footprints, bean board (67.9x39.9), first .kicad_pcb, VERIFY closures + BMV080 strap fix + 2 rail ECOs
    [interrogator_v1.kicad_pcb]
2026-07-12 H2.5: VERIFY closure round 2 — 11 items closed, 8 circuit bug clusters fixed, 9 footprints to E1; fetch round 3
    [accessory.py, compute.py, lib_parts.py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]
2026-07-12 H2.5: VERIFY closure round 3 — SGX-4CO real pin circle + sockets, LMP91000 + BL54L15 real pad maps
2026-07-12 H2.6: N657 real VFBGA142 ball map — routing unblocked; 5 power-tree bugs fixed; VL53L8CH/VD66GY closed
    [compute.py, lib_parts.py, main_sklib.py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]
2026-07-15 H3.1R/H3.2R: board-first minimal floorplan (ADR-0004) — bean containment removed, board rebuilt placement-true
    [interrogator_v1.kicad_pcb]
